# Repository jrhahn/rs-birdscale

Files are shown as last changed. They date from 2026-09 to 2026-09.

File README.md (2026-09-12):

# rs-smarthome-nodes

Async `no_std` Rust ([Embassy](https://embassy.dev)) firmware for a fleet of
**Seeed Studio XIAO ESP32-C3** smart-home sensor nodes. One image serves every
node: `NODE=<name>` at build time selects which sensors are populated, what the
node is called, and whether it runs on battery (deep sleep) or mains (always
on). Home Assistant picks the nodes up automatically over **MQTT
auto-discovery** — no hand-declared entities.

It started as a battery bird-feeder scale, which is still the default node
(`NODE=terrasse`): on each wake-up it reads a load cell via an HX711 amplifier
and compares it against a tare baseline kept in RTC RAM. While the feeder is
empty it polls every couple of seconds from **light** sleep — no radio, and no
cold boot per poll — which bounds how short a visit it can see at all. The
amplifier is powered down between those polls, and its settling time after
power-up is waited out asleep rather than awake. Once weight crosses the threshold it
stops sleeping and **watches the visit through awake**, so the published weight
is a settled median rather than whichever conversion happened to land first, and
the visit gets a real duration instead of one rounded to the sleep interval;
then it brings up Wi-Fi and publishes once (grams converted on-device). A
periodic **heartbeat** (default every 10 min) publishes anyway, so
Home Assistant always has a fresh reading. While online it also pulls any
retained calibration/tuning back from Home Assistant and persists it to flash.

```
┌──────────┐  bit-bang   ┌────────┐    Wi-Fi/MQTT (grams, °C)   ┌────────────────┐
│  Load    │────────────▶│ HX711  │──▶ ESP32-C3 ───────────────▶│ Home Assistant │
│  Cell    │  DT / SCK   │ 24-bit │       smarthome/terrasse/weight    │                │
└──────────┘             └────────┘   ◀── config/* (retained) ──│  (calibration) │
   DS18B20 ─ 1-Wire ─────────────────▶     grams + tuning       └────────────────┘
   SHT31-D / SCD41 ─ I²C ────────────▶  homeassistant/… (discovery, retained)
   SDS011 ─ UART ────────────────────▶
```

## The fleet

Pick a node with `NODE=` at build time (`src/node.rs`); an unknown name fails
the build rather than flashing the wrong personality onto a board. A board can
also be **provisioned** to another identity afterwards, without a rebuild — see
[below](#provisioning-a-board).

| `NODE=` | Room | Sensors | Power |
| --- | --- | --- | --- |
| `terrasse` (default) | Terrasse | HX711 load cell + SHT31-D + cell voltage | battery, deep sleep |
| `schlafzimmer` | Schlafzimmer | SCD41 + SHT31-D | mains |
| `wohnzimmer` | Wohnzimmer | SCD41 + SHT31-D + SDS011 + SGP41 | mains (fan) |
| `kueche` | Küche | SHT31-D | mains |
| `bad` | Bad | SHT31-D | mains |
| `terrasse` | Terrasse | none yet — the board is on the network while it is wired up | battery, deep sleep |

### Provisioning a board

The `NODE=` value is only the identity a board *starts* with. To repurpose one —
or to flash the whole fleet with a single image and sort out which is which
afterwards — publish its node name **retained** to the board's provisioning
topic, which is keyed by MAC (the one name a board knows before it knows
anything else) and printed on every boot:

```
node 'terrasse' (Terrasse) booted, battery profile
provision topic: smarthome/provision/a1b2c3d4e5f6
```

```bash
# Tell that board it is the kitchen node
mosquitto_pub -h <broker-ip> -r -t smarthome/provision/a1b2c3d4e5f6 -m kueche

# …and back to whatever it was flashed as
mosquitto_pub -h <broker-ip> -r -t smarthome/provision/a1b2c3d4e5f6 -m default
```

The node picks the message up the next time it is online for a publish, stores
the name in flash and restarts into it — the sensor set decides which buses come
up, so becoming a different node means a reboot. The message being retained is
the point: a battery node that is asleep gets it whenever it next wakes. It is
re-delivered on every connect, so the firmware only writes flash when the value
actually changes, and an unknown name is logged and ignored rather than obeyed.

The identity lives in its own flash sector, separate from the calibration blob —
provisioning a board never disturbs its tare or scale factor.

**Power profiles** decide the loop: *battery* nodes cold-boot out of deep sleep,
measure, publish only when there is something to say, and sleep again. *Mains*
nodes stay associated and sample on a fixed per-node cadence — CO₂ continuity
and the SDS011's duty-cycled fan both rule out deep sleep. A sensor whose own
cadence is slower than the node's round says so per slot (`Slot::every`), which
is how `wohnzimmer` reads CO₂ every minute while its fan runs four times an
hour. On a battery node the
`config/deep_sleep` switch can still hold it awake for bench testing.

## Hardware

| Component | Detail |
| --- | --- |
| MCU | Seeed XIAO ESP32-C3 (RISC-V, external Wi-Fi ant.)  |
| Battery | 2000 mAh LiPo via the XIAO's onboard charger |
| Sensor | 1 kg straight-bar load cell (tension S-config) |
| Amplifier | HX711 24-bit ADC |
| Temperature | DS18B20 waterproof 1-Wire probe (stainless steel) |
| T / RH | SHT31-D breakout, I²C `0x44` |
| Cell voltage | 100 kΩ/100 kΩ divider + 100 nF on ADC1 |
| CO₂ / T / RH | SCD41 breakout, I²C `0x62` |
| PM2.5 / PM10 | SDS011, UART 9600 8N1, **5 V supply** (fan) |

### Pin map (XIAO ESP32-C3 silkscreen → GPIO)

| Pad | GPIO | Use |
| --- | --- | --- |
| D0  | 2  | HX711 SCK |
| D1  | 3  | HX711 DT |
| D2  | 4  | DS18B20 1-Wire (4.7 kΩ pull-up to 3V3) **or** battery divider tap (ADC1) |
| D3  | 5  | SDS011 UART RX ← sensor TX |
| D4  | 6  | I²C SDA (SHT31-D + SCD41) |
| D5  | 7  | I²C SCL |
| D10 | 10 | SDS011 UART TX → sensor RX |

The two I²C sensors share one bus (their addresses do not clash), and on
`wohnzimmer` that bus runs alongside the SDS011's UART — the only node using
both. The SDS011 deliberately avoids D6/D7 (GPIO21/20), which are the console
UART pads the log output uses.

D2 has two possible jobs and can only do one of them: the DS18B20's 1-Wire line,
or the battery divider's tap. ADC2 is unusable while Wi-Fi is up, and of the
ADC1 pins only D0/D1/D2 are broken out on this board — the first two are the
HX711's — so cell voltage costs the probe its pin. `NODE=terrasse` takes that
trade; the build fails if a node table entry ever asks for both.

### Wiring (load cell → HX711)

The four load-cell leads go to the HX711's **input** side. Colours follow the
common straight-bar convention — verify against your cell's datasheet, as they
do vary.

| Load-cell lead | HX711 pin | Meaning |
| --- | --- | --- |
| Red | E+ | excitation + |
| Black | E− | excitation − |
| Green | A+ | signal + |
| White | A− | signal − |

> If loading the cell makes the reading go *down* instead of up, swap A+/A− (or
> flip the comparison in firmware — the threshold itself is the runtime
> `threshold` config value, see below).

### Wiring (HX711 → XIAO ESP32-C3)

On the XIAO ESP32-C3 the silkscreen pads map **D0 = GPIO2, D1 = GPIO3,
D2 = GPIO4** (GPIO0/GPIO1 are *not* broken out on this board).

| HX711 pin | ESP32-C3 pin | Direction |
| --- | --- | --- |
| VCC | 3V3 | — |
| GND | GND | — |
| SCK (clk) | GPIO2 / D0 | output |
| DT (data) | GPIO3 / D1 | input |

### Wiring (DS18B20 → XIAO ESP32-C3)

The probe's three leads are the usual DS18B20 colours. The data line is an
**open-drain 1-Wire bus** and needs a **4.7 kΩ pull-up from DATA to 3V3**
(the MCU's weak internal pull-up is enabled as a backup, but the external one
is required for a reliable read over the ~1 m cable).

| DS18B20 lead | ESP32-C3 pin | Direction |
| --- | --- | --- |
| Red (VCC) | 3V3 | — |
| Black (GND) | GND | — |
| Yellow (DATA)  | GPIO4 / D2 | 1-Wire (+ 4.7 kΩ to 3V3) |

The temperature is read whenever a weight reading is being published — on a bird
visit, and on the periodic **heartbeat** (see below) — so the ~750 ms conversion
never runs on the low-power idle-poll cycles. It is published to
`smarthome/terrasse/temperature` in °C.

**No node ships with this today.** The outdoor node traded its probe for the
battery sense below; the DS18B20 slot and driver stay, because the pin is a
per-node choice rather than a firmware one.

### Wiring (battery divider → XIAO ESP32-C3)

The XIAO charges a cell but cannot measure one: `B+` reaches the charger and the
regulator, never an ADC. An external divider from the battery rail to ground
gives ADC1 something to read.

| Component | From | To |
| --- | --- | --- |
| R1 100 kΩ | XIAO `B+` | tap |
| R2 100 kΩ | tap | XIAO `GND` |
| C 100 nF | tap | XIAO `GND` |
| wire | tap | GPIO4 / D2 |

Two details are not optional. The divider's foot goes to the **XIAO's ground**,
which on a node with a 1S protection board is the `P−` (load) side — there the
board's cutoff switches the divider off with everything else, where wiring it
straight to the cell's own `B−` would keep drawing ~21 µA past the cutoff and
deep-discharge the pack the protection was fitted to save. And the DS18B20's
4.7 kΩ pull-up must come **off** the pin: it would drag the tap towards 3V3.

Conversions are calibrated against the chip's eFuse reference, so the driver
works in millivolts; the divider ratio is undone in
[`src/battery.rs`](src/battery.rs). That corrects the ADC, not the resistors —
use 1 % parts, and trim `R_TOP_KOHM` / `R_BOTTOM_KOHM` and reflash if a
multimeter disagrees. Published to `smarthome/terrasse/battery_voltage` in volts. Below
3.0 V the log says so: the common DW01A-class protection board does not cut off
until ~2.4 V, far past where a LiPo starts losing capacity for good.

## Enclosure

[`models.py`](models.py) is the CadQuery source for the printed parts: four
enclosures in eight pieces, plus the two bending-beam clamps the bird scale hangs
from. The clamps the file *started* as were retired in `f858d60` and are not
these — `git show d0df819:models.py` still has the originals, which put the wire
hole where the bar puts it rather than on the box's centre line.

```bash
nix develop .#cad        # separate shell: OpenCASCADE is ~500 MB, cargo has no use for it
python models.py         # writes cad-models/*.stl and *.step
```

CadQuery is not in nixpkgs (only the `opencascade-occt` kernel, without the
Python bindings), so the shell pins the wheels and installs them into
`.venv-cad` on first entry (ignored). The exports under `cad-models/` are
tracked, so printing a part does not require the toolchain at all — `.stl` to
slice, `.step` to open in CAD.

### `terrasse_body` + `terrasse_floor`

An **88 × 78 × 60 mm** box for the bird scale, in two parts. The size is not a
choice — it comes from the measured envelopes, plugs included:

| | | | |
|---|---|---|---|
| ESP32-C3 board | 40 × 30 × 35 | HX711 board | 40 × 25 × 30 |
| battery | 65 × 50 × 10 | SHT31 | 20 × 10 × 10 |

That is 128 cm³ with clearance. The first version of this box had a 98 cm³
interior, so no amount of rearranging would have done it; a grid packing search
puts the smallest interior that takes all four at 76 × 66 × 52, and only with
everything stood on end. This one is 80 × 70 × 55, which leaves room for the
mounts themselves.

The design follows from it hanging outdoors in the rain:

- **The roof has no seam and no penetration.** The box is a cup opening
  *downward*; the only joint faces the ground, where water cannot climb to it.
  The top 5 mm flare 2 mm past the walls as an eave, so water crossing the roof
  drips clear instead of running down the sides. Nothing is drilled through the
  top — the cord attaches to two round-ended tabs *outboard* of the walls,
  which is why the part reaches 108 mm across.
- **The SHT31 lives in the −X/−Y corner, no longer behind a wall.** Air enters
  through floor slots beneath it and leaves through slots high in *both*
  adjacent walls, tilted 30° down-and-out — every opening faces down or
  outward-down, so there is still a local draught across the sensor.

  There *was* a baffle around it, and it came out because the cable could not
  be got past it during assembly: the slot was widened, then run full height,
  and it still fouled. That costs accuracy, since the board's heat now shares
  the sensor's air — about 0.9 °C on the bedroom node. A box that cannot be
  assembled is worse than one that reads half a degree warm, but keep the SHT31
  in that corner rather than beside the board, or the loss compounds.
- **The floor screws go into M3 heat-set inserts**, Ø4 bores in 9 mm posts,
  which leaves 2.5 mm of wall — thinner than one would choose, and what the
  already-printed floor plate allows.

  The screw positions are not free: they are where the 8 mm post this box
  shipped with put them, and the plate in hand has its countersinks there. So
  the post has to grow *around* a fixed hole, and it meets two features of that
  same plate — the cell reaches x = 31 and the battery guides reach y = ±26.
  Nine millimetres leaves 0.5 mm to both; ten does not fit. The plate's HX711
  rib still fouled one post by 0.5 mm, so that post is relieved there rather
  than shrunk: the rib only has to slide past, the wall has to survive brass
  being melted into it. Warm the inserts properly and do not lean on them; if
  one splits, the way out is a reprinted floor with the holes further in, which
  buys 3.5 mm.
- **The load hangs off a pad on the underside of the floor**, matching the
  clamp's 25 × 12 face and its screw pitch, with captive nuts reachable from
  inside the box.

### `terrasse_beam_spacer` + `terrasse_beam_hanger`

The two clamps that pad exists for. The **spacer** bolts up into the floor's
captive nuts and carries the bar's fixed end; the **hanger** grips the load end,
and the wire leaves from its far end.

Two parts rather than one, because both ends of the bar share the anchor's 15 mm
screw pitch — a single pair of screws cannot fasten the box and the bar at once.
The spacer offsets the fixed end until the pairs clear. `BEAM_DIR` decides which
way the bar runs from there; flipping its sign mirrors the whole assembly, and
since every feature sits on `y = 0`, an already-printed part just turns round.

The hanger is 80 mm, the bar's own length, with the M5 bolts at one end and the
wire hole at the other, **61.5 mm apart**. The wire leaving from the far end is
a requirement — it is where the feeder hangs — and the section is dimensioned
for it rather than around it.

What follows is a cantilever in the load path, which is why the **spine** is the
deep part at 14 mm and not the pad: stiffness goes with depth cubed. Deflection
here is an accuracy problem rather than a strength one — what bends does not
spring back exactly, and that shows up as hysteresis in the weight. If readings
ever differ between a loaded and an unloaded pan, deepen `RAIL_T` before
suspecting anything in the firmware.

> **Nothing but the bar may bridge the two clamps.** Only the hanger's pad
> touches the bar; the spine runs 4 mm clear of it along its whole length and
> 16.7 mm clear of the spacer. If anything touches, the load path goes around
> the strain gauges and the scale reads a fraction of the weight — or none of
> it — without any sign that something is wrong.

**Printing.** The pad reaches down to the rail's underside rather than standing
proud of it, so there is one flat face across all 80 mm and a single 4 mm step
on top — a step *up*, overhanging nothing. The only downward faces off the bed
are the two counterbore ceilings, 112.9 mm² of bridge over a 5.3 mm hole. No
support. The pad is 18 mm thick as a result, so the bolts want to be **M5 × 16**.

Calibrate in the fixture: `scale_factor` is what absorbs whatever the mounting
does to the sensitivity.

## Wi-Fi credentials without a rebuild

A board that cannot join the network cannot be told anything over the network,
so the way in is the serial console. On a **cold boot** — power actually removed
and reapplied, not a deep-sleep wake and not a reflash — the firmware listens
briefly:

```
wifi: 'your-ssid' (built in)
wifi: no usable credentials; waiting for the console
wifi provisioning: ssid <name> / psk <passphrase> / save / clear / show / done
```

Type into the same serial monitor you are watching the logs in:

```
ssid MyNetwork
psk correct horse battery staple
save
```

The board stores them in its own flash sector — separate from the calibration
and the node identity — and restarts into them. `clear` forgets them and returns
to the credentials the image was built with; `show` reports the SSID and the
passphrase's length (never its content); `done` carries on booting.

The window is 3 s when the board already has usable credentials, and 2 minutes
when it has none, since then it has nothing else to be doing. A passphrase may
contain spaces. If stored credentials are refused three times in a row, the
board falls back to the build-time pair for the rest of that run, so a typo
cannot strand it permanently.

## Tests

A firmware binary for `riscv32imc` cannot host a test harness, so the crate is
split: [`src/lib.rs`](src/lib.rs) holds everything the binary is made of, and
the parts that are **pure computation** — frame decoding, CRCs, the flash blob
layouts, `Config::apply`, the discovery payloads, the node table — build without
the HAL and therefore run on the host.

```bash
# What CI runs
cargo test --no-default-features --features host-tests \
    --target x86_64-unknown-linux-gnu
```

The sensor drivers themselves are covered too. They are generic over the
`embedded-hal-async` / `embedded-io-async` bus traits, so
[`src/sensors/mock.rs`](src/sensors/mock.rs) can feed the *real* SHT31, SCD41
and SDS011 drivers a scripted bus: canned I²C replies, and a UART that hands
over stale frames, falls quiet, then delivers the frame that matters. That
covers the resync, the CRC rejection, the fan duty cycle, the SCD41's two run
modes and its data-ready handshake, and what happens when a sensor is absent —
but not timing, bus contention or anything electrical, which stay bench
questions.

Anything that touches the chip itself — RTC RAM, flash, the radio, the bit-bang
drivers — sits behind the `hal` feature (on by default), so a normal
`cargo build` is unaffected. Compile-time
`const _: () = assert!(…)` checks stay where they are: they cost nothing and
fail the *build*, which is stronger than a test — the tests cover what
const-eval cannot reach, such as anything that formats a string, negative cases,
and inputs enumerated in a loop.

[CI](.github/workflows/ci.yml) runs the tests, both clippy passes, and builds
every node in the fleet — plus a check that a mistyped `NODE=` still fails the
build.

## Home Assistant integration

Each node **announces itself**: on the first connect after a power-up it
publishes one retained config message per reading to
`homeassistant/sensor/<node>/<key>/config`, so Home Assistant creates the device
and its entities without any YAML. Values are ready to use — grams, °C, %, ppm,
µg/m³ — with no template maths.

| Node | State topics |
| --- | --- |
| `terrasse` | `smarthome/terrasse/weight`, `/temperature`, `/humidity` (SHT31-D), `/battery_voltage` — each appearing as its slot is switched on |
| `schlafzimmer` | `smarthome/schlafzimmer/co2`, `/temperature`, `/humidity` (SHT31-D), `/scd41_temperature`, `/scd41_humidity` |
| `wohnzimmer` | the same five, plus `/pm25`, `/pm10` (humidity-corrected), `/pm25_raw`, `/pm10_raw` and `/voc_index`, `/nox_index` |
| `kueche` / `bad` | `smarthome/<node>/temperature`, `/humidity` |

No node mirrors a weight to a second topic any more. The outdoor node used to,
under `birds/scale/state`, for hand-declared entities that predated discovery.
That topic and the whole `birds` namespace went when it was renamed to
`terrasse`.

**Availability.** A mains node registers an MQTT last will, so the broker
publishes retained `offline` to `<namespace>/<node>/status` the moment its
connection breaks (and the node publishes `online` on connect, disconnecting
cleanly at the end of a round so a normal publish is never mistaken for a
death). Battery nodes get no will — they are supposed to be offline between
readings — so every node also carries `expire_after` in its discovery config:
three missed publish rounds and Home Assistant invalidates the values.

The tuning/calibration knobs are *commands* rather than readings, but they are
discovered too — as `number`, `switch` and `button` entities in the device's
*Configuration* section — so a node needs no hand-written Home Assistant YAML at
all. See [`home-assistant/README.md`](home-assistant/README.md).

### Configure & calibrate from Home Assistant

Calibration (`offset`, `scale_factor`) and tuning (`threshold`, poll intervals)
are **stored on the controller in flash** and set from Home Assistant — no
reflashing. HA publishes each value **retained** to
`<namespace>/<node>/config/<key>` (`smarthome/terrasse/config/<key>` for the scale);
the firmware reads them the next time it is online for a publish (while a bird is
on / has just left the scale) and persists them. Changes therefore apply with a
**short delay**, not instantly.

| HA entity → topic (`smarthome/terrasse/config/…`) | Meaning | Node |
| --- | --- | ---- |
| `offset` | raw HX711 value at 0 g (tare zero) | with load cell |
| `scale_factor` | raw ticks per gram | with load cell |
| `threshold` | grams that count as "a bird landed" | with load cell |
| `tare` (button) | re-zero: adopts the current empty baseline as `offset` | with load cell |
| `idle_interval` | deep-sleep seconds while empty | battery |
| `active_interval` | deep-sleep seconds for a load that outlasted its awake visit window (snow, a twig) — a normal visit is watched awake and never uses this | battery |
| `heartbeat_interval`| seconds between periodic temp + weight publishes with no visitor (default 600) | battery |
| `deep_sleep` (switch)  | `0` = stay awake with Wi-Fi up (bench testing on USB), `1` = normal battery deep sleep | battery |
| `scd41_temp_offset` | °C the SCD41 subtracts for its own self-heating (default 4.0) | with SCD41 |
| `sds011_kappa` | κ for the PM humidity correction, `0` disables it (default 0.25) | with a compensated SDS011 |

Only the knobs that do something on a given node are announced: a mains node
samples on its build-time cadence and never sleeps, so it gets none of them.
Pressing **Tarieren** publishes a retained press (the node may be asleep) which
the firmware deletes once it has re-zeroed, so it is never replayed as a second
tare.

On a blank flash the firmware falls back to built-in defaults
(`src/config.rs` — `offset` mid-scale, `scale_factor` 420, `threshold` 10 g,
2 s / 10 s idle/active intervals, 600 s heartbeat).

**Calibrating `scale_factor`:**
1. **Tare** with the pan empty (sets `offset`). The empty-pan raw value is also
   visible in the serial monitor (`HX711 raw reading: N`).
2. Place a known mass `m` and read the published grams / raw value.
3. `scale_factor = (raw_loaded − offset) / m`; enter it in the *Kalibrierfaktor*
   number. Re-check and adjust until the reading matches.

## Long-term history

Home Assistant sees every node the moment it publishes, and keeps a recorder
database — tuned for weeks. The questions this fleet was built for are slower
than that: did insulating the roof change the bedroom's overnight CO₂, how does
the terrace swing between summers, is the feeder busier this year than last.

[`timeseries/`](timeseries/README.md) is a second consumer on the same broker
whose only job is not to lose anything. It follows the topics the nodes already
publish, writes each reading into **QuestDB** with a **three-year retention**,
maintains three cascading rollup views (`_1m` → `_1h` → `_1d`) so a year-wide
chart reads thousands of rows instead of millions, and serves a small dashboard
that routes each query to the coarsest view still fine enough to answer it.

```bash
nix develop .#timeseries
cd timeseries && cargo run -- timeseries.example.toml   # then http://127.0.0.1:8087
```

It changes nothing about the firmware or the Home Assistant side — a node does
not know it is being archived. The flake carries a package and a NixOS module
(which brings up QuestDB too, since nixpkgs ships the package but no service)
for the home server; see [`timeseries/README.md`](timeseries/README.md) for the
schema, the rollup reasoning, and how to deploy it.

## License

MIT — see [LICENSE](LICENSE).

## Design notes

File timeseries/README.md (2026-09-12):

# `smarthome-timeseries`

The fleet's long-term memory: one process that follows the MQTT topics the
nodes already publish, writes every reading into **QuestDB** with a **three-year
retention**, and serves a small dashboard that reads it back.

```
┌──────────┐   smarthome/<node>/<key>   ┌───────────────┐   ILP/HTTP   ┌──────────┐
│  nodes   │───────────────────────────▶│   this        │─────────────▶│ QuestDB  │
│ (ESP32)  │   homeassistant/…/config   │   service     │◀── SQL ──────│ readings │
└──────────┘───────────────────────────▶│               │              │ + 3 views│
                                        └───────┬───────┘              └──────────┘
      ┌────────────────┐                        │  HTTP :8087
      │ Home Assistant │◀── same broker ────────┘  charts, live values, health
      └────────────────┘
```

Nothing here touches the firmware or Home Assistant's configuration. A node does
not know it is being archived; switching this off leaves the house working
exactly as before.

## Why it exists

Home Assistant already sees every node — the firmware announces itself over MQTT
auto-discovery — and it keeps a recorder database. What it does not keep is
*years*. Its recorder is tuned for weeks, and the questions this fleet was built
to answer are the slow ones: did insulating the roof change the bedroom's
overnight CO₂, how does the terrace swing between summers, is the bird feeder
busier this year than last.

So: a second consumer on the same broker, whose only job is not to lose
anything.

## What it stores, and what it does not

The firmware's topic layout is the entire schema:

| Topic | Stored as |
| --- | --- |
| `smarthome/<node>/<key>` | a row in `readings` |
| `smarthome/<node>/status` | a row in `node_status`, **on change only** |
| `smarthome/<node>/config/<key>` | nothing — a setting, not an observation |
| `smarthome/provision/<mac>` | nothing — an instruction |
| `homeassistant/sensor/<node>/<key>/config` | nothing; read for units and names |

Two details that are easy to get wrong, and are tested:

- **`provision` is not a node.** `smarthome/provision/a1b2c3d4e5f6` has the same
  three segments as a reading, and would otherwise be archived as a node called
  `provision` with a sensor called `a1b2c3d4e5f6`.
- **A retained reading is not a new reading.** The broker replays retained
  messages when this service subscribes, and the only timestamp available here
  is "now" — so a replay would stamp an old value as current. Readings arriving
  with the retain flag are skipped. This does not affect live publishes: MQTT
  clears the flag on messages delivered to an already-subscribed client, so a
  node publishing retained data is still archived normally.

Timestamps are when the bridge received the message. The nodes send none of
their own — they are `no_std` boards without a clock — and on a broker on the
same LAN the gap is milliseconds.

## The database

```sql
readings(timestamp TIMESTAMP, node SYMBOL, sensor SYMBOL, value DOUBLE)
  TIMESTAMP(timestamp) PARTITION BY DAY TTL 3 YEARS
```

plus three cascading materialized views, each aggregating the next finer one:

| View | Bucket | Reads | Partition |
| --- | --- | --- | --- |
| `readings_1m` | 1 minute | `readings` | day |
| `readings_1h` | 1 hour | `readings_1m` | month |
| `readings_1d` | 1 day | `readings_1h` | year |

Each stores `min`, `max`, `sum` and `count` per channel per bucket. The mean is
re-derived at read time as `sum(sv)/sum(n)` — the exact mean of the underlying
readings, not an average of averages that would weight a sparse hour (node
asleep, one reading) like a full one.

**Why cascade.** QuestDB refreshes a view by re-aggregating the buckets the new
rows touched. A daily view built directly on the base table therefore re-scans
the whole current day on every commit, for ever. Built on the hourly view it
re-reads twenty-four rows per channel.

**Why not timers.** The gateway firmware puts its coarse tiers on `REFRESH EVERY
5m` / `1h`, because at 100 Hz ingest an immediate refresh of every tier is what
pegged three CPU cores. This fleet publishes about one reading a minute per
channel, so there is nothing for a timer to save — and on QuestDB 9.3.5 a
timer-refreshed view created over a source that was still empty did not pick up
2160 rows inserted into that source over the following twenty minutes. That is
exactly the shape of a first install. Every tier here is `REFRESH IMMEDIATE`.

**Retention** is a QuestDB table TTL, applied to the base table and to every
view, and re-applied on each start — so changing `retention` in the settings
file is enough to change it on a table that already exists. QuestDB drops data a
whole partition at a time, which is why the setting must be a whole number of
days or coarser.

## Reading it back

`GET /api/series?node=…&sensor=…&from=…&to=…&points=…` picks a bucket from a
fixed ladder (1s … 30d), then routes the query to the **coarsest view whose
bucket is still fine enough**. Below a minute, and whenever a view is missing,
it reads the base table. The response is identical either way — `lo`, `hi`, `av`
per bucket — so the chart never branches on where the numbers came from.

Two things make that promise literal rather than approximate:

- The window is **widened to whole buckets** before querying. Ask for "the last
  365 days" at a daily grain and the window starts mid-day: the raw table would
  answer with a partial first bucket while the daily view's row for that day
  starts before the window and is filtered out entirely. Rounded out, both
  answer with the same full bucket.
- A rollup that returns nothing is **retried against the base table**, so a view
  that is somehow behind shows the truth rather than a blank chart.

This is checked against a live database rather than asserted: see the smoke test
below, which compares every zoom level against a full scan of the raw table.

| Endpoint | |
| --- | --- |
| `GET /` | the dashboard (three embedded files, no CDN, no build step) |
| `GET /api/channels` | every channel, with unit, display name and last value |
| `GET /api/series` | one chart |
| `GET /api/health` | broker and database reachability, rollups, counters |

## Configuration

One TOML file, every field optional — see
[`timeseries.example.toml`](timeseries.example.toml). Defaults assume a broker
and a QuestDB on localhost. Passwords can come from `password_file` so they stay
out of the file (and, on NixOS, out of the store).

## Building and running

The firmware's toolchain pin does not apply here; this crate has a
`rust-toolchain.toml` of its own and a `.cargo/config.toml` that undoes the
riscv32 default.

```bash
nix develop .#timeseries      # nixpkgs rustc, plus questdb and mosquitto
cd timeseries
cargo test                    # 75 tests, no database needed
cargo clippy --all-targets -- -D warnings
cargo run -- timeseries.example.toml
```

### The end-to-end smoke test

The unit tests cover the parts that are pure computation — topic classification,
ILP formatting, DDL shape, tier routing, bucket snapping. What they cannot cover
is whether QuestDB accepts any of it. That needs a real database:

```bash
# a QuestDB and a broker of their own, on ports nothing else uses
mkdir -p /tmp/ts-smoke/qdb/conf
cat > /tmp/ts-smoke/qdb/conf/server.conf <<'EOF'
http.bind.to=127.0.0.1:19000
http.min.net.bind.to=127.0.0.1:19003
pg.net.bind.to=127.0.0.1:18812
line.tcp.net.bind.to=127.0.0.1:19009
EOF
questdb.sh start -n -d /tmp/ts-smoke/qdb &
printf 'listener 11883 127.0.0.1\nallow_anonymous true\n' > /tmp/ts-smoke/mosquitto.conf
mosquitto -c /tmp/ts-smoke/mosquitto.conf &

# then point a settings file at 11883 / 19000 and run the service against it,
# publish with mosquitto_pub, and compare a rollup-answered chart against a
# full scan of the base table.
```

Doing exactly that is what turned up the two edge cases the code now handles
(partial buckets at a window's edge, and coarse views left empty by a timer).

## On the home server

The flake exposes a package and a NixOS module. The module also brings up
QuestDB itself, because nixpkgs ships the package but no service:

```nix
{
  inputs.smarthome-nodes.url = "github:jrhahn/rs-smarthome-nodes";

  # in the host's configuration:
  imports = [ inputs.smarthome-nodes.nixosModules.smarthome-timeseries ];

  services.smarthome-timeseries = {
    enable = true;
    settings = {
      mqtt.host = "127.0.0.1";       # the broker Home Assistant already uses
      questdb.retention = "3y";
      web.bind = "127.0.0.1:8087";
    };
    # Kept out of the store; systemd hands it over as a credential.
    mqtt.passwordFile = "/run/secrets/mqtt-password";
  };
}
```

The archiver runs as a `DynamicUser` with no state of its own. QuestDB gets a
static user and `/var/lib/questdb`, which is **the one directory worth backing
up** — it holds the data, the write-ahead log and the configuration.

Both QuestDB ports bind to loopback by default. That is deliberate: QuestDB's
HTTP interface serves ingestion, arbitrary SQL *and* a web console, none of it
authenticated.

> **Upgrades are one-way.** QuestDB's storage format only moves forward: a data
> directory written by one version cannot be opened by an older one, so rolling
> the package back after an upgrade does not roll the data back with it.

## Operations

**Change the retention.** Edit `questdb.retention`, restart. The service issues
`ALTER TABLE … SET TTL` on every start, for the base table and for every view.

**Look at the data directly.** QuestDB's console is on port 9000 (loopback, so
over an SSH tunnel), and the PostgreSQL wire protocol on 8812 for anything that
speaks it — Grafana, `psql`, a notebook.

**After changing a view's definition** in `rollup.rs` or `schema.rs`: the DDL is
`IF NOT EXISTS`, so an existing view is left alone. Drop the affected views
(coarsest first) and restart; they backfill from the history on creation.

```sql
DROP MATERIALIZED VIEW readings_1d;
DROP MATERIALIZED VIEW readings_1h;
DROP MATERIALIZED VIEW readings_1m;
```

**If a view is ever behind**, `REFRESH MATERIALIZED VIEW readings_1h INCREMENTAL`
catches it up without a full rebuild. `SELECT view_name, view_status,
refresh_base_table_txn, base_table_txn FROM materialized_views()` is how to tell.

## How long to keep it, and what that costs

Measured rather than guessed, and written up in
[`docs/long-term-history.md`](../docs/long-term-history.md): the fleet produces
~25,900 readings a day, a finished daily partition of exactly that shape came to
**828 KB**, and three years of raw data is therefore under a gigabyte. That page
also argues why the rollups should outlive the raw table rather than expire with
it, and what threatens a long series once storage has stopped being the problem.

## Limits worth knowing

- **Readings are lost if the database is unreachable for a long time.** The
  writer retries a failed batch on the next flush and keeps up to 100 000 rows
  buffered — over a day of this fleet's output — then drops the backlog with a
  loud log line rather than growing until the machine swaps.
- **No authentication on the dashboard.** It is read-only and binds to
  loopback; anything more is the reverse proxy's job.
- **The service does not create the MQTT user.** It is a normal client; give it
  read access to `smarthome/#` and `homeassistant/#`.

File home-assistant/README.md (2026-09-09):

# Home Assistant

**Nothing here needs merging into `configuration.yaml` any more.**

Every node announces itself over retained MQTT discovery on its first connect
after a power-up — both directions:

- the **readings** become `sensor` entities (weight, temperature, humidity, CO₂,
  PM2.5/PM10);
- the **calibration and tuning knobs** become `number` / `switch` / `button`
  entities, filed under the device's *Configuration* section.

Adding a node to the fleet therefore needs no change on the Home Assistant side
at all. The only requirement is the MQTT integration with discovery enabled (the
default) on the `homeassistant/` prefix.

## What each node exposes

Controls are per node, so nothing dead shows up on a device card:

| Control | Entity | On which node |
| --- | --- | --- |
| `threshold` | number, g | nodes with a load cell (`terrasse`) |
| `scale_factor` | number | nodes with a load cell |
| `offset` | number | nodes with a load cell |
| `tare` | button | nodes with a load cell |
| `idle_interval` | number, s | battery nodes |
| `active_interval` | number, s | battery nodes |
| `heartbeat_interval` | number, s | battery nodes |
| `deep_sleep` | switch | battery nodes |

The mains nodes have no tunables today: their sampling cadence is a build-time
per-node value (`sample_secs` in `src/node.rs`) and they never sleep.

**Changes apply with a delay.** The controls publish **retained** to
`<namespace>/<node>/config/<key>`, and the firmware only reads that topic while
it is online for a publish — on the scale, the next bird visit or heartbeat. The
broker holds the value until then; the node persists it to flash once it has it.

The controls also *read their state back off their own command topic*, which is
why they show the last value you set even after a Home Assistant restart. They
show what was last commanded, which is not proof the node has picked it up yet.

## Calibrating the scale

Two points, in this order:

1. **Zero.** With the pan empty, press **Tarieren**. The node adopts its current
   empty baseline as `offset` on its next online cycle. (`offset` is also
   editable by hand, if you would rather type the raw HX711 value.)
2. **Span.** Put a known weight on the pan and wait for a reading. If it shows
   `w_shown` grams instead of the true `w_true`, multiply `scale_factor` by
   `w_shown / w_true` and set the result. Repeat once if it is still off.

`scale_factor` is raw HX711 ticks per gram, so it is only valid for the exact
mechanical mounting it was calibrated on — re-do the span after any change to
the load cell's fixture. The zero drifts with temperature and creep, so re-tare
occasionally; the firmware also tracks slow baseline drift by itself.

## Example dashboard card

Add to a dashboard (Raw configuration editor). Entity ids follow from the node
name Home Assistant assigns the device — adjust if yours differ. The `title:`
lines are just card headings, not entities: if one turns up in a dashboard and
is not wanted, it is this YAML that put it there, not the firmware.

```yaml
type: vertical-stack
cards:
  - type: entities
    title: Vogelwaage
    entities:
      - entity: sensor.terrasse_gewicht
      - entity: sensor.terrasse_temperatur
      - entity: sensor.terrasse_luft_temperatur
      - entity: sensor.terrasse_luft_luftfeuchtigkeit
  - type: entities
    title: Kalibrierung
    entities:
      - entity: button.terrasse_tarieren
      - entity: number.terrasse_kalibrierfaktor
      - entity: number.terrasse_tara_offset
      - entity: number.terrasse_ausloseschwelle
  - type: history-graph
    hours_to_show: 24
    entities:
      - entity: sensor.terrasse_gewicht
```

## Migrating from the hand-declared YAML

This directory used to hold a `configuration.yaml` fragment with the `mqtt:`
number/switch blocks and a `birdscale_tare` script. To move off it:

1. Delete that block (and the script) from your `configuration.yaml`, plus the
   old hand-declared `birds/scale/state` and `birds/scale/temperature` sensors,
   and restart Home Assistant. The old entities are gone; the discovered ones —
   with different entity ids — have already appeared.
2. Fix up any dashboard cards and automations that named the old entities.
3. The firmware's mirror of the weight to `birds/scale/state` is **already
   gone**: the node was renamed from `draussen` to `terrasse` and moved to the
   fleet's own `smarthome/terrasse/…` namespace, which retired the whole `birds`
   prefix along with it. `legacy_weight_topic` in `src/node.rs` is now unused by
   every node.

The old tare script published a retained timestamp to
`birds/scale/config/tare`. That topic is no longer subscribed to — the node
listens on `smarthome/terrasse/config/#` now — so a leftover retained message
under the old prefix will sit on the broker until it is cleared by hand:

```bash
mosquitto_pub -h <broker> -t birds/scale/config/tare -r -n
```

The firmware still understands the tokens themselves on its current topic, and
clears the retained message once it has acted on it.

## Forcing a re-announce

You mostly should not have to. Discovery re-announces whenever **what it would
say changes**: the firmware hashes every topic and payload it is about to
publish and keeps that digest in RTC RAM (`discovery::announcement_tag`). Switch
a sensor on in `src/node.rs` and reflash, change a cadence, move a board to a
different node — the next connect notices and re-announces. Nothing changed
means nothing is sent, so a battery node spends no airtime on it.

That replaced a plain "have I announced yet" bit, which could only ever answer
*yes* — the one answer that cannot be checked. It was wrong for six days on the
living-room node: the bit was set while its SDS011 slot was still off, and after
the slot was switched on the four PM entities published to the broker with
nothing in Home Assistant subscribed to them. A reflash did not fix it, a reset
did not fix it, and neither did pulling the USB cable for several seconds — the
board's rails decay slower than the RTC domain forgets, so the bit came back
still set.

If you do want to force it, clear the digest by deleting the retained configs
and power-cycling, or simply change any tuning knob and change it back:

```bash
mosquitto_pub -h <broker-ip> -t 'homeassistant/sensor/<node>/<key>/config' -r -n
mosquitto_pub -h <broker-ip> -t 'homeassistant/number/<node>/<key>/config' -r -n
```

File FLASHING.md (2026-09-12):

# Building & flashing `rs-smarthome-nodes`

Preparing the firmware and getting it onto a Seeed XIAO ESP32-C3.

**TL;DR — you flash by just plugging the XIAO into USB-C.** The ESP32-C3 has a
built-in USB Serial/JTAG controller, so no external programmer or probe is
needed. See [§4](#4-flash-over-the-xiaos-native-usb-c-the-normal-way).

The Raspberry Pi Pico probe in [§5](#5-optional-flash-with-a-raspberry-pi-pico-picoprobe)
is **entirely optional** — only for when the native USB isn't usable (board
sealed in the enclosure, galvanic isolation, USB-JTAG disabled).

---

## 1. Prerequisites (one-time)

```bash
# Toolchain (pinned by rust-toolchain.toml, but install it explicitly once)
rustup toolchain install 1.83.0
rustup target add riscv32imc-unknown-none-elf --toolchain 1.83.0

# Flasher / monitor. espflash speaks the ESP ROM bootloader over any serial port.
cargo install espflash
```

> The XIAO ESP32-C3 is RISC-V, so it uses the stock bare-metal target —
> **no Xtensa `espup` toolchain is needed.**

## 2. Configure the build

Everything below is baked in at compile time (see [`.env.example`](.env.example);
`direnv` exports a local `.env` automatically):

| Setting | Where |
| --- | --- |
| **Which node** | `NODE` env var — decides the sensors, topics and power profile |
| Wi-Fi SSID / pass | `SSID` / `PASSWORD` env vars at build |
| MQTT broker | `MQTT_BROKER` env var (dotted IPv4) |
| MQTT credentials | optional `MQTT_USER` / `MQTT_PASSWORD` env vars |
| MQTT port | `MQTT_PORT` in [`src/main.rs`](src/main.rs) |

`NODE` is the important one — one image serves the whole fleet:

| `NODE=` | Sensors | Power |
| --- | --- | --- |
| `terrasse` (default) | the outdoor node and the bird scale; every slot off while it is wired up | battery, deep sleep |
| `schlafzimmer` | SCD41 + SHT31-D | mains |
| `wohnzimmer` | SCD41 + SHT31-D + SDS011 | mains |
| `kueche`, `bad` | SHT31-D | mains |

A typo fails the build rather than flashing the wrong personality onto a board:

```
error[E0080]: evaluation of constant value failed
  = the evaluated program panicked at 'unknown NODE; expected one of:
    schlafzimmer, wohnzimmer, kueche, bad, terrasse'
```

## 3. Compile

```bash
# Just build the ELF (defaults to NODE=terrasse)
cargo build --release
# -> target/riscv32imc-unknown-none-elf/release/rs-smarthome-nodes

# …or build for another node
NODE=kueche cargo build --release
```

> Each node is a **separate build**, so rebuild before flashing a different
> board — the ELF path is the same for all of them. Or flash the same image
> everywhere and tell each board what it is afterwards; see
> [§7](#7-provisioning-a-board-without-reflashing).

`espflash` reads that ELF directly; there's no separate objcopy/bin step.

---

## 4. Flash over the XIAO's native USB-C (the normal way)

**This is all you need.** The ESP32-C3 has a **built-in USB Serial/JTAG
controller**, so the XIAO's USB-C port is the programmer — plug it straight into
your computer, no probe or adapter involved.

```bash
# Build, flash, and open the serial monitor in one step
# (`cargo run` uses the `espflash flash --monitor` runner from .cargo/config.toml)
SSID="MyNetwork" PASSWORD="s3cret" cargo run --release

# …for one of the other nodes
NODE=kueche SSID="MyNetwork" PASSWORD="s3cret" cargo run --release

# …or flash an already-built ELF explicitly:
espflash flash --monitor \
  target/riscv32imc-unknown-none-elf/release/rs-smarthome-nodes
```

Useful checks:

```bash
espflash board-info          # confirm the chip is detected
```

> **Getting into download mode:** a battery node (`NODE=terrasse`) enters deep
> sleep a couple of seconds after boot, which can interrupt a flash — mains
> nodes stay awake. If `espflash` can't sync, force the
> ROM bootloader: **hold the `B` (BOOT / GPIO9) button, tap `R` (RESET), release
> `B`.** Then re-run the flash command.

### Flashing a battery node without reaching its buttons

The buttons are not always reachable — a node in its enclosure, on a mast, or
wired into a scale. There is no need for them.

The reason a single `espflash flash` fails is not that the node is unreachable;
it is that it is only reachable *briefly*. It deep-sleeps about two seconds
after boot and its USB port goes with it, so one invocation started at the
wrong moment finds nothing.

**Waking up is not enough, and this is the part that wasted half an hour on
2026-09-12.** The USB controller does come back on every wake and does start to
enumerate — but an idle round is awake for milliseconds, far less than a host
needs to read a device descriptor. What that looks like from the host is a
device that appears and fails, about every two seconds, forever:

```
usb 6-1: new full-speed USB device number 18 using xhci_hcd
usb 6-1: device descriptor read/all, error -71
usb 6-1: new full-speed USB device number 20 using xhci_hcd
usb 6-1: device descriptor read/all, error -71
```

Seventy-six such attempts in three minutes, and **no `/dev/ttyACM*` is ever
created**, so a poll loop has nothing to fire at. Check `journalctl -k` before
concluding the node is dead: the `-71` storm means it is alive and sleeping.

So the node has to be made to stay awake first, and it has a switch for exactly
that. Publish it retained, because the node is asleep when you send it:

```bash
mosquitto_pub -h "$BROKER" -u "$MQTT_USER" -P "$MQTT_PASSWORD" \
  -t smarthome/terrasse/config/deep_sleep -m 0 -r -q 1
```

It is picked up on the node's next publish round — up to `heartbeat_interval`
away, ten minutes by default — and from then on the port enumerates properly
and stays. Then flash normally, and **put it back afterwards**:

```bash
espflash flash --port /dev/ttyACM0 "$ELF"
mosquitto_pub ... -t smarthome/terrasse/config/deep_sleep -m 1 -r -q 1
```

Watch for `config: deep_sleep = 1` / `deep sleep re-enabled — sleeping` on the
monitor to confirm it took. A battery node left awake is not a small mistake:
it draws about 28 mAh an hour against the ~3.3 mA that makes the cell last
weeks.

The poll loop below is still worth having, but for a narrower case: the node is
awake for several seconds during a publish round, and that window *is* long
enough to enumerate. It is the tool for catching a node that publishes often,
or for firing the instant someone holds `B` (BOOT) while plugging the cable in.

```bash
ELF=target/riscv32imc-unknown-none-elf/release/rs-smarthome-nodes
while :; do
  p=$(ls /dev/ttyACM* 2>/dev/null | head -1)
  [ -n "$p" ] && espflash flash --port "$p" "$ELF" && break
  sleep 0.02
done
```

Start it *before* plugging the node in. The 20 ms poll matters: at 200 ms most
of the window is gone before the first attempt.

`--port` is required, not optional: without it `espflash` asks which port to
use, and a non-interactive shell gets `IO error: not a terminal` rather than a
prompt.

Whichever route you take: **a reflash does not clear RTC RAM.** The tare
baseline, the presence flag and the discovery digest all survive it (see
[`src/state.rs`](src/state.rs)). If the point of the reflash was to clear a bad
baseline, pull the power afterwards and leave the beam alone for that boot.

The same fact has a sharper edge for *new* firmware. A
`#[ram(rtc_fast, persistent)]` word is never zeroed by the startup code, so one
that has just been added comes up holding whatever was in that slot — and
because the reflash preserved RTC RAM, the first boot on the new firmware is
**not** a cold boot, so a cold-boot check does not save you. The visit counter
came up at 2,345,324,652 that way on 2026-09-12. Guard such a word with a
checked pair rather than with a boot-time branch; `scale::VISITS_MAGIC` is the
worked example.

### Do not use `espflash monitor` to check *whether* an app is running

It resets the chip in order to attach — `--before default-reset` is the
default — so on this chip it destroys the thing you are trying to observe:

1. the pre-connect reset drops the chip into the ROM bootloader, which prints
   `boot:0x0 (USB_BOOT)` and `wait usb download`;
2. `--after hard-reset` then resets again so the app runs;
3. that second reset makes the USB serial/JTAG **re-enumerate**, which
   invalidates the monitor's open handle — it dies with `Broken pipe`, usually
   before the app has logged anything.

The result reads exactly like a board stuck in download mode, and it is not.
Both lines come from `espflash` on the way in, not from the board's final
state. Cost of learning this the hard way: a board declared dead, a BOOT/RESET
dance, and a power cycle, all for a node that had been booting correctly the
whole time.

To watch a battery node, read the port **passively** instead — no `espflash`,
no reset:

```bash
# wait for the port to appear, then just read it
while [ ! -e /dev/ttyACM0 ]; do sleep 0.2; done; cat /dev/ttyACM0
```

Two independent signals are worth more than the monitor here:

- **Port presence.** A board in download mode holds USB open continuously. One
  whose `/dev/ttyACM*` *disappears* is in deep sleep, and only the app sleeps.
  Absence of the port is evidence the app is running.
- **`Saved PC:` in the boot banner.** It is only printed when the chip came out
  of deep sleep, so it says the app ran on the previous cycle.

`espflash flash` is unaffected — it reports `Flashing has completed!` on its
own, and that line is trustworthy. It is only *observation after the fact* that
needs the passive read.

---

## 5. (Optional) Flash with a Raspberry Pi Pico ("picoprobe")

> **You almost certainly don't need this.** Use [§4](#4-flash-over-the-xiaos-native-usb-c-the-normal-way)
> unless the XIAO's own USB-C is unavailable — e.g. the board is potted in the
> feeder enclosure, or you want galvanic separation from your PC.

### 5a. Turn the Pico into a probe

Flash the Pico with the official **debugprobe** firmware (hold BOOTSEL, drag the
`debugprobe_on_pico.uf2` from
<https://github.com/raspberrypi/debugprobe/releases> onto the `RPI-RP2` drive).
`debugprobe` exposes two USB interfaces: a CMSIS-DAP debug port **and a
USB-to-UART bridge**.

### 5b. Which method — UART, not JTAG

The ESP32-C3 is a **RISC-V JTAG** target, but the debugprobe's CMSIS-DAP port is
SWD-oriented, and routing the C3's JTAG to external pins (GPIO4-7) requires
**irreversibly burning the `DIS_USB_JTAG` eFuse**. So the practical picoprobe
path is the **UART bridge** driving the ESP32-C3 ROM serial bootloader — no
eFuse burning, fully reversible.

> For interactive *debugging* (breakpoints via `probe-rs`), skip the Pico and
> use the XIAO's own built-in USB-JTAG over its USB-C port:
> `probe-rs run --chip esp32c3 <elf>`.

### 5c. Wiring (Pico debugprobe UART → XIAO ESP32-C3)

| Pico (debugprobe) | XIAO ESP32-C3 | Direction |
| --- | --- | --- |
| `GP4` (UART TX) | `D7` / GPIO20 (U0RXD)| probe → target |
| `GP5` (UART RX) | `D6` / GPIO21 (U0TXD)| target → probe |
| `GND` | `GND` | common ground |

Power the XIAO from its own USB-C or the LiPo — **do not** back-feed 3V3 from the
Pico. Keep grounds common.

Because the debugprobe UART does not drive the C3's `EN`/`BOOT` lines, download
mode must be entered **manually** (hold `B`/BOOT, tap `R`/RESET, release `B`).

### 5d. Flash over the probe's serial port

The debugprobe UART shows up as a serial device (Linux: `/dev/ttyACM1`, the
second CDC interface; macOS: `/dev/cu.usbmodemXXXX`).

```bash
# 1. Put the C3 in download mode (hold B, tap R, release B).
# 2. Flash over the Pico's UART bridge:
SSID="MyNetwork" PASSWORD="s3cret" \
espflash flash --monitor \
  --port /dev/ttyACM1 \
  --baud 460800 \
  target/riscv32imc-unknown-none-elf/release/rs-smarthome-nodes
```

If sync fails, drop the baud to `115200` (long/loose jumper wires limit rate)
and confirm TX/RX aren't swapped.

---

## 6. Verifying it works

The first line names the node the image was built for — check it before anything
else, it is the one mistake that produces a board that looks perfectly healthy
while publishing to the wrong room.

**Outdoor scale (`NODE=terrasse`, battery)** — a publish cycle:

```
node 'terrasse' (Terrasse) booted, battery profile
config: offset=8388608 scale=420 threshold=10g idle=2s active=10s
HX711 raw reading: 8402193
presence: raw=8402193 baseline=8388608 delta=13585
weight = 32.3 g
DS18B20 = 25.1 °C
SHT31-D found at 0x44
SHT31-D: air_temperature = 21.4
SHT31-D: air_humidity = 47.2
Wi-Fi link up, waiting for DHCP...
Got IP: 192.168.1.42/24
published Home Assistant discovery for node 'scale'
Published 32.3 to smarthome/terrasse/weight
Published 25.1 to smarthome/terrasse/temperature
Entering deep sleep for 10s
```

Idle cycles are much quieter — an empty feeder skips the radio, the DS18B20 and
the I²C sensors entirely, which is the whole point of the battery profile:

```
node 'terrasse' (Terrasse) booted, battery profile
HX711 raw reading: 8388601
Entering deep sleep for 2s
```

**An air-quality node (`NODE=wohnzimmer`, mains)** stays associated and loops.
Most rounds are the 60 s ones; the SDS011 joins one round in fifteen, which is
the only time the fan is heard:

```
node 'wohnzimmer' (Wohnzimmer) booted, mains profile
Wi-Fi link up, waiting for DHCP...
Got IP: 192.168.1.51/24
SHT31-D: temperature = 21.8
SHT31-D: humidity = 61.4
SCD41: co2 = 734
SDS011: pm25_raw = 8.3
SDS011: pm10_raw = 12.1
SDS011: pm25 = 6.1
SDS011: pm10 = 8.9
published Home Assistant discovery for node 'wohnzimmer'
Published 6.1 to smarthome/wohnzimmer/pm25
```

Weight is published in **grams** (converted on-device from the flash-stored
calibration); the `config:` line shows the values loaded from flash (or
built-in defaults on a blank device). Calibration and tuning are changed from
Home Assistant — see the [README](README.md#configure--calibrate-from-home-assistant).

### If a sensor is quiet

Every sensor is optional at runtime: one that does not answer is logged and
omitted, never fatal. What the log says, and what it usually means:

| Log line | Check |
| --- | --- |
| `HX711 not responding` | DT/SCK on D1/D0, and that the amp has power |
| `DS18B20 not responding; skipping temperature` | DATA on D2 **and the 4.7 kΩ pull-up to 3V3** |
| `no SHT31-D at 0x44 or 0x45 — check SDA/SCL and the pull-ups` | nothing ACKed on the bus: SDA=D4, SCL=D5, pull-ups present, sensor powered |
| `SHT31-D found at 0x45 (ADDR strapped high); using it` | nothing — the breakout straps ADDR high and the firmware adopted it |
| `no SCD41 at 0x62 …` | same bus checks; the SCD41 also needs a solid 3V3 supply, it draws ~200 mA in bursts |
| `SCD41 found …` but no readings on the first round | expected: the first measurement on the low-power periodic cadence needs ~30 s, it arrives next round |
| `SDS011 not responding; skipping its readings` | UART RX on D3 ← sensor TX, TX on D10 → sensor RX (not swapped), and the sensor on **5 V** |

The `found at 0x…` lines come from a one-shot I²C probe on the first measurement
of each boot, so a bus problem is visible before the first reading is even
attempted.

Subscribe on the broker side to confirm the payload:

```bash
# One node
mosquitto_sub -h <broker-ip> -t 'smarthome/terrasse/#' -v

# Everything the fleet publishes, including the discovery configs
mosquitto_sub -h <broker-ip> -t 'smarthome/#' -t 'birds/#' -t 'homeassistant/#' -v
```

The entities appear in Home Assistant by themselves — each node publishes
retained discovery configs on its first connect after a power-up, for its
readings *and* for its calibration/tuning controls. Nothing is declared by hand;
see [`home-assistant/README.md`](home-assistant/README.md) for the entity list
and for calibrating the scale.

> **Re-flashing does *not* re-announce discovery.** The "already announced" flag
> lives in RTC fast RAM, which survives both the flash and the reset that
> follows it — confirmed on hardware. It survives a power cycle too, often
> enough that nothing may depend on power clearing it: the living-room node came
> back from several seconds unplugged with its flags intact.
>
> Discovery no longer cares. It is gated on a digest of every message it would
> publish, so switching a sensor on and reflashing re-announces on the next
> connect all by itself. If you want to force it anyway, clear the retained
> configs with
> `mosquitto_pub -h <broker-ip> -t 'homeassistant/sensor/<node>/<key>/config' -r -n`.

---

## 7. Provisioning a board without reflashing

`NODE=` is only the identity a board *starts* with. Any board can be told to
become another node over MQTT — useful to repurpose one, to swap in a spare, or
to flash the whole fleet with one image and sort out which is which afterwards.

Every boot prints the topic to address that board on. It is keyed by MAC,
because that is the only name a board is sure of before it knows anything else:

```
node 'terrasse' (Terrasse) booted, battery profile
provision topic: smarthome/provision/a1b2c3d4e5f6
```

```bash
# Become the kitchen node
mosquitto_pub -h <broker-ip> -r -t smarthome/provision/a1b2c3d4e5f6 -m kueche

# Go back to the identity it was flashed with
mosquitto_pub -h <broker-ip> -r -t smarthome/provision/a1b2c3d4e5f6 -m default
```

**Publish it retained** (`-r`). The node only looks while it is online for a
publish, so for a sleeping battery node the retained message is what gets the
change delivered on its next wake-up. Then:

```
provisioned as node 'kueche'; restarting
…
node 'kueche' (Küche) booted, mains profile
provisioned as node 'kueche' (from flash)
```

Notes:

- The restart is deliberate — the sensor set decides which buses are brought up,
  which happens during boot.
- A name the firmware doesn't know is logged and ignored, and the board carries
  on as it was: `provisioning asked for unknown node 'kuche'; expected one of: …`
- The retained message is re-delivered on every connect, so the firmware writes
  flash only when the value actually changes.
- The identity lives in its own flash sector, so provisioning a board never
  disturbs a scale's stored tare/calibration.
- Remember to clear the retained message (`-r -n`) if you later hand the board
  to a different room by reflashing, or it will provision itself back.

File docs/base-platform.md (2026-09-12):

# Base sensor platform — design notes

Tracking: **#11** (epic) with sub-issues #12–#17.

The firmware started as a single-purpose bird-feeder scale. It is now one
configurable base for several ESP32-C3 nodes, each carrying a different subset
of sensors, selected with `NODE=<name>` at build time.

## Fleet

| `NODE=` | Node | Sensors | Power profile |
| --- | --- | --- | --- |
| `terrasse` (default) | Terrasse | load cell (HX711) + DS18B20 + SHT31-D | battery, deep-sleep |
| `schlafzimmer` | Schlafzimmer | SCD41 + SHT31-D | mains, always-on |
| `wohnzimmer` | Wohnzimmer | SCD41 + SHT31-D + SDS011 + SGP41 | mains (fan) |
| `kueche` | Küche | SHT31-D | mains |
| `bad` | Bad | SHT31-D | mains |
| `terrasse` | Terrasse | none yet — every slot off while it is wired up | battery, deep-sleep |

A node's sensors need not share a cadence: `sample_secs` is the base round, and
a slot may ask for a slower one of its own (`Slot::every`). `wohnzimmer` is the
case that forced it — a 60 s round for the SCD41, and one round in fifteen for
the SDS011, whose fan is a ~8000 h consumable.

Per-node wiring — which sensor sits on which pad, with the pull-ups and supply
notes — is in [wiring.md](wiring.md).

## Sensor set

| Sensor | Bus | Emits | Status |
| --- | --- | --- | --- |
| HX711 load cell | bit-bang | force → grams | done (`hx711.rs`) |
| DS18B20 | 1-Wire | temperature | done (`ds18b20.rs`) |
| SHT31-D | I²C 0x44 | temperature, humidity | done (`sensors/sht31.rs`, #13) |
| SCD41 | I²C 0x62 | CO₂, temperature, humidity | done (`sensors/scd41.rs`, #14) |
| SDS011 | UART 9600 | PM2.5, PM10 | done (`sensors/sds011.rs`, #15) |

I²C addresses do not clash, so SHT31-D + SCD41 share one bus. SDS011 is the only
UART sensor, and on `wohnzimmer` it runs alongside that bus. HX711 stays a
blocking bit-bang critical section.

The SDS011's readings are corrected for humidity where a node also carries an
SHT31 (`Slot::compensated`): a nephelometer over-reads in damp air, so the
κ-Köhler growth factor is divided back out and both the corrected and the raw
values are published. κ is a Home Assistant slider, because it is a property of
the room's aerosol rather than of the sensor.

> **Bench status:** every driver is implemented and the whole fleet builds, but
> the I²C/UART drivers have not yet been run against real hardware — the bus
> timing and the SDS011 warm-up in particular want a session on the bench.

## Abstraction (#12)

`sensors::Sensor` is HAL-agnostic:

- `measure() -> Vec<Reading>` — one measurement; empty on absence (never fatal).
- `descriptors() -> &[EntityDescriptor]` — per-reading metadata for HA discovery.

`Reading` carries a `key` (topic suffix) + a pre-formatted, float-free `value`,
matching the existing on-device formatting. Shared helpers live in
`sensors/mod.rs`: `crc8_sensirion` + `crc_word` (SHT31/SCD41), `write_tenths`,
`write_int`.

The drivers are generic over the `embedded-hal-async` (I²C) and
`embedded-io-async` (UART) bus traits, so they name no esp-hal type.
`platform.rs` is the one place that does: it brings up only the buses this node
needs, wraps the single I²C peripheral in a `SharedI2c` handle (a
`NoopRawMutex` — everything is sequential on one executor) so both I²C drivers
can *own* their bus as the trait wants, and exposes one `measure_all()`.

`node.rs` holds the per-node table: identity (id/name/namespace), the sensor
slots, the power profile and the mains sampling cadence. A slot can rename its
readings (`prefix` / `label`) so two sensors emitting the same quantity don't
collide — the outdoor node's DS18B20 keeps `temperature` while its SHT31-D
publishes `air_temperature` / `air_humidity`. An unknown `NODE` value fails the
build in const-eval.

### Which node am I? (build-time default + NVS override)

The identity is resolved once at boot, before any peripheral is touched, since
the sensor set decides which buses come up at all:

1. `BUILT_AS` — the `NODE=` the image was compiled with (default `terrasse`);
2. a name stored in flash, which overrides it.

`node::active()` returns the result. It is a plain `Copy` struct read from a
`static`, written once by `node::init()` — the same single-context discipline
`state.rs` uses for its RTC-RAM cells, which is sound here because nothing runs
before `init()` and nothing writes after it.

The override is set over MQTT on `smarthome/provision/<mac>` (retained), keyed
by MAC because that is the only name an unprovisioned board is sure of. A valid,
*different* name is written to flash and the board restarts into it; anything
else — an unknown name, or the name it already answers to — is ignored without
touching flash, which matters because a retained message is re-delivered on
every single connect.

The identity blob lives in the **second** NVS sector (`0xA000`), separate from
the calibration blob at `0x9000`: provisioning must never be able to disturb a
scale's tare, and the two have completely different write frequencies. Same
discipline as the config blob — magic, version, length, CRC-32 — so a blank,
erased, corrupt or half-written sector reads back as "no override" and the board
falls back to what it was built as.

The publish path iterates whatever the node produced (`Samples`) instead of
hard-coded HX711/DS18B20 calls. The HX711 and DS18B20 keep their own read paths
— the first because its reading drives the tare baseline and presence edge, the
second because its 750 ms conversion is only worth spending on publish cycles —
and contribute their readings and discovery descriptors to the same pipeline.

### Three ways a visit used to go missing

The presence decision moved out of `main` into
[`presence`](../src/presence.rs) once it became clear that the one piece of
arithmetic deciding whether a visit is recorded *at all* was also the only part
of the firmware no host test could reach. Two of the three holes it had are now
closed; the third is a physical trade-off and stays open.

**Absorbed by the drift tracker.** The baseline nudged itself by `delta/16` on
*any* sub-threshold reading, which is right for slow thermal and mechanical
creep and wrong for a bird. A visitor whose load sat below `threshold` — a small
species, or one perched half on the rim — was pulled into the baseline within
roughly 16 cycles, so the scale read "empty" again while it was still standing
there. On departure the delta went *negative*, also sub-threshold, so no falling
edge fired either and the baseline crept back. The visit left no trace in the
logs or on the broker, and the failure was systematic rather than random: it
discriminated against light birds specifically. Drift is now confined to a band
of `threshold/4`; anything between that band and the threshold is
`Decision::Unexplained`, which leaves the baseline alone and says so in the log.

**Detected, then badly weighed.** On a rising edge the firmware used to publish
one arbitrary conversion and deep-sleep for `active_interval` (default 10 s) —
*slower* than the 2 s idle poll, so the cadence dropped exactly when dense data
was wanted. One unaveraged sample could land while the bird was still settling,
the departure was quantised to the same 10 s grid, and every one of those cycles
paid its own Wi-Fi connect: a two-minute visit cost about twelve of them. A
visit is now watched through awake with the radio off — cheap, since visits are
short — sampling the cell continuously into a 32-deep ring. The published weight
is the median of that ring, which is deliberately the *most recent* samples: a
bird that has just landed is still moving, so the tail of a visit describes it
better than the head. `VISIT_MAX` caps one awake window at 60 s so a load that
is not a bird (snow, a twig) cannot hold the CPU awake; such a load falls back
to the old `active_interval` polling, which is all that knob is still for.

**Shorter than the idle interval.** A visit that begins and ends between two
polls is invisible, and with `idle_secs: 2` plus the ~0.3 s cold boot that
window is real. This one is not a bug and is not fixed: the HX711 has no
threshold output that could wake the ESP32-C3 from deep sleep, so the only
control is the wake rate — which is itself the dominant battery cost on this
node, well ahead of the radio. Lowering `idle_interval` trades runtime for
short-visit coverage, and nothing in the firmware can make that trade for you.

The published visit duration is a **lower bound** for the same reason: the
arrival is only known to within one idle interval.

### Where the battery actually goes

The node was built around "deep sleep is free, the radio is expensive", and
that turned out to have the ranking backwards. Two things dominated instead,
and neither was the radio.

**The boot overhead.** Deep sleep sat inside the poll loop, so a 2 s idle poll
cost a full ROM boot plus app init — 269 ms measured — to clock out one 100 ms
conversion. At `idle_secs: 2` that is roughly a quarter of the node's life
spent booting, against the ~18 s an hour the radio was actually up. The polls
now run inside one boot with light sleep between them, so a cold boot happens
once per *publish*: about six an hour rather than eighteen hundred.

**The amplifier.** The HX711 and the bridge it excites draw continuously —
about 1.5 mA for the chip plus whatever the load cell's bridge takes, which for
a 1 kΩ cell at ~3.2 V excitation is another ~3 mA. `power_down()` and
`power_up()` had been written, documented and then never called, because there
was no sleep that retained the pad level: in deep sleep the pad goes
high-impedance and `PD_SCK` is left to leakage, which is also why the
amplifier's deep-sleep current was never a known quantity. The amplifier is now
powered down between polls, and the datasheet's 400 ms settling wait after
power-up is spent *in light sleep* rather than awake — the amplifier needs to be
on for it, the CPU does not, and waiting it out awake would have cost more than
the power-down saves.

The two changes compose: light sleep is what makes the power-down possible,
because it retains GPIO output levels. RTC pad hold on `SCK` (issue #5) was only
ever necessary because deep sleep was the steady state. It no longer is — deep
sleep now lasts one poll interval per publish, purely so the next cycle gets a
fresh `Radio`, since `publish` consumes it.

**These are estimates, not measurements.** The only measured figure in the
paragraphs above is the 269 ms boot time, read off a real serial log. The
current figures come from datasheets, and the two that would move the answer
most are the load cell's bridge resistance — a 350 Ω cell triples that term —
and the light-sleep current with this chip's `RtcSleepConfig` default, which
keeps the digital domain powered and so does not match the datasheet's headline
light-sleep number. A multimeter in series with the cell, once asleep and once
awake, settles both.

There is a third answer that does not touch the budget at all: stop discharging
the cell on a schedule and let a panel carry it. That is [solar.md](solar.md),
and it is the only one of the three that also stops the box being opened.

### Measuring it with what you have

The measurement above does not need a lab supply or a current probe, which is
the usual reason it does not get done.

**What a cheap multimeter cannot do is average.** The node alternates between
light-sleep polls, brief awake conversions and ~110 mA radio bursts of a few
seconds, six times an hour. A DMM updates two or three times a second and shows
something instantaneous; the figure wanted here is an integral, and it will
never appear on that display. Resolution is not the problem — a 200 mV
full-scale meter on its 200 mA range has a 1 Ω shunt, so 3.3 mA reads as 3.3 mA
with 3.3 mV of burden voltage, which is plenty to tell 1.5 mA from 3.3 from 8.

Two ways round it, in order of preference:

**1. Let the node measure itself.** It already publishes `battery_voltage` every
heartbeat. Charge the cell, run it flat, and read the answer off the broker:

```
I_avg [mA] = 2000 mAh / (24 h × days)
```

25 days is 3.3 mA; 12 days is 6.9 mA. This is not a worse substitute for the
bench measurement, it is a better one — it integrates every burst, every slow
Wi-Fi join and every visit, at outdoor temperature and the real duty cycle,
which is exactly the quantity the estimates above are guessing at. It costs
nothing but time, and it needs `src/battery.rs` on the hardware, which is
outstanding anyway.

**2. A 1 Ω shunt in the battery lead, read as millivolts.** For the breakdown —
how much is the amplifier, how much the light-sleep floor — the standing states
are steady and a meter reads them fine. Use voltage mode across a fixed shunt
rather than the meter's own current range: no fuse, no range switching, and no
brownout when the radio comes up. **On the 20 mA range a 110 mA burst puts
1.1 V across the meter's 10 Ω shunt**, which drops the board to ~2.6 V and
resets it mid-measurement. Short the leads first and note the offset; these
meters have one.

The second question — how long a real connect takes — comes off the serial log's
timestamps and needs no instrument at all.

### Radio options, parked behind a measurement

Two further battery ideas are on the table. **Neither should be started before
the measurement above exists**, and that is the whole reason they are written
down here rather than built: both of them optimise the radio, and on this node
the radio is the term everybody suspects first and the smallest one that
matters.

Against the estimated budget the radio is roughly **17 %** — about 0.55 mA of
~3.3 mA, from six connects an hour at ~3 s and ~110 mA. Driving it to *zero*
therefore caps out near **1.2×** runtime. Any proposal promising more than that
is either counting a different budget or assuming a different failure rate.

Which is the one case that changes the ranking: `WIFI_BUDGET` is **20 s**, the
bound on a join that never completes. If joins here are routinely slow or
failing, six of those an hour is ~3.7 mA and the radio genuinely does dominate.
So the measurement has to answer two questions, not one:

1. **What is the standing current**, asleep and awake — which settles whether
   the amplifier and the light-sleep floor are where the estimate puts them.
2. **How long does a real connect take**, from wake to `Entering deep sleep`.
   The serial log timestamps this for free. If it is seconds, the table above
   holds and neither option below is worth much. If it regularly approaches
   `WIFI_BUDGET`, go straight to option A.

#### Option A — static address plus a cached BSSID and channel

`ClientConfiguration` is built with `..Default::default()`, so `bssid` and
`channel` are both `None` and every join pays a full scan across all channels;
the stack then pays DHCP on top (`NetConfig::dhcpv4`). Caching the AP's BSSID
and channel in RTC RAM next to the tare baseline, and configuring a static
address, removes both. Estimated to recover a good half of what the radio costs,
for two more `#[ram(rtc_fast, persistent)]` words and a fallback path.

It needs no gateway, no second protocol and no change to the data model, and
its failure mode is benign: a stale cached channel falls back to the full scan
and the node connects anyway.

#### Option B — ESP-NOW to a mains-powered gateway

Connectionless frames on the Wi-Fi PHY: no association, no handshake, no IP,
250 bytes per packet. `esp-wifi` 0.11 gates it behind `esp-now = ["wifi"]` and
we already enable `wifi`, so it is a feature flag on a crate already in the
tree — no new dependency. A mains node would receive and republish to MQTT.

It would shorten the expensive window from seconds to milliseconds, and it
removes the 20 s worst case entirely. The costs are architectural rather than
incidental, and three of them are specific to this fleet:

- **The gateway conflicts with the self-heating fix.** A gateway has to listen
  continuously on-channel, so it cannot run modem sleep — and the obvious
  candidates, `kueche` and `bad`, both carry an SHT31. Keeping the radio awake
  on a mains node costs about 1 °C at the board, measured. The comment
  justifying `PowerSaveMode::Maximum` says the trade works because everything
  inbound is a Home Assistant knob nobody times; inbound sensor frames from a
  sleeping node are neither untimed nor buffered by an AP, so that reasoning
  does not survive the change.
- **Discovery would have to be published by proxy.** Nodes announce their own
  entities from `discovery::entities`. A gateway doing it for them means the
  fleet table moves there or goes over the air.
- **The config path is bidirectional.** A node subscribes to
  `node.config_wildcard()` and drains retained values into `Config::apply`,
  which is the broker's retention doing real work. A sleeping node cannot be
  pushed to, so it would have to *request* its config inside its awake window
  and the gateway would have to answer inside it.

Its failure mode is also worse than option A's rather than equivalent. Both
depend on a cached channel, but a Wi-Fi node with a stale one scans and
connects; an ESP-NOW node with a stale one is mute, and the gateway cannot tell
it, because it cannot reach it. Announcing the channel retained over MQTT only
helps nodes that already got through — precisely not the ones with the problem.
The remaining fix is pinning the AP's channel, which makes the sensor network
depend on a router setting that any firmware update can undo.

#### If they are looked at again

Take option A first regardless: it is strictly smaller, it shortens the same
window option B would delete, and the two are not exclusive. Option B earns its
keep only if the AP turns out to be unreliable, if the fleet grows several more
battery nodes (today there is exactly one, `terrasse`), or if
something needs sub-second latency — a button or a PIR rather than a scale that
reports every ten minutes.

## MQTT auto-discovery (#16)

On the first connect after a power-up, each node publishes one retained
`homeassistant/sensor/<node>/<key>/config` per reading, so Home Assistant creates
the device (identifiers = node id) and all its entities. State topics are
`<namespace>/<node>/<prefix><key>`; the config/command topics stay
`<namespace>/<node>/config/<key>`.

"Once per power cycle" is a flag in RTC RAM: the messages are retained, so
re-sending them on every deep-sleep wake would only cost battery, while a cold
power-on re-announces exactly when the broker may have lost them.

Power cycle means power cycle. RTC fast RAM survives a reflash and the reset
that follows it, so flashing a board does not re-announce its entities — pull
the power for that.

Every node now publishes under the fleet's own `smarthome/<node>/…` namespace.
The outdoor node used to be the exception — it kept a historical `birds/scale/…`
namespace and mirrored its weight to a pre-discovery `birds/scale/state` topic,
both carried purely so hand-declared Home Assistant entities would keep working.
That history was deliberately let go when the node was renamed to `terrasse`,
and `legacy_weight_topic` is unused across the fleet as a result.

### Command entities

The knobs that flow the other way — the ones Home Assistant publishes to
`<namespace>/<node>/config/<key>` — are discovered as well, as `number`,
`switch` and `button` entities under the device's *Configuration* category. They
used to be the one thing still hand-declared in YAML, which meant each node in
the fleet needed its own copy-pasted block.

Which knobs a node gets follows from what it *is*: the calibration ones only on
a node with a load cell, the sleep/interval ones only on a battery node, since a
mains node samples on its build-time cadence and never sleeps. A dead control on
a device card is worse than a missing one.

Two details that are not obvious:

- **The button consumes its own message.** A button's payload is a constant, so
  the firmware cannot tell one press from the next; and the message must be
  retained, because a battery node is asleep when the button is pressed. So the
  node deletes the retained message (empty retained payload) once it has
  re-zeroed. The older timestamp-token scheme still works and is still
  remembered, which doubles as a backstop if a delete is ever lost.
- **`stat_t` points back at the command topic.** The node never echoes its
  stored config, so the sliders would otherwise sit at "unknown" until moved.
  Since commands are retained, the command topic already holds the last value
  set — which is exactly the state an optimistic control would show, except this
  one survives a Home Assistant restart.

### Availability

Two mechanisms, because neither alone covers a fleet that is half asleep:

| | Mains node | Battery node |
| --- | --- | --- |
| Last will (`avty_t` → `<ns>/<node>/status`) | yes | **no** |
| `expire_after` | 3 × `sample_secs` | 3 × `heartbeat_secs` |

A last will catches the node that dies *while connected*: the broker publishes
retained `offline` and Home Assistant greys the entities out at once. The node
publishes retained `online` right after each connect, and — importantly — sends
a proper MQTT `DISCONNECT` when a round is done, which tells the broker to
discard the will. Without that, a mains node that reconnects per round would be
declared dead after every single publish.

Battery nodes get **no** will at all: they are legitimately disconnected almost
all the time, so a will would mark them offline seconds after every reading.
They rely on `expire_after` instead, which is also what catches a mains node
that dies *between* rounds (a clean disconnect discards the will, so nothing
else would notice). Three missed rounds is the threshold — one miss is a lost
packet or a failed join, three is a node that stopped — with a 120 s floor.

`expire_after` is derived from the live config, so changing the heartbeat
interval clears the "discovery published" flag and re-announces the entities
with the new expiry.

## Power profiles (#17)

- **battery**: deep-sleep between samples (the bird-scale behaviour).
- **mains**: stay awake with Wi-Fi up, sample + publish every
  `NodeConfig::sample_secs` (60 s indoors, 900 s in the kitchen so the SDS011
  fan is only spun 4×/h). Continuous operation is required for CO₂ value and for
  the fan.

The profile is a per-node build-time choice. The live `config/deep_sleep` switch
still works, but only on a battery node — a mains node has nothing to gain from
sleeping and CO₂/PM continuity to lose, so it ignores it. The SCD41 follows the
profile too: periodic measurement on mains (what its self-calibration expects),
single-shot on battery.

### Staying awake is a thermal problem

A mains node never sleeps, so everything it burns turns into heat inside the
enclosure — and the sensors then measure their own board instead of the room.
Measured on `schlafzimmer` against a reference thermometer, 2026-09-03: the air
at the electronics sat ~1.5 °C above the room, and both the SHT31-D and the
SCD41 reported it faithfully. Worse, the SCD41's temperature offset had been
calibrated against that same warm SHT31-D, so the error had been copied into it
and the two agreeing with each other proved nothing.

Three things came out of that, in order of how much they were worth:

1. **Mount the sensors away from the board.** No firmware can undo a sensor
   sitting in warm air. This is the fix; the rest are refinements.
2. **80 MHz instead of 160.** The minimum esp-wifi will run the radio at
   (`MIN_CLOCK` in its `init`), and dynamic power scales with the clock. A round
   is a few I²C transactions and one publish, and I²C/UART timing comes off APB
   rather than the CPU clock, so nothing here notices the difference.
3. **Modem sleep, `PowerSaveMode::Maximum`.** esp-wifi never calls
   `esp_wifi_set_ps` by itself and the stack below comes up in MIN_MODEM, so
   `Minimum` would have been a no-op — `Maximum` is the setting that actually
   changes something. It costs up to ~300 ms before an inbound packet is
   collected; everything inbound here is a Home Assistant knob, and outbound
   traffic never waits on the sleep schedule.

Deliberately *not* done: a software temperature offset for the SHT31-D. The
overtemperature is roughly constant (P·R_th), so an offset is defensible in
principle, but it hides the problem rather than fixing it, depends on airflow,
and would have to correct the humidity alongside the temperature.

## Testing

`cargo test` cannot link for `riscv32imc`, and the crate used to be a single
binary that pulled in esp-hal, so it could not be built for the host either.
That left compile-time `const` assertions as the only harness, and the awkward
habit of validating things like the discovery JSON with throwaway host replicas
of the real code — copy-paste that proves nothing once it drifts.

So the crate is now a library plus a thin binary, and everything that touches a
bus, RTC RAM, flash or the radio sits behind the `hal` feature. With it off, the
remainder builds for the host: the protocol decoding, the CRCs, the flash blob
layouts, `Config::apply`, the node table and the discovery payload builders.
That is most of the logic that can be silently *wrong* rather than fail to
build.

Two changes fell out of making that possible, both of which stand on their own:

- `discovery` takes the `NodeConfig` as an argument instead of reading the
  global identity, so the payloads are a pure function of the node;
- the provisioning-payload parser moved out of `main.rs` into `node`, with the
  two facts it needs (the current identity, whether flash holds an override)
  passed in rather than read.

The tests worth having are the cross-checks, not the arithmetic: that a
discovered state topic is exactly the topic the publish path uses, that every
control key is one `Config::apply` accepts, that no two entities on a node share
a topic or a unique id, and that `KNOWN_NODES` still lists the fleet. Those are
the failures that would otherwise show up as an entity stuck at "unknown".

Compile-time assertions stay: they fail the build rather than a test run, and
they cover invariants a test cannot reach.

### Telling a dead bus from a missing sensor

A targeted probe cannot distinguish them: "no SHT31-D at 0x44" is what you get
whether the sensor is absent, at another address, or the bus is not working at
all — and those have completely different fixes. So when an expected device is
missing, and only then, the firmware sweeps `0x08`–`0x77` with zero-length
writes and reports what answered. Anything answering proves the wiring and the
pull-ups are fine; nothing answering proves they are not.

It is ~110 transactions, which is why it is a reaction to a problem rather than
part of every boot.

### Driver tests against fake buses

Making the drivers generic over `embedded-hal-async` / `embedded-io-async` was
about keeping them free of esp-hal types; the other half of that payoff is that
the **real** drivers run on the host against a scripted bus (`sensors/mock.rs`).
The `hal` feature was split for it: `drivers` brings in only the bus traits and
embassy-time, whose `std` time driver is what lets a test await a conversion.

The UART mock is the interesting one, because the SDS011 driver distinguishes
"stale frames buffered while the fan span up" from "the frame I want" purely by
draining until the line falls quiet. So the script is a list of segments with an
optional gap before each, and a run-dry mock returns `Pending` rather than
`Ok(0)` — which is what a real UART does, and what lets the driver's timeout
fire. Covered: the full duty cycle, the fan being parked on *every* exit path,
resync past noise, a rejected checksum, an absent sensor, and a stray `0xAA`
costing exactly one frame.

Writing them turned up one real hazard. `read_byte` and `drain` looped on a
read that completed with zero bytes, which never yields — so the surrounding
timeout could never fire and the driver would spin for ever. esp-hal's UART does
not do that (it waits for a byte) but the trait permits it, so both loops are
now bounded, with a `StarvedUart` test to keep them that way.

The SCD41 gets the same treatment, and there the two run modes are the point.
Periodic (mains) must send `start_low_power_periodic_measurement` exactly
**once** — a node that re-sent it every round would restart the conversion cycle
and never read anything — and must poll data-ready before reading, or it gets
the previous measurement. The low-power cadence (one sample per 30 s) rather
than the 5 s one: no mains node publishes faster than every 60 s, and the
measurements nobody collects are paid for in heat next to the SHT31-D. Single-shot (battery) does neither: it asks for one conversion,
waits it out, reads. Both must treat `0 ppm` as "no measurement yet" rather than
as air, which would otherwise draw a plausible flat line at zero. That one
single-shot test really does sit through the datasheet's ~5 s conversion; unlike
the SDS011 warm-up it is a fixed sensor timing, not a policy knob, so there is
nothing honest to shorten.

The HX711 gets the same treatment through the `embedded-hal` pin traits, and it
is the one driver that has actually been running — which is precisely why the
bit protocol is worth pinning down. The fake pins share a line, so a test can
check not only *what* was read but *when*: 24 bits most-significant-first, each
sampled while the clock is high (sampling on the low phase reads the next bit on
real hardware and produces plausible numbers rather than obvious ones), 25/26/27
total pulses depending on gain, the clock parked low afterwards so the chip is
not latched into power-down, and a disconnected amplifier timing out rather than
returning noise as a weight.

What this does *not* cover: timing, bus contention, anything electrical. A green
test says the driver handles the bytes correctly, not that the SHT31 answers
within 15 ms on the real bus.

## SDS011 warm-up

The fan cannot run continuously (~8000 h rated), so it is woken per sample — and
how long it stays awake was, until recently, a flat 20 s. That is a guess in
both directions: too long for still air, and too short for air that is actually
changing, which is exactly when the reading matters.

It now serves a **floor** and then watches. The floor (10 s) is not optional:
before the airflow establishes, the sensor repeats its last value, so frames
agree with each other perfectly and a settling check alone would stop on air
that is not moving yet. After it, the driver reads frames until three in a row
agree — within 1 µg/m³ plus 5 % of the larger, an absolute floor for clean air
where the sensor's own noise dominates and a proportional band for dirty air
where it does not — on **both** particle sizes, since PM2.5 settling while PM10
still climbs is not a settled reading.

A ceiling (30 s) stops it there and reports whatever it has: unsettled air is a
reason to publish the latest number, not to keep the fan spinning. One frame is
always read however tight the budget, because an unsettled reading beats an
empty round.

In still air this typically ends around 13 s rather than 20 — roughly 7 s of fan
life back on every sample, which on the kitchen node's four samples an hour is
the difference the duty cycle exists for.

## Wi-Fi credentials

Credentials were compile-time only, which made the one failure that matters
unrecoverable: a board that cannot join the network cannot be told anything
over the network either. MQTT provisioning — how the node identity is set — is
no help, because reaching the broker is precisely what is broken.

So the escape hatch is the **serial console**, the one channel that still works.
On a **cold boot** the board listens briefly for `ssid` / `psk` / `save`, stores
the pair in its own flash sector and restarts into it; `clear` returns it to
whatever it was flashed with. Physical access already implies the ability to
reflash, so this gives away nothing a USB cable did not.

Three decisions worth recording:

- **Cold boot only.** RTC RAM is wiped by a power-up and survives deep sleep, so
  the existing flag distinguishes "someone just plugged this in" from "this woke
  up to take a reading". A battery node pays the window once per power cycle
  rather than every two seconds.
- **The window depends on how stuck the board is.** Three seconds when it has
  usable credentials — it is only offering the chance to intervene — and two
  minutes when it does not, since a board that cannot join has nothing better to
  be doing.
- **Stored credentials are not trusted blindly.** After three consecutive
  refusals the connection task falls back to the build-time pair for the rest of
  the run. Unlike a wrong node name, a wrong passphrase cannot be corrected over
  the air, so without this a single typo would take a board off the network
  until someone walked over with a cable. The count deliberately lives in RAM,
  not RTC RAM: a power cycle should give the stored pair another try, because
  the likeliest cause of a run of failures is an access point that was down.

The passphrase is taken verbatim after the keyword, so one containing spaces
survives; only the line ending and trailing whitespace are stripped. A mangled
passphrase would be indistinguishable from a wrong one, which is a bad evening.
`show` prints the SSID and the passphrase's *length*, never its content — those
lines go to a log that may be scrolling in someone else's terminal.

## Known gaps

- Console provisioning is the only way to *set* credentials; there is no way to
  rotate them across the fleet remotely. Changing the router's passphrase means
  visiting each board with a cable.
- The battery figures in *Where the battery actually goes* are estimates from
  datasheets, with one measured number in them. Until a multimeter has been in
  series with the cell, both radio options in *Radio options, parked behind a
  measurement* stay parked — including the cheap one.
- RTC pad hold on the HX711's `SCK` (issue #5) is still undone, so the
  amplifier's state during deep sleep is undefined rather than powered down.
  Deliberate: deep sleep now lasts one poll interval per publish, so it is not
  worth the register work. It would matter again if deep sleep ever became the
  steady state.

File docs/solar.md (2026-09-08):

# Solar for the terrasse node — design notes

> **Panel and charger ordered 2026-09-08; nothing is built.** This is the
> design and the parts list, not a commissioning record. Every current figure it
> rests on is an estimate; see
> [Before you build any of this](#before-you-build-any-of-this) at the bottom.
> When it *is* built, the record goes in
> [`commissioning.md`](commissioning.md), not here.

## Why bother

The node's estimated average draw is **~3.3 mA** ([base-platform.md](base-platform.md#where-the-battery-actually-goes)),
which is:

| | |
| --- | --- |
| per day | ~79 mAh ≈ **0.3 Wh** |
| on the 2000 mAh cell | **~25 days** |

Twenty-five days is not a crisis, so the case for solar is not runtime. It is
that **the box never has to be opened again**. The outdoor board has already
lost its USB port once, and every recharge is another cycle on a connector that
lives in the rain inside an enclosure whose whole shape is an argument about
keeping water out. A node that tops itself up is a node whose lid stays shut.

## The panel, and what it forces

[Waveshare 18 V / 10 W polysilicon](https://www.berrybase.de/waveshare-polysilizium-solarpanel-18v-10w-36-zellen-340x232x17-mm-20-umwandlungseffizienz-ip67),
€11.50:

| | |
| --- | --- |
| Vmp / Imp | 17.6 V / 0.57 A |
| Voc / Isc | 21.6 V / 0.61 A |
| Size, weight | 340 × 232 × 17 mm, 935 g |
| Sealing, lead | IP67, 90 cm to a 3.5 × 1.35 mm DC plug |

10 W is roughly thirty times what the node needs, and that is the point. The
sizing case for a solar node in Germany is not the annual average, it is the
worst week in December. At ~1 peak-sun-hour a day and 70 % system efficiency
this panel returns ~7 Wh/day against a 0.3 Wh/day demand — a margin of about
23×, which means the buffer never gets drawn down and the question stops being
interesting. A 2 W panel would also work, carried by the cell through the dark
weeks; this one removes the need to think about it.

Two consequences follow from picking 18 V, and both are load-bearing:

- **It rules out every linear charger**, including the XIAO's own. See below.
- **It rules out the panel touching the box.** 935 g and 0.08 m² of sail area
  cannot hang off an enclosure that is suspended on a cord and whose purpose is
  weighing birds to the gram. Wind load and cable tension both tilt the box,
  and the bending beam measures what hangs below it *through* that tilt. The
  panel gets its own mount — wall, railing, post — and the cable reaches the
  box with a slack loop and no tension.

## Charger: CN3791, and why not the obvious modules

Do **not** feed the panel into the XIAO's `5V` pad. The onboard charger is a
small linear part (ETA4054-class, ~370 mA) with no input-voltage regulation: on
a current-limited source it pulls until the panel collapses, browns out, and
retries. The 21.6 V open-circuit is far outside what that pad tolerates in any
case.

The obvious shelf answer is an integrated module — Waveshare's
[Solar Power Management Module 6–24 V](https://www.berrybase.de/en/solar-power-management-modul-fuer-6v-24v-solar-panel)
(€8.80) or [Solar Power Manager D](https://www.berrybase.de/en/waveshare-solar-power-manager-modul-d-5v-3a-usb-c-fuer-6v-24v-solarpanels-ohne-batteriehalter).
**Both are disqualified by their own datasheets: quiescent current <2 mA.**
That is 60 % of the node's entire budget — the regulator would idle away more
than the node spends measuring, and it would do it all night. They also carry a
permanent 5 V boost stage this node has no use for.

A bare **CN3791** instead — a buck-topology MPPT charger, whose relevant
numbers are:

| | |
| --- | --- |
| Input | 4.5–28 V (abs. max on `VCC` 30 V) |
| Sleep drain from the cell | **≤15 µA** (`IBAT2`), i.e. 0.5 % of budget |
| Charge current | `120 mV / RCS` |
| MPPT | external divider, pin regulated to 1.205 V |
| Output | 4.2 V ±1 % |

Specifically the **Soldered MPPT Li-Ion CN3791 charger board** (SKU 333136,
€12.95), and not one of the €5 generic modules. It costs more and it is worth
it, because the hardware is open: schematic, BOM and KiCad files are
[on GitHub](https://github.com/SolderedElectronics/MPPT-Li-Ion-CN3791-charger-board-hardware-design),
which is the only reason any of the following is knowable rather than assumed.

Its listed range is "6–18 V", which describes the **MPPT adjustment range, not
the voltage rating** — the parts are comfortable well past this panel's 21.6 V
Voc (~23.5 V on a cold clear day). Read off the V1.2.1 BOM:

| Ref | Part | Rating |
| --- | --- | --- |
| C3 | VKMD…1H221 electrolytic | 220 µF / 50 V |
| D3 | **AOD4185** P-channel MOSFET | −40 V, Vgs ±25 V |
| D4 | RBR5LAM30A Schottky | 30 V / 5 A |
| U1 | CN3791 | 28 V operating, 30 V absolute |

Nothing on the board is marginal against this panel. On a no-name module none
of that is documented, and the input capacitor is the part most likely to have
been chosen at 25 V.

### The one change that is not optional

**`R8` must be replaced with 1.2 Ω** (1 %, ≥0.25 W).

The board ships `R8 = 40 mΩ`, which by `120 mV / RCS` is a **3 A charge
current** — 1.5 C into a 2000 mAh cell, and roughly thirty times what this node
can use. At 1.2 Ω it becomes **100 mA ≈ C/20**.

That single resistor is also what answers the cold-charging problem. A LiPo must
not be charged below 0 °C — lithium plating, permanent capacity loss, and on a
German terrace that is four months of the year rather than an edge case. But
plating is strongly rate-dependent: [Battery University](https://www.batteryuniversity.com/article/bu-410-charging-at-high-and-low-temperatures/)
puts the permitted rate at −30 °C at 0.02 C, so C/20 sits in the reduced-rate
regime that temperature-aware chargers aim for, not in the fast-charge danger
zone. And 100 mA is still ample: the 79 mAh daily budget is covered in **48
minutes** of charging.

`R8` is a **1210** part — large, and reworkable with an ordinary iron.

### Two jumpers to set while it is open

**`K2` — set the MPPT point to 18 V.** `R5` = 300 k is the fixed upper leg and
the 4×2 header selects the lower one from `R3` = 30 k, `R4` = 62 k, `R6` =
130 k, `R7` = 75 k. With the pin regulated to 1.205 V, `V = 1.205 × (300k +
Rb)/Rb`:

| Bridge | Rb | Setpoint |
| --- | --- | --- |
| R7 | 75 k | 6.0 V |
| R6 ∥ R7 | 47.6 k | 8.8 V ≈ 9 V |
| R4 ∥ R7 | 33.9 k | 11.9 V ≈ 12 V |
| **R3 ∥ R7** | **21.4 k** | **18.1 V** ← this panel |

At C/20 the panel is never loaded near its maximum power point anyway, so this
is correctness rather than yield. It is still the setting to use, and it is
something the fixed-variant generic modules cannot do at all.

**`JP1` — cut the power LED.** It is a designed-in jumper for exactly that.

The status LEDs `D1`/`D2` can stay: per the schematic they hang off `VCC`, the
**panel** side, so they cost harvest in sunshine and nothing from the cell at
night. This is the one place where the usual "desolder every LED on a cheap
module" advice does not apply — but it would have, had the board pulled them
from the battery rail.

### Why there is no NTC

The CN3791 has ten pins — `VG`, `GND`, `CHRG`, `DONE`, `COM`, `MPPT`, `BAT`,
`CSP`, `VCC`, `DRV` — and **no `TEMP` pin and no `CE` pin**. Its smaller sibling
the CN3065 does have battery temperature monitoring, but tops out at 6.5 V input
and so cannot see an 18 V panel at all. Choosing this panel means the cold-charge
question is answered by the charge current (above), optionally backed by
firmware (below), and not by the charger IC.

## Does the cold actually bind?

It feels like it should. It mostly does not, for three reasons that stack.

**Charging only happens in daylight, and daylight is the warm part of the day.**
The panel makes nothing at night or at dawn, which is when it is coldest — those
hours cost nothing because they were never productive. Charging happens roughly
10:00–15:00, at the daily temperature maximum. So the case that actually blocks
a charge is an **Eistag** (Tmax < 0 °C), not a Frosttag (Tmin < 0 °C). Frost
nights are ordinary in Germany; ice days are not. Per DWD figures the count
swings hard by winter — Berlin had 4 in the mild 2006/07 and 43 in the severe
2009/10 — and is falling across the climate reference periods. Even a severe
winter leaves well over a hundred usable days in the winter half-year.

**One usable day covers about a week.** The requirement is not one charge window
per buffer length. Consumption is 79 mAh/day; one permitted day at 100 mA over
~5 usable daylight hours returns ~500 mAh, i.e. **six days of running**. So the
node needs roughly one charge day in seven, against a 25-day buffer that is
still there underneath as the second reserve.

**And at C/20 the sub-zero prohibition is not absolute anyway** — see `R8`
above. The rate is what makes cold charging dangerous, and the rate has already
been dealt with.

If a backstop is still wanted, the firmware inhibit below should trip at
**−5 °C, not 0 °C**. It then fires on a handful of days a winter instead of
every frost day, and costs essentially no harvest.

## Wiring

```
Panel (+) ─── DC coupler ─── [ CN3791 VIN+ ]            ┌── XIAO B+
Panel (−) ──────────────────[ CN3791 VIN− ]             │
                            [ CN3791 BAT+ ]───── P+ ────┤
                            [ CN3791 GND  ]───── P− ────┴── XIAO GND
                                                  │
                                          protection board ── cell (B+/B−)
```

**The charger lands on `P+`/`P−`, not on the cell's own `B+`/`B−`.** The
protection board's overcharge FET sits in the `P−` path; wiring the charger to
the cell side puts it outside that protection entirely. `P−` is the same ground
the battery divider's foot already goes to — see
[wiring.md](wiring.md#battery-sense), which explains why
that matters for the divider too.

**The charger can go at either end**, which was not true of the first draft of
this page. The argument for keeping it indoors was that the long run should
carry the high voltage at low current — but once `R8` caps charging at 100 mA
there is no high-current side to protect: 5 m of 0.5 mm² is ~0.34 Ω there and
back, i.e. **34 mV** of drop. Put it wherever it fits, which is a question the
enclosure answers below and not an electrical one.

Nothing about the cell, the protection board or the divider changes.

## Parts

| # | Part | Spec | Source | ~Price |
| --- | --- | --- | --- | --- |
| 1 | Solar panel | Waveshare 18 V / 10 W, IP67, 3.5 × 1.35 mm DC plug | BerryBase | €11.50 |
| 2 | Charger | **Soldered MPPT Li-Ion CN3791**, SKU 333136, 54 × 38 mm | BerryBase | €12.95 |
| 3 | DC coupler | 3.5 × 1.35 mm socket with flying lead, mates with #1 | — | ~€2 |
| 4 | Extension | 2-core, ~0.5 mm², UV-resistant, length to suit the mount | — | ~€5 |
| 5 | Sense resistor | **1.2 Ω, 1 %, ≥0.25 W, 1210** — replaces `R8` | — | <€1 |
| 6 | Cable gland | M8 or PG7, with seal | — | ~€2 |
| 7 | Panel mount | bracket or clamp for 60–70° tilt, facing south | — | — |

Cell, protection board and divider are already on the node. **#1 and #2 were
ordered on 2026-09-08.**

## Mechanical

**The gland goes through the floor or a low side wall — never the roof.** The
enclosure is a cup opening downward precisely so that its only joint faces the
ground; [`models.py`](../models.py) states it as a requirement ("no seam and no
penetration in the roof"). A gland in the top would give up the one property the
whole shape exists to provide. Enter low, with a drip loop below the box.

**The board does not fit in the box as it stands.** The Soldered charger is
54 × 38 mm, and the terrasse enclosure has no spare volume at all: the interior
is 80 × 70 × 55, and [`models.py`](../models.py) records that a packing search
put the smallest interior taking the existing four parts at 76 × 66 × 52. There
was never room for a fifth. Two ways out, and the cable gland means
[`models.py`](../models.py) has to be re-run either way:

1. **Reprint a taller body.** One enclosure, one weatherproofing problem. The
   `wohnzimmer` box has already been through this.
2. **Put the charger in its own pod at the panel.** Now permitted by the wiring
   note above — but it is a second enclosure that has to survive the same rain,
   and the existing one is already solved.

The first is the cheaper mistake to make.

**Mount the panel at 60–70° from horizontal, facing south.** Steeper than the
summer optimum on purpose: the design case is December, and snow and leaves slide
off a steep panel instead of sitting on it.

## Optional: a firmware charge inhibit

If C/20 is not enough reassurance, the node is well placed to do better. The
SHT31-D already reports temperature, and on `terrasse` the pads **D3, D8 and
D10** are free ([wiring.md](wiring.md#which-pads-stay-free)). A high-side
P-channel switch in the panel line does it: AO3401A or similar (−30 V, since Voc
reaches ~23.5 V cold), gate divider 100 k/22 k against source because Vgs is
limited to ±12 V, driven by a 2N7002 from the GPIO.

**Bias the pulldown so the default is charging ON and the GPIO *inhibits*, not
the other way round.** A node whose firmware has hung and which therefore cannot
charge is the more expensive failure in January than some plating.

**Trip it at −5 °C, not 0 °C** — see
[Does the cold actually bind?](#does-the-cold-actually-bind) for why 0 °C throws
away charging days it does not need to.

## Consequences for the telemetry

Once a charger is attached, **`battery_voltage` stops being a state-of-charge
reading during daylight** — it reports the charge voltage, ~4.1–4.2 V, whatever
the cell actually holds. The meaningful sample is **shortly before sunrise**.
Rising week over week means the panel is carrying the node; falling means it is
not. Any Home Assistant template that treats the daytime value as charge state
will be wrong from the day this is fitted.

## Before you build any of this

- **The 3.3 mA is an estimate, not a measurement.** The whole sizing rests on
  it, and the only measured number underneath it is a 269 ms boot time. The two
  terms that would move it most are the load cell's bridge resistance (a 350 Ω
  cell triples that term) and the light-sleep floor. It settles the panel sizing
  and the radio question at once, and it does not need a bench meter — see
  [Measuring it with what you have](base-platform.md#measuring-it-with-what-you-have).
- **The battery divider has never been flashed to hardware.** `src/battery.rs`
  is committed and untested on the board. It is also the only instrument that
  can tell you whether any of this works, so it wants to be working *first*.

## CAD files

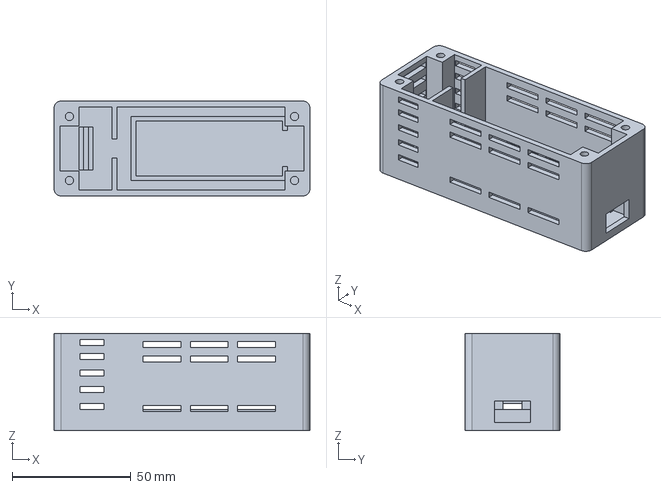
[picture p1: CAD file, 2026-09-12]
cad-models/schlafzimmer_tray.step
108.0 x 40.0 x 41.0 mm

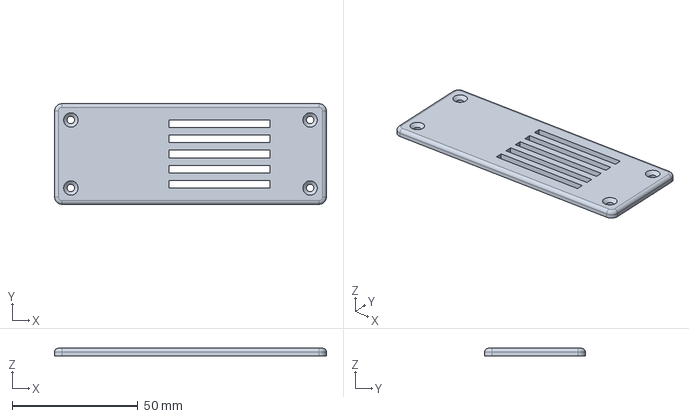
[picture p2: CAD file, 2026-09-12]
cad-models/schlafzimmer_lid.step
108.0 x 40.0 x 3.00 mm

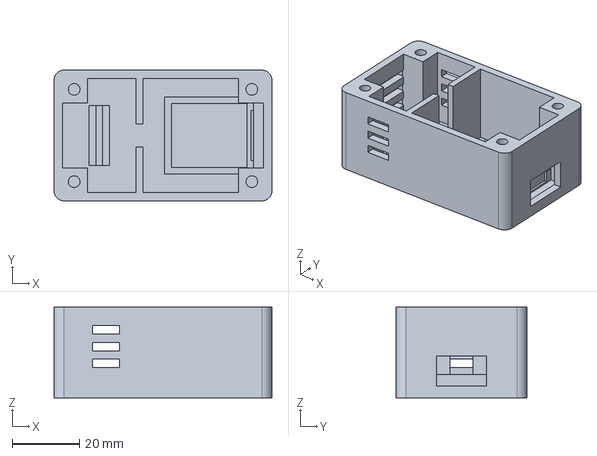
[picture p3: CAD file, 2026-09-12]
cad-models/climate_tray.step
65.0 x 39.0 x 27.0 mm

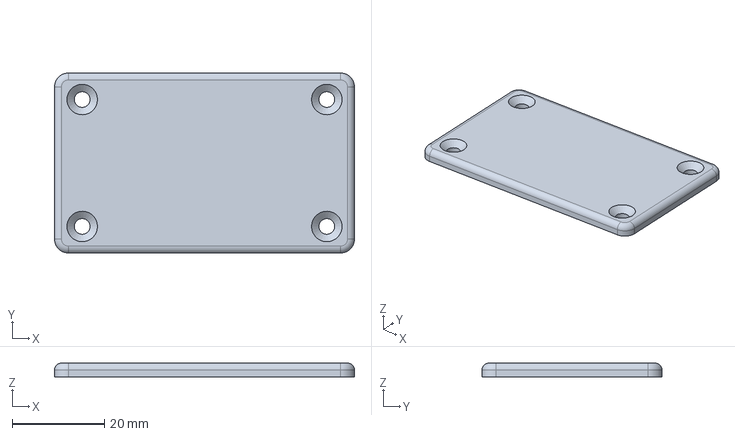
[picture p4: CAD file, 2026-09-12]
cad-models/climate_lid.step
65.0 x 39.0 x 3.00 mm

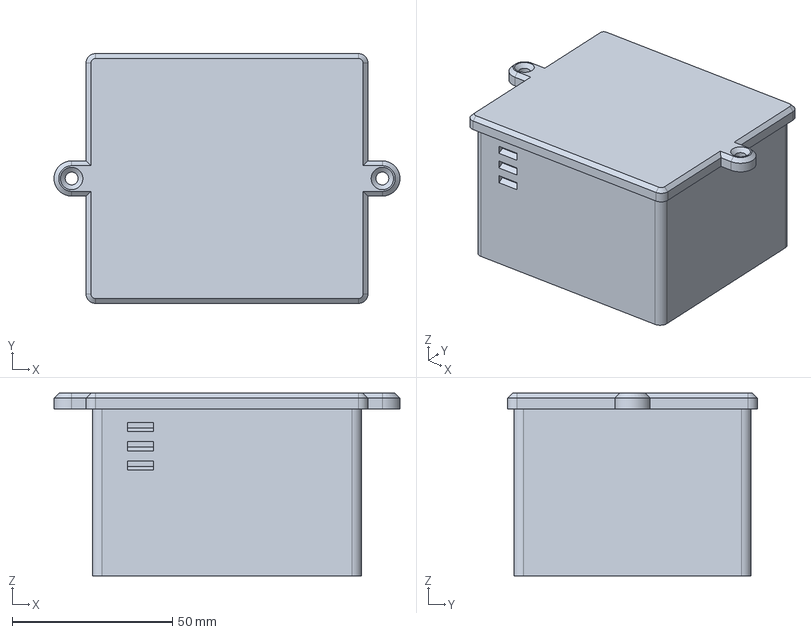
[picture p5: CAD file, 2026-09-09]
cad-models/terrasse_body.step
108.0 x 78.0 x 57.0 mm

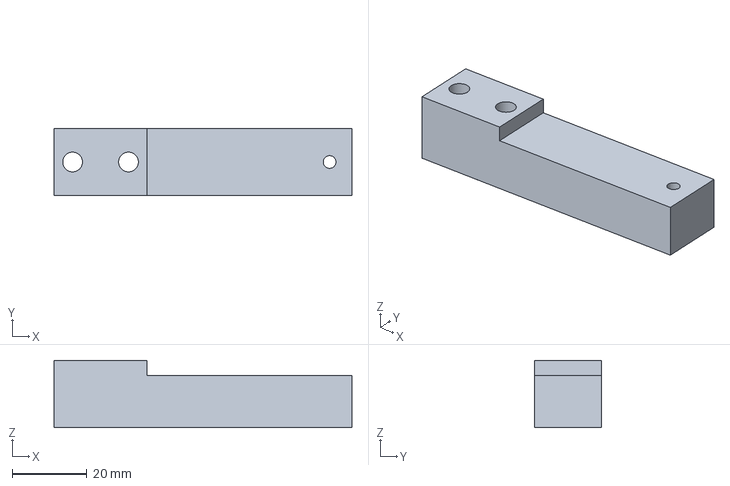
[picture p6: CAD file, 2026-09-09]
cad-models/terrasse_beam_hanger.step
80.0 x 18.0 x 18.0 mm

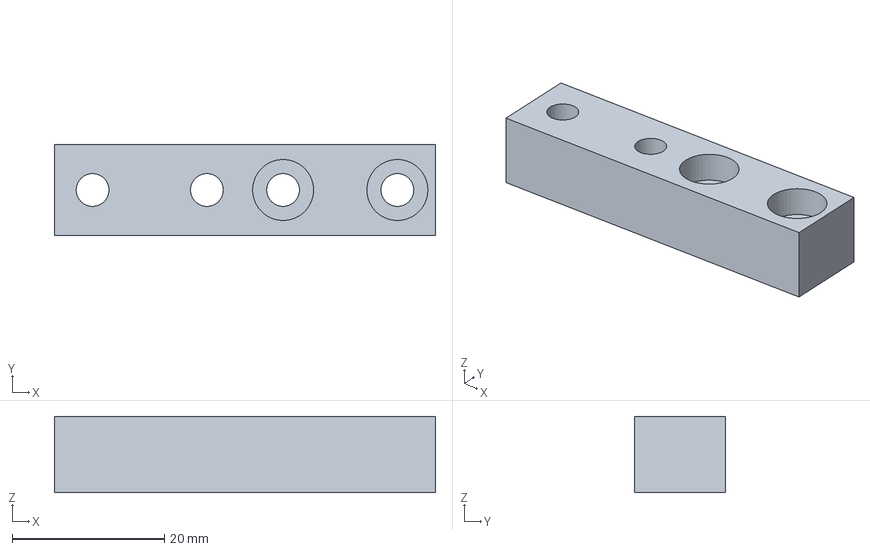
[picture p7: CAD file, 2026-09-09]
cad-models/terrasse_beam_spacer.step
50.0 x 12.0 x 10.0 mm

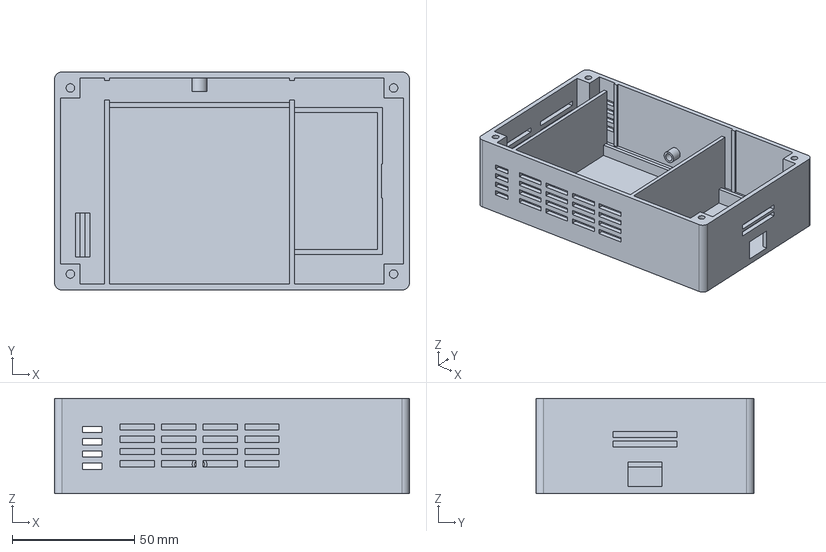
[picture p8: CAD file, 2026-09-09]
cad-models/wohnzimmer_tray.step
145.0 x 89.0 x 39.0 mm

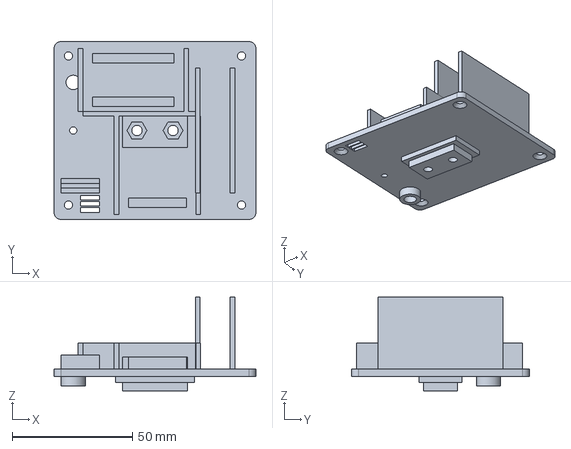
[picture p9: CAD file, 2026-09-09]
cad-models/terrasse_floor.step
84.0 x 74.0 x 39.0 mm

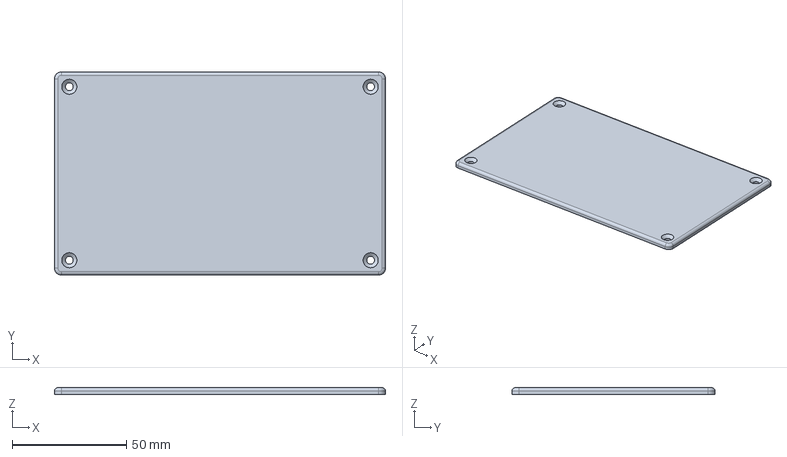
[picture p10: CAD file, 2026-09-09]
cad-models/wohnzimmer_lid.step
145.0 x 89.0 x 3.00 mm

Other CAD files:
cad-models/climate_lid.stl
cad-models/climate_tray.stl
cad-models/schlafzimmer_lid.stl
cad-models/schlafzimmer_tray.stl
cad-models/terrasse_beam_hanger.stl
cad-models/terrasse_beam_spacer.stl
cad-models/terrasse_body.stl
cad-models/terrasse_floor.stl
cad-models/wohnzimmer_lid.stl
cad-models/wohnzimmer_tray.stl

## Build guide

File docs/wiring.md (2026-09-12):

# Wiring, per node

One firmware image, five different boards. What you solder depends on which
`NODE=` the board is going to be — this page has the complete wiring for each,
so you should not have to read the source to build one.

The pin assignments here are taken from the firmware
([`src/platform.rs`](../src/platform.rs) and [`src/main.rs`](../src/main.rs)); if
the two ever disagree, the source wins and this page is the bug.

> **None of this has been built and tested yet.** The pin map, the pull-ups and
> the supply choices are what the firmware expects and what the datasheets say —
> not what a working board on a bench has confirmed. Check each connection
> against your own modules' silkscreen before powering anything up. The bird
> scale's HX711 wiring is the exception: that part has been running. Its battery
> divider and protection board are new and unbuilt, like everything else here.

## The board

Seeed Studio XIAO ESP32-C3. The silkscreen numbers the pads `D0`–`D10`, which
are *not* the GPIO numbers the datasheet and the firmware use:

| Pad | GPIO | Used for | On which node |
| --- | --- | --- | --- |
| D0  | 2  | HX711 SCK | `terrasse` |
| D1  | 3  | HX711 DT | `terrasse` |
| D2  | 4  | Battery divider tap (ADC1); a DS18B20 1-Wire line on a node that has one instead | `terrasse` |
| D3  | 5  | UART RX ← SDS011 TX | `wohnzimmer` |
| D4  | 6  | I²C SDA | every node but none exclusively — `terrasse`, `schlafzimmer`, `wohnzimmer`, `kueche`, `bad` |
| D5  | 7  | I²C SCL | as SDA |
| D6  | 21 | — **console UART TX** | keep free |
| D7  | 20 | — **console UART RX** | keep free |
| D8  | 8  | — | free |
| D9  | 9  | — **BOOT button** | keep free |
| D10 | 10 | UART TX → SDS011 RX | `wohnzimmer` |

`D6`/`D7` carry the log output. `D9` is the BOOT button, which the bootloader
samples at reset — pulling it low with your own wiring puts the board into
download mode instead of running the firmware. `GPIO0`/`GPIO1` are not broken
out on this board at all.

Power pads: `3V3` (regulated output, and also the input if you feed it from a
regulated supply), `5V` (tied to USB VBUS — an *output* when USB is plugged in),
`GND`, and `B+`/`B-` on the underside for a LiPo through the onboard charger.

## Rules that apply everywhere

- **One ground.** Every module's `GND` goes to the XIAO's `GND`. Sensors on
  their own supply still need their ground tied to the board's, or nothing
  works and the failure looks random.
- **3V3 unless stated.** Only the SDS011 wants 5 V.
- **Nothing above 3.3 V on a GPIO.** The ESP32-C3 is not 5 V tolerant.
- **Keep sensor leads short**, especially I²C. The bus runs at 100 kHz
  (`I2cConfig::default()`), which is forgiving, but 20 cm of unshielded ribbon
  next to a switching supply is not a bus.
- **Wire it with the board unpowered**, then plug USB in last.

---

## `NODE=bad` / `NODE=kueche` — SHT31-D only

The simplest build, and the right one to start with: four wires and one sensor.
If this works, the I²C half of every other node works.

Identical hardware; the two names differ only in which room they publish as.
Both are rooms that get wet on purpose, where the signal worth a long series is
the humidity and how long it takes to fall again after a shower or a pot.

> The kitchen carried the SDS011 particulate sensor until it moved to
> `wohnzimmer` — see that section for why, if you are looking at an older build
> or an older note.

**You need:** XIAO ESP32-C3, SHT31-D breakout, USB-C supply.

| SHT31-D pin | XIAO pad | GPIO | Note |
| --- | --- | --- | --- |
| VIN / VCC | 3V3 | — | |
| GND | GND | — | |
| SDA | D4 | 6 | |
| SCL | D5 | 7 | |
| ADDR | — | — | leave unconnected, see below |

**Address.** The firmware probes `0x44` (ADDR low) and `0x45` (ADDR high) and
adopts whichever answers, so you do not have to care which way your breakout
straps it — but you do have to leave the strap alone rather than floating it
against something. Most breakouts pull ADDR low on board.

**Pull-ups.** SDA and SCL need pull-ups to 3V3. Nearly every SHT31-D breakout
has them fitted (usually 10 kΩ); if yours does not, add 4.7 kΩ on each line.

**Power.** Mains — a USB-C phone charger. This node never sleeps and samples
every 120 s.

**Expected at boot** (`kueche` says `Küche` in place of `Bad`):

```
node 'bad' (Bad) booted, mains profile
SHT31-D found at 0x44
SHT31-D: temperature = 21.4
SHT31-D: humidity = 48.2
```

If instead you get `no SHT31-D at 0x44 or 0x45`, the firmware immediately
sweeps the whole bus and tells you which of two very different problems you
have:

```
I²C scan: nothing answered between 0x08 and 0x77 — the bus itself is not working
```

means SDA and SCL swapped, no pull-ups, or the breakout not actually powered.
Whereas:

```
I²C scan: 0x76 answered
I²C scan: the bus works, so the missing sensor is at none of those addresses
```

means the wiring is fine and you have a different device fitted, or one that
straps its address somewhere unexpected.

---

## `NODE=schlafzimmer` — SCD41 **and** SHT31-D

The living room is this build plus a particulate sensor; everything in this
section applies there too, so read it first and then the `wohnzimmer` section
for what it adds.

> **Do not peel the white film off the SCD41's metal cap.** It is not a
> protective sticker or a shipping label — it is the gas-permeable membrane over
> the sensor opening, and it is part of the sensor. Removing it leaves the
> optical path exposed, and the sensor then answers every command perfectly
> while reporting `0 ppm` for ever. That failure cost a module on 2026-08-26 and
> looks exactly like a wiring or supply fault from the outside, so it is worth
> being sure: the film stays on.

**You need:** XIAO ESP32-C3, SCD41 breakout, SHT31-D breakout, USB-C supply.

### Why two sensors

The SCD41 has a temperature and humidity sensor built in, and it is the weaker
one. Sensirion specifies it at **±6 %RH** (±9 outside 15–35 °C / 20–65 %RH)
against the SHT31-D's **±2 %**, because it sits on a die that heats itself for
the CO₂ measurement. So the SHT31-D measures the room, and the SCD41 measures
CO₂ — plus its own temperature and humidity, which are published separately
under `scd41_` because you need them to calibrate its offset (below).

### Wiring

Both sensors share one I²C bus. Four wires leave the XIAO; both breakouts tap
them.

| Sensor pin | XIAO pad | GPIO | Note |
| --- | --- | --- | --- |
| VIN / VDD | 3V3 | — | see *Supply* |
| GND | GND | — | |
| SDA | D4 | 6 | both sensors in parallel |
| SCL | D5 | 7 | both sensors in parallel |

**Addresses** do not collide: the SCD41 is fixed at `0x62`, the SHT31-D sits at
`0x44` or `0x45` and the firmware adopts whichever answers. Nothing to strap.

**Pull-ups.** Both breakouts usually fit their own, which puts them in parallel:
two 10 kΩ become 5 kΩ, and even 2.2 kΩ against 10 kΩ lands near 1.8 kΩ. That is
still inside the 3 mA sink current the SCD4x datasheet guarantees its low level
for, so leave both fitted and only unsolder one set if the bus actually
misbehaves.

**Supply — and this is the one place the topology matters.** The SCD41 draws
175 mA typical, 205 mA maximum while its IR source fires, against microamps
between measurements. Sensirion allows **30 mV** of ripple at the sensor, which
over a 205 mA pulse is a total resistance budget of about **146 mΩ** — for the
regulator, both leads, and every contact on the way. Four DuPont contacts alone
eat most of that, which is why this node wants soldered joints rather than
jumper headers. Ten centimetres of 26 AWG is only ~27 mΩ for the pair, so length
is cheap and distance from the board is affordable.

Run 3V3 and GND from the XIAO **directly to the SCD41** as their own pair rather
than daisy-chaining its supply through the SHT31-D breakout — that would put
extra pads and contacts in the path that carries the pulse. The SHT31-D draws
almost nothing and may branch off anywhere. SDA and SCL carry milliamps, so
those can be looped through in any order.

```
XIAO   3V3 ─────────────────► SCD41 VDD      own pair, short, soldered
       GND ─────────────────► SCD41 GND
        └┬─────────────────► SHT31 VIN       may branch off
         └─────────────────► SHT31 GND

       D4  ──┬─────────────► SCD41 SDA       bus, order irrelevant
             └─────────────► SHT31 SDA
       D5  ──┬─────────────► SCD41 SCL
             └─────────────► SHT31 SCL
```

### Placement

**Both sensors in the same air, both away from the board.** Same air, because
the offset calibration below is the difference between their two temperatures —
mount them next to each other or it measures nothing useful. Away from the
board, because Sensirion's design-in guide names the Wi-Fi module explicitly as
a heat source and asks for maximum distance from self-heating components; a
fixed offset cannot compensate a heat source that varies with radio traffic.

Otherwise as for any air sensor: not inside a sealed enclosure, not where
someone breathes directly on it. The SCD41's automatic self-calibration assumes
the room reaches roughly outdoor CO₂ at some point in a week — a room that is
never aired will drift.

**Power.** Mains, always on. The firmware runs the SCD41 in *periodic* mode on
mains, which is what its self-calibration expects, and samples every 60 s.

### Expected at boot

```
node 'schlafzimmer' (Schlafzimmer) booted, mains profile
SHT31-D found at 0x44
SCD41 found at 0x62
SCD41 serial 0x41AC3D073BD4
```

The serial number is worth a glance. It identifies the physical sensor, and it
is the cheapest counterfeit check available — the SCD4x is widely copied, and
fakes tend to answer with zeroes or with the same number on every unit, which
the firmware calls out. Two genuine modules must return different numbers.

The **first SCD41 round after a power-up reports nothing** — the first
conversion needs about five seconds and the firmware does not block the publish
path waiting for it. Readings appear on the next round:

```
SHT31-D: temperature = 26.3
SHT31-D: humidity = 52.9
SCD41: co2 = 367
SCD41: scd41_temperature = 26.6
SCD41: scd41_humidity = 55.9
```

### Calibrating the temperature offset

The SCD41 cancels its own self-heating with a temperature offset, 4 °C out of
the box — a figure chosen for continuous operation in a particular enclosure,
not for yours. It is not cosmetic: the humidity output is compensated to the
offset-corrected temperature, so an offset that does not match the real
self-heating skews **both** signals, temperature low and humidity high. The
datasheet only claims its RH/T accuracy if the offset is set correctly.

Do this once per node, after the sensors are mounted where they will live:

1. Let it run **at least 15 minutes** in place. Sensirion asks for that much for
   complete thermal equilibration, and the reading really does still drift for
   the first several minutes.
2. Read `temperature` (the SHT31-D) and `scd41_temperature` off the device card.
3. New offset = `4.00 + (scd41_temperature − temperature)`, i.e. subtract however
   much the SCD41 reads *colder* than the reference.
4. Enter it in the **Temperatur-Offset** number entity on the node's device card.

The value is written to the sensor on the next round — which costs one round,
because applying it stops and restarts the measurement. It is deliberately not
persisted to the sensor's own EEPROM (limited write cycles); the firmware keeps
it in flash and reprograms it on every boot.

Calibrate in the final position and enclosure. On a bench, dangling off a USB
cable, the self-heating is different and so is the answer.

### If something is wrong

`no SCD41 at 0x62` or `no SHT31-D at 0x44 or 0x45` — read the bus scan that
follows it, same two cases as for the SHT31-D-only node above.

If a sensor is *found* but produces no readings, the log says where it fell
over rather than just "not responding": whether it refused to start, never
reported a ready measurement, answered with a bad CRC, or returned a well-formed
measurement it considers invalid (`reported 0 ppm`). After three empty rounds
the firmware runs the SCD41's built-in self test, which settles the only
question that matters:

```
SCD41 self test reports a malfunction — the part itself is faulty
SCD41 self test passed — the sensor believes it is healthy, so look at
wiring, supply or placement rather than the part
```

---

## `NODE=wohnzimmer` — SCD41, SHT31-D, SDS011 **and** SGP41

The busiest mains node, and the only one on two buses at once. Build the
`schlafzimmer` node above first — the I²C half is identical, down to the
membrane warning and the supply budget — and then add the SDS011.

**You need:** everything the bedroom node needs, plus an SDS011 and a USB-C
supply that can spare ~100 mA more for its fan.

### Why the particulate sensor is here and not in the kitchen

The kitchen is where the particulates come from, which makes it the obvious
place and the wrong one.

The SDS011 is a nephelometer: an open optical path with a fan pulling room air
through it. Kitchen air carries fat aerosol from frying, and that films the
optics and the fan blade. The sensor does not fail when this happens — it keeps
answering, with a calibration that has quietly walked off. That is the same
shape of failure as the SCD41's membrane, and it is the expensive one, because
nothing in the log says it is happening.

The second reason is that the interesting question is answerable here and not
there. That frying makes smoke is not worth a year of data. How much of it
reaches the room people sit in, and how long it takes to clear, is — and it is
the number an automation can act on.

It also lands where an SHT31 already is, which is what makes the humidity
correction below possible at all.

### SDS011 → XIAO

| SDS011 pin | XIAO pad | GPIO | Direction |
| --- | --- | --- | --- |
| 5V | 5V | — | supply |
| GND | GND | — | |
| TXD | D3 | 5 | sensor → board |
| RXD | D10 | 10 | board → sensor |
| 1µm / 2.5µm | — | — | leave unconnected |

**Crossed, not straight.** The sensor's TX goes to the board's RX and vice
versa. Getting this backwards is silent: no error, just no frames.

**The 5V pad is USB VBUS**, so this node only works while it is plugged into
USB — which it is, being a mains node. If you power the XIAO from a regulated
3V3 supply instead, the `5V` pad gives you nothing and the SDS011 needs its own
5 V source (with the grounds tied together).

**Logic levels.** The SDS011's UART is 3.3 V logic despite the 5 V supply, so no
level shifter is needed in either direction. This is what the module's datasheet
states; if you have a meter, confirming TXD idles at ~3.3 V and not ~5 V before
connecting it to D3 costs a minute and could save the pin.

**Nothing shared with the I²C sensors** but the supply rails. Keep the SDS011's
own 5V/GND pair away from the run that feeds the SCD41, which has a 146 mΩ
budget of its own (see the bedroom section) and does not want a fan's current
steps in it.

### Fan life, and the two cadences

The fan and laser are rated around 8000 hours, so the firmware keeps them asleep
and wakes them only to measure. On this node that matters more than it used to,
because the SCD41 beside it wants a reading a minute and the SDS011 must not
have one.

So the node has a **base round of 60 s** — the SCD41's and the SHT31's cadence —
and the SDS011 sits out fourteen of every fifteen of them, giving it one round
every 15 minutes. That is `Slot::every(900)` in
[`src/node.rs`](../src/node.rs); Home Assistant is told about both cadences
separately, so the PM entities are not marked stale during the fourteen minutes
they are legitimately quiet.

Do not "helpfully" leave the fan running.

### Humidity correction

A nephelometer infers mass from scattered light. Above roughly 60 %RH
hygroscopic particles take up water and scatter like something bigger than
their dry selves, so the reported mass runs high — steeply so as the air
approaches saturation. Without a humidity figure you cannot tell a dusty room
from a damp one.

Because this node has an SHT31, the firmware corrects for it, using the
κ-Köhler growth factor:

```text
C_dry = C_wet / (1 + κ · (RH/100) / (1 − RH/100))
```

Both values are published: `pm25` / `pm10` are corrected — build automations on
those — and `pm25_raw` / `pm10_raw` are what the sensor actually said. You need
the pair to judge the correction, exactly as you need `scd41_temperature` to
judge the CO₂ sensor's offset.

**κ is a property of your air, not of the sensor.** Published values run from
about 0.25 to 0.62 for ambient aerosol; indoor aerosol sits at the low end, so
the default is **0.25** — a starting point, not a calibration. It is a slider in
Home Assistant (*Feuchte-Korrektur κ*, `smarthome/wohnzimmer/config/sds011_kappa`):
watch corrected against raw over a few humid days and move it. Setting it to `0`
turns the correction off and leaves both entities in place.

Two limits worth knowing. Above **95 %RH** the correction is capped — the growth
factor has a pole at 100 %, and air that wet is fog, where the model's premise
has stopped holding anyway. And if the SHT31 does not answer in a round, only
the raw values are published; the corrected ones expire rather than being
quietly filled with uncorrected numbers.

### Placement

The I²C pair goes as in the bedroom section. The **SDS011 belongs next to the
SHT31**, close enough that the humidity it is corrected against is the air it
actually sampled — that is what makes the correction mean anything.

Beyond that: airflow in and out unobstructed, and the sensor must stay dry.
Condensation ruins both the reading and the hardware.

### Expected at boot

```
node 'wohnzimmer' (Wohnzimmer) booted, mains profile
wifi: 'your-network' (built in)
SHT31-D found at 0x44
SCD41 found at 0x62
SCD41 serial 0x4E7003073BC3
Sgp41 found at 0x59
SGP4x serial 0x000005A5F259
```

`Sgp41` and not `Sgp40` on that line matters: the two parts share the address
and most of the command set, and only the SGP41 has a NOx channel. The driver
asks once and remembers, so a board that turns out to carry an SGP40 publishes
one index instead of two rather than inventing the second.

Nothing about the SDS011 — it is only touched on a round of its own. What you
should *not* see is:

```
SDS011 UART init failed: ...; sensor disabled
```

which means the UART could not be configured at all — a build or pin problem,
not a wiring one. A sensor that is wired wrong instead shows up, once every 15
minutes, as:

```
SDS011 not responding; skipping its readings
```

A working PM round takes 10–30 s from the fan starting, then:

```
SDS011: pm25_raw = 24.5
SDS011: pm10_raw = 100.0
SDS011: pm25 = 18.1
SDS011: pm10 = 74.1
```

The corrected values being *below* the raw ones is the expected direction: the
correction only ever removes water, never adds particles.

### SGP41 → XIAO

The gas sensor joins the I²C bus the other two are already on. Nothing is
strapped and nothing collides: the SCD41 is fixed at `0x62`, the SHT31-D sits at
`0x44`/`0x45`, the SGP4x at `0x59`.

| SGP41 pin | XIAO pad | GPIO | Note |
| --- | --- | --- | --- |
| VDD | 3V3 | — | see *Supply* below |
| GND | GND | — | |
| SDA | D4 | 6 | third device on the bus |
| SCL | D5 | 7 | |

**Supply.** The part heats a metal-oxide plate, and that is the whole current
budget: about 50 mA while the hotplate pulse runs, a few microamps between. At
one sample a second the average lands near 3 mA, so it changes nothing on a
mains node — but it is a pulsed load on the same 3V3 the SCD41 pulses on, and
the SCD41's ripple budget is tight (see the bedroom section). Give it its own
short pair back to the XIAO rather than daisy-chaining it through the SCD41's.

### Why the gas sensor is on this node

Because it is the only one that can sample it correctly. What the SGP4x returns
is a hotplate resistance, comparable only while the heater keeps running, and
Sensirion's index algorithm is specified for a 0.5–10 s interval. The firmware
ticks it **once a second** between publish rounds (`GAS_STEP_INTERVAL` in
`main.rs`). A battery node is asleep between rounds and could not do that at
all; a node sampled once a minute would publish a number that looks like a VOC
index and is not one.

The second reason is the same as the SDS011's: this is the room people sit in,
and a VOC index is a statement about the air they are in.

### What the index is, and is not

1 to 500, where **100 is the running average of roughly the last 24 hours in
this room**. It is not a concentration: there is no µg/m³ and no ppb behind it,
because a metal-oxide film responds to a mixture and the same resistance can
mean very different mixtures. What it is good for is *change* — cooking,
cleaning products, a room that has not been aired — against this room's own
recent normal.

That also means a fresh boot has nothing to say for about a minute: ten
conditioning steps, then the algorithm's 45-second blackout, and only then does
`voc_index` appear in a publish. Silence in that window is the sensor working.

**NOx will read its floor indoors, more or less for ever.** NOx comes from
combustion; a flat NOx index is the channel working, not failing.

---

## `NODE=terrasse` — the bird scale

The busiest board: two sensors, two buses, a battery and the only analogue
measurement in the fleet. This is the one that already exists; the others are
simplifications of it.

**You need:** XIAO ESP32-C3, 1 kg straight-bar load cell, HX711 breakout,
SHT31-D breakout, 1S protection board, two 100 kΩ resistors, one 100 nF
capacitor, LiPo cell.

### Load cell → HX711

The four leads go to the HX711's **input** side. Colours follow the common
straight-bar convention — check against your cell's own datasheet, they vary.

| Load-cell lead | HX711 pin | Meaning |
| --- | --- | --- |
| Red | E+ | excitation + |
| Black | E− | excitation − |
| Green | A+ | signal + |
| White | A− | signal − |

If loading the pan makes the reading go *down*, swap A+ and A−.

### HX711 → XIAO

| HX711 pin | XIAO pad | GPIO | Direction |
| --- | --- | --- | --- |
| VCC | 3V3 | — | |
| GND | GND | — | |
| SCK | D0 | 2 | board → amp |
| DT | D1 | 3 | amp → board |

`DT` is configured with the internal pull-up on, so a *disconnected* amplifier
reads as permanently "not ready" and times out cleanly instead of feeding you
floating garbage. That is deliberate: a scale reading nonsense is worse than one
reading nothing.

### SHT31-D → XIAO

Exactly as for `NODE=bad`: 3V3, GND, SDA→D4, SCL→D5.

On this node the SHT31-D's readings are published under `air_temperature` and
`air_humidity`. That prefix is older than the current build — it was there to
leave the plain `temperature` key to a DS18B20 that is no longer fitted — and it
stays because renaming the entity would orphan its history in Home Assistant.
Nothing about the wiring changes; it is worth knowing when you go looking for
the entity.

### No DS18B20 on this node

The probe used to sit on D2 with a 4.7 kΩ pull-up. The battery divider below
needs the same pad, and there is no second candidate (see *Battery sense*), so
the probe came off. If you are rebuilding an older board: **remove the 4.7 kΩ**,
or it will pull the divider's tap towards 3V3 and every voltage reading with it.

The DS18B20 driver and its node slot are still in the firmware — the pin is a
per-node choice, and the build fails if any node ever enables both.

### Power

A LiPo on `B+`/`B-` through the XIAO's onboard charger. This is the only battery
node: it cold-boots out of deep sleep every couple of seconds, reads the load
cell, and only brings up Wi-Fi when there is weight on the pan or the heartbeat
is due.

Two consequences for how you build it:

- **The 5V pad is dead** on battery, which is why the SDS011 is not on this node.
- **Keep the sensors on 3V3 from the XIAO**, so they go down with it in sleep.

Recharging means opening the box and spending another cycle on a USB port that
has already failed once out there. Fitting a panel instead — which panel, which
charger, and why not the XIAO's own — is worked out in [solar.md](solar.md).
None of it is built.

#### Protection board

The XIAO charges the cell but does **not** protect it: there is no low-voltage
cutoff, so a flat battery keeps being drained until it is damaged. Unless your
pack already has a protection PCB tucked under the tape at the tab end — many
do — put a 1S board inline between the cell and the board.

```
LiPo  +  ──►  B+  ┌──────────────────┐  P+  ──►  XIAO  B+
                  │  1S protection    │
LiPo  −  ──►  B−  └──────────────────┘  P−  ──►  XIAO  B−
                      (B = battery)        (P = load)
```

**Read the silkscreen before soldering.** Plenty of 1S boards expose only three
pads — `B+`, `B-`, `P-` — because the positive rail passes straight through and
the MOSFETs switch the *negative* side. On those, the XIAO's `B+` comes from the
board's `B+` and only the negative goes through `P-`. Both layouts are fine;
wiring one as though it were the other is not.

Solder the board to the cell first (`B-`, then `B+`), insulate it, and only then
run the load wires to the XIAO — a bare 2000 mAh pouch will deliver tens of amps
into a slipped iron. Nothing on the XIAO side has reverse-polarity protection.

What such a board does **not** do is keep the cell healthy. The common DW01A-class
part cuts off around 2.4-2.5 V, far below the ~3.0 V where a LiPo starts losing
capacity for good. It is a safety device against fire and deep-discharge damage,
not a longevity one. Noticing the difference is what the divider below is for.

#### Battery sense

**The XIAO has no battery-sense path at all** — `B+` reaches the charger and the
regulator, never an ADC — so reading the cell means fitting a divider:

```
  XIAO B+ (= P+)
        │
      [ R1 ]  100 kΩ
        │
        ├──────────────────►  D2 / GPIO4
        │
        ├────────┐
        │        │
      [ R2 ]   [ C ]
      100 kΩ   100 nF
        │        │
  XIAO GND ──────┴───────  (= P−)
```

As a netlist, which is harder to misread than any diagram:

| Part | From | To |
| --- | --- | --- |
| R1 100 kΩ | XIAO `B+` | node **A** |
| R2 100 kΩ | node **A** | XIAO `GND` |
| C 100 nF | node **A** | XIAO `GND` |
| wire | node **A** | XIAO `D2` |

Node **A** is the tap: four legs meet there, and the two resistors are always in
series between `B+` and ground — never a bridge across one of them.

**Why D2, and why it costs the probe its pin.** The divider needs an ADC1 input.
On the ESP32-C3 those are GPIO2/3/4 = `D0`, `D1`, `D2`, and the HX711 has the
first two. `D3` is on ADC2, which is unusable while Wi-Fi is up, so `D2` is the
only candidate — and the DS18B20 wanted it. The SHT31-D measures air temperature
anyway. `node.rs` fails the build if a node ever asks for both.

**Why the foot goes to `GND` and not to the cell.** The XIAO's ground is the
protection board's `P−`, the switched side. Tie the divider there and the
low-voltage cutoff switches it off along with everything else; tie it straight to
the cell's `B−` and it keeps drawing ~21 µA *after* the cutoff — exactly the deep
discharge the board was fitted to prevent.

**Numbers.** 4.2 V full becomes 2.1 V at the pin, 3.0 V empty becomes 1.5 V; both
sit inside the ~2.5 V that 11 dB attenuation spans, with no over-range while
charging. The 100 nF supplies the ADC's sampling charge, so the 50 kΩ source
impedance does not skew the reading. Standing draw is ~21 µA, about 184 mAh a
year — roughly 9 % of a 2000 mAh pack. Two 1 MΩ resistors would cut that to ~2 µA
if it ever matters.

Use 1 % metal film. The firmware calibrates the *ADC* against the chip's eFuse
reference, so readings arrive in millivolts already corrected for that part — but
nothing corrects the resistors. If a multimeter disagrees, the fix is
`R_TOP_KOHM` / `R_BOTTOM_KOHM` in [`src/battery.rs`](../src/battery.rs) and a
reflash; there is no runtime knob for it yet.

The reading is published as `smarthome/terrasse/battery_voltage`, and the log warns
below 3.0 V. A reading under 2.0 V is not published at all — that is not a flat
cell, it is a divider that is not there, and it says so:

```
battery reads 41 mV, which is no cell at all — check the divider is fitted
between B+ and GND with its tap on D2, and that a cell is connected
```

### Outdoors

Nothing on this node is waterproof, so all of it needs an enclosure — but the
SHT31-D needs to *breathe*, or it reports the humidity of the inside of your box.
A vent with a membrane, or a shielded underside opening, not a sealed lid.

**Expected at boot:**

```
node 'terrasse' (Terrasse) booted, battery profile
provision topic: smarthome/provision/a1b2c3d4e5f6
SHT31-D found at 0x44
HX711 raw reading: 8402913
battery = 4.03 V
```

The node's build-time name and its id are the same string, `terrasse`, as they
are for every node in the fleet. That was not always so: this node answered to
`draussen` while its id — and so its topics — said `scale`, a leftover from
before the fleet existed. Provisioning still compares by **id** rather than by
name, so the two are free to diverge again without a board re-provisioning
itself in a loop.

---

## Which pads stay free

Useful if you want to add something, or are checking you have not double-booked
a pin:

| Node | Free pads |
| --- | --- |
| `bad`, `kueche` | D0, D1, D2, D3, D8, D10 |
| `schlafzimmer` | D0, D1, D2, D3, D8, D10 |
| `wohnzimmer` | D0, D1, D2, D8 |
| `terrasse` | D3, D8, D10 |

`D6`, `D7` and `D9` are excluded everywhere: console UART and the BOOT button.

## Before you power it up

1. Continuity from every module's GND to the XIAO's GND.
2. No 5 V anywhere near a GPIO — only the SDS011's supply pin.
3. SDA and SCL not swapped (the single commonest mistake on these boards).
4. SDS011 TX→RX crossed.
5. On `terrasse`: the divider's foot on the XIAO's `GND` (the protection board's
   `P−`), not on the cell's `B−` — and no 4.7 kΩ left over from a DS18B20 on D2.

Then plug in USB and watch the log — every node reports what it found on its
buses within the first second of booting, which is precisely so that a wiring
mistake is visible before the first reading is even attempted. See
[FLASHING.md](../FLASHING.md) for getting the firmware onto the board, and
[the platform notes](base-platform.md) for why the fleet is shaped this way.

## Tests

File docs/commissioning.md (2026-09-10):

# Commissioning log

What is physically built, on which board, and what still has to happen to it.

The rest of `docs/` describes how the firmware is *meant* to work. This page
records the state of the actual hardware, which nothing in the code can tell
you: a node's slot being `Slot::on()` says a sensor is expected, not that one
is soldered on.

Keep it honest rather than complete. A stale entry here is worse than a missing
one, because it will be believed.

---

## Boards

Identified by the MAC in the USB serial descriptor, which is also what
`espflash board-info` reports. **Check it before flashing.** Two boards were
plugged in at once during the 2026-09-04 session and the wrong one got written;
the MAC is the only thing that distinguishes them, and reading it takes a
second.

| MAC | Node | Power | Address |
| --- | --- | --- | --- |
| `e0:72:a1:18:e2:c0` | `terrasse` | battery | 192.168.1.81 |
| `ac:27:6e:80:51:f8` | `wohnzimmer` | mains | — |
| `ac:27:6e:82:43:94` | `kueche` | mains | 192.168.1.30 |
| `ac:27:6e:7e:10:a0` | `schlafzimmer` | mains | — |
| `ac:27:6e:7f:a6:b4` | `bad` | mains | — |

Complete as of 2026-09-10: the last two were read off `espflash board-info`
during the RSSI rollout, so every board in the fleet is now identifiable
without opening anything.

---

## `terrasse` — outdoor, battery

Replaced the node formerly called `draussen`. It carries the bird-feeder scale.

**Verified on hardware 2026-09-04:**

- **HX711** on `D0`/`D1`. Resting readings scatter about ±70 counts out of a
  ±8.4M range — a clean, low-noise chain. A press produced a real presence
  edge: `visit` is published only on the arrival path, so seeing it proves the
  threshold crossing fired and `watch_visit` ran through the press.
- **SHT31-D** at `0x44`, no prefix — it owns the plain `temperature` and
  `humidity` keys.
- **Battery divider** on `D2`, reading 4.11 V off the XIAO's charger with no
  cell fitted. That is the check worth doing before connecting a LiPo: it
  proves the divider is wired and scaled while nothing is at stake.

**Verified on hardware 2026-09-06:**

- **The cell is connected and the node runs on it.** With USB unplugged it
  keeps publishing, `battery_voltage` included, which is the only proof that
  matters — the divider sits on the rail the charger drives, so a reading near
  4.1 V with USB attached is indistinguishable from the 4.11 V measured above
  with no cell at all.
- **It charges.** 3.80 V before a short USB session, 3.93 V after.

**Verified on hardware 2026-09-10 — the scale is calibrated:**

- **Zero taken in the working position**, hanging outdoors with the bird house
  fitted and empty. The mount's own load, the cord tension and the beam's
  orientation all enter the raw value, so a zero taken on the desk would carry
  that whole difference as a standing error. Residual reading afterwards:
  0.5–2.1 g, about a thousandth of the calibration mass.
- **`scale_factor` = 1862.8 ticks/g**, from 545 g of known mass reading 2417.2
  with the placeholder 420 still in place. Verified by the same mass reading
  **545.2 g** afterwards — 0.04 % out.
- **The bird house and mount weigh 451 g**, which is what the +1999 g jump on
  hanging it works out to once the factor is right. Worth writing down as the
  sanity check it is: an implausible number here means the factor is wrong.
- **The threshold was too sensitive, not too coarse.** With the placeholder
  factor, `threshold_grams: 10.0` amounted to `10 × 420 / 1862.8` ≈ **2.3 g** of
  real mass. That, not a mechanical fault, is what had the node publishing
  visits all day against an uncalibrated scale.

### Taring adopts the presence baseline, not a fresh reading

`Config::apply` sets `offset = tare_ref`, and `main` passes `state::baseline()`
— the persisted presence baseline, not a reading taken when the button is
pressed. Two consequences decide the whole procedure:

**Press it only after the baseline has caught up.** Hanging the house is a load
far above the threshold, so the node reads `Arrived`/`Staying` and only absorbs
it into the baseline once `STUCK_AFTER_SECS` (600 s) has passed. Tare before
that and it copies a stale zero.

**Removing a calibration mass leaves the baseline stuck.** Once absorbed, taking
the mass off is a large *negative* delta: `decide` classifies it as
`Unexplained`, which deliberately leaves the baseline alone, and nothing else
ever moves it back. Tare in that state would copy the mass-inclusive value and
show roughly minus its weight.

The way out needs no physical access. Raise `threshold` far enough that the step
lands inside the drift band (`threshold/4`) — 3000 g for a 545 g mass — let the
`Quiet` drift pull the baseline back, then set it to 10 g again. The drift keeps
15/16 of the error per 2 s round, so 600 s is 300 rounds and
`(15/16)^300 = 3.9e-09`: from 1 015 226 ticks that leaves 0.004 ticks. The
firmware accepts any finite `threshold ≥ 0` over MQTT; the 500 g maximum is
only the Home Assistant slider's.

### The socket is wired with the colours crossed, and that is correct

On this pigtail, **black goes to `B+` and red to `B−`.**

That looks wrong and is not. The JST-PH housing is keyed, so the cell's plug
mates one way only; what is *not* standardised is which contact of the housing
carries positive. This pigtail was made with the opposite convention from the
cell's plug, so matching the colours at the solder joints would have mated them
backwards. **Decide this by continuity and a voltmeter, never by wire colour** —
probe which socket contact reaches `B+`, then check the cell's plug puts red on
that contact.

### A reversed cell reads exactly like a broken divider

It was mated backwards the first time. Nothing was damaged and the cell stayed
cold, but the failure was thoroughly misleading and cost an evening:

1. The 1S protection board **latched off**. `P+`/`P−` collapsed to 1.2 V while
   the cell's own terminals still held 3.8 V.
2. The divider sits on the *protected* rail by design (see the module note in
   [`src/battery.rs`](../src/battery.rs)), so it measured that dead rail and
   reported **exactly 0 mV** — tripping the firmware's "no cell at all — check
   the divider is fitted" warning.
3. The board went on running the whole time, because it was on USB.

So the symptom was a firmware message naming the divider, on a node that was
otherwise healthy, with an intact divider. **0 mV does not distinguish "divider
open" from "protected rail dead."** The signature that separates them is
measuring the two rails against each other: **3.8 V at the cell, 1.2 V at
`P+`** can only be the protection board.

Recovery needed no soldering: plugging in USB applies the charger's voltage
across `P+`, which is the ordinary way to unlatch a DW01A-class board. It went
1.2 V → 4.1 V and has behaved since. The protection did its job — it shut off
instead of dying.

**Not done:**

- **Not calibrated.** `offset` is the factory default, so weight publishes as
  roughly -20 kg. Calibration is `tare` on an empty, mounted pan and then
  `scale_factor` against a known mass, both over the Home Assistant knobs, no
  reflash. It waits on the enclosure.

**Answered 2026-09-09 — the runtime config path was broken, and is fixed:**

`deep_sleep = 0` sat retained on the broker for days and never took effect.
The cause was two `subscribe_to_topic` calls in a row in `publish_samples`.
`rust-mqtt` polls for its own SUBACK and discards anything else that arrives —
*"If an application message comes at this moment, it is lost"*, says
`client.rs:145`, and then it returns an error. So the second subscribe swallowed
the retained config the first one had just asked for. Deterministic, whenever
retained config existed.

It now sends one SUBSCRIBE carrying both filters. Verified on hardware:
`config: heartbeat_interval = 660` followed by `config updated and saved to
flash`. That matters here beyond the flag, because **`tare` and `scale_factor`
go through the same code** — the calibration above could not have landed.

**Five things that cost an evening, so that they do not cost another one:**

- **An address that ACKs while every command NAKs means VCC, not the bus.**
  Verified 2026-09-09, and it cost most of a night. The log said these two
  things at once, every cycle, and they read as a contradiction:

  ```
  WARN - no SHT31-D at 0x44 or 0x45
  INFO - I²C scan: 0x44 answered
  ```

  The sensor's **VCC wire was loose**. With the supply open the chip still
  draws a trickle through the ESD diodes on SDA and SCL, which sit on the bus
  pull-ups to 3V3 — enough to run the address comparator and return an ACK,
  nowhere near enough to execute a command or a conversion. The scan writes
  zero bytes (address only) and passes; the probe writes address plus two
  command bytes and fails. The fault lives exactly in that gap.

  Everything that looked strange follows from it: the sensor recovered
  spontaneously at 22:36:53 while the load-cell readings went unsteady — the
  wire making momentary contact as the node was handled — and only this node
  was affected, because it is a wiring fault and not a driver one. Swapping the
  sensor fixed it; the first full reading set in the session arrived at
  23:29:28 (25.5 °C, 43.1 %).

  **So: when a device answers its address but nothing else, check its supply
  before suspecting the bus, the pull-ups or the driver.** A dead bus fails the
  scan too, which is the distinction the scan exists to draw.

  Recorded against a wrong turn, for honesty: this was first blamed on the
  SHT31's soft reset never being issued (`CMD_SOFT_RESET` was defined and
  unused). That change shipped anyway — it is correct and datasheet-conformant
  — but it is **not** what fixed this, and flashing it changed nothing.
- **The tare baseline lives in RTC RAM** and is taken on the first boot after a
  power cycle. The beam has to be left completely alone for that boot. Taring
  while handling it captured a loaded state and left the node 38k ticks off —
  far outside the drift band and far below the threshold, so every poll landed
  in `Decision::Unexplained` and the baseline was, correctly, never absorbed.
  There is no way out of that except another power cycle.
- **A battery node's USB port enumerates only in flashes.** The earlier note
  here said it does not enumerate at all; that was wrong. It appears for a
  fraction of each 2 s poll cycle. Polling `/dev/ttyACM*` every **20 ms** and
  reading it passively catches whole log lines, including the heartbeat window
  where Wi-Fi comes up; polling every 200 ms mostly misses. Verified
  2026-09-06. Flashing still needs the boot window right after plugging in, or
  the BOOT/RESET hold, and `espflash monitor` is still the wrong tool — see
  [`FLASHING.md`](../FLASHING.md).
- **Never debug this node on USB with the cell disconnected.** Verified
  2026-09-09, after an evening spent on the wrong three theories. The LiPo is
  what buffers the radio's TX bursts; without it the board browns out and
  resets at the first transmission, and the failure is silent in the worst way:
  the serial log ends on `Wi-Fi modem sleep: max`, which `main.rs` prints
  immediately *before* `connect_async().await`. So output stops at the first RF
  current peak, the USB port vanishes, and the board reboots — with **no**
  `Connected to Wi-Fi` and, crucially, **no `connect to … failed (attempt N)`
  either**. Nothing is failing to join; it never gets that far. The SHT31-D
  fails the same way at the same time, logging the contradictory pair
  `no SHT31-D at 0x44 or 0x45` and `I²C scan: 0x44 answered`. Reattach the cell
  and both come back at once: 4.09 V, 24.5 °C, 38.9 %.

  Two hours went into the credentials before that. They were never the problem
  — the boot banner reads `wifi: 'wifi_42_ext' (built in)`, `.env` agrees, the
  network scans at signal 84 on 2.4 GHz, and nothing is stored in flash, so
  `clear` is a no-op. That banner is printed before the console window and is
  almost impossible to catch, since the C3 discards serial output no host is
  reading yet; it took five cold boots to see it once.
- **Discovery used to be announced once per *power cycle*, and that was not
  something power could be relied on to reset.** A boolean in RTC RAM said
  "already announced"; it survived deep sleep, a reflash, a reset — and, as the
  living-room node showed on 2026-09-09, several seconds with the USB cable out.
  Its entities were simply missing while its readings kept arriving. Discovery
  is now gated on a digest of every message it would send
  (`discovery::announcement_tag`), so a changed entity set re-announces itself
  and a stale word in RTC RAM fails to match by construction.

---

## `wohnzimmer` — mains

**Verified on hardware 2026-09-05**, all three sensors and both buses:

- **SHT31-D** at `0x44`.
- **SDS011** on `D3`/`D10`, crossed correctly. Both raw and humidity-corrected
  values arrive, and the correction is visibly doing something — the corrected
  figures sit below the raw ones, which is what the κ term should do at that
  humidity. It needs the SHT31 on the same board, which is the whole reason the
  particulate sensor lives here rather than in the kitchen.
- **SCD41** at `0x62` — verified with a unit **borrowed from
  `schlafzimmer`, which has since gone back**. The slot stays on: the fleet
  plan says this node has one, there simply is no second unit yet. Its three
  entities read unavailable in Home Assistant until one arrives.

**When assembling:** keep the SHT31-D away from the board. On this node that
matters twice over, because the particulate humidity correction reads *its*
humidity — a board-warmed SHT31 reports a relative humidity that is too low, the
correction then subtracts too little, and the error lands in the PM figures.

The SDS011's fan needs a clear air path. Its 15-minute cadence protects the fan
and the optics; a sealed enclosure would have it measuring the enclosure.

---

## `kueche` — mains

SHT31-D only, verified 2026-09-04. Nothing outstanding.

---

## Open across the fleet

- **`terrasse` still runs firmware without `rssi`.** The other four were
  flashed 2026-09-10 and report on every round: `bad` −58, `kueche` −49,
  `schlafzimmer` −49, `wohnzimmer` −58 dBm. All four sit in the top bar, so the
  indicator has not yet been read against a link that is actually weak — which
  is the case it exists for. `wohnzimmer` alternates −58/−61 and therefore
  straddles the three-bar threshold (`>= -61`), so its tile will flicker between
  three bars and two.

  Flashing `terrasse` needs the listener loop in
  [`../FLASHING.md`](../FLASHING.md), and it is safe for the calibration:
  `espflash` reported `Segment at address '0x0' has not changed` and the same
  for `0x8000` on all four boards, and the config blob lives at `0x9000` in the
  `nvs` partition, which a plain `espflash flash` never touches. The boot log
  confirms the layout: `boot: 0 nvs WiFi data 01 02 00009000 00006000`.
- **A newly announced entity loses its first reading.** Not a fault, but it
  cost an hour of misdiagnosis: `bad` showed `sensor.bad_signal` as
  `unavailable` while temperature and humidity published normally, and the
  serial log proved the node had read and published the value. Home Assistant
  had not finished creating the entity when the non-retained QoS0 state
  arrived. See the module docs in `src/discovery.rs`. On a battery node that gap
  lasts a full round, i.e. ten minutes.

- **Nothing has had its current measured.** Every battery figure in
  [`base-platform.md`](base-platform.md) is estimated from datasheets around a
  single measured number (a 269 ms boot). Both radio options recorded there stay
  parked behind that measurement, including the cheap one.
- **Solar for `terrasse`: panel and charger ordered 2026-09-08**, nothing built.
  Waveshare 18 V / 10 W panel and a Soldered CN3791 MPPT board (SKU 333136).
  **The board charges at 3 A as shipped** — `R8` has to come off and be replaced
  with 1.2 Ω before it is ever connected to a cell. Parts list and reasoning in
  [`solar.md`](solar.md). It depends on the same missing measurement as the
  radio options, and on the battery divider actually having been flashed —
  that divider is the only instrument that can say whether the panel works.
- **The stored-credential fallback cannot fire on a battery node.**
  `wifi::FALLBACK_AFTER` is meant to set aside stored credentials after three
  consecutive refusals and fall back to the built-in pair, so a typo at the
  console cannot strand a board. But `refusals` in `main.rs` is a task-local,
  and its comment says it is deliberately *not* in RTC RAM: *"a power cycle
  should give them another try"*. That reasoning holds for a mains node. A
  battery node cold-boots every couple of seconds, so every wake is a new run
  with `refusals = 0` and the threshold of three is never reached. The
  protection is inert for precisely the node that hangs outdoors and cannot be
  reflashed casually. Not the cause of anything so far — nothing is stored on
  `terrasse` — but it is a trap set for later.
- **Bad and kueche drop temperature occasionally, and it is not Wi-Fi.**
  Reported from the field 2026-09-09, previously blamed on the network. Those
  nodes lose a reading now and then while staying connected, which points at
  `sample()` rather than the boot-time probe: `CONVERSION_MS` was 15 ms against
  a datasheet maximum of **15.5 ms** for high repeatability, so an occasional
  read lands before the conversion finishes, is NAKed, and reports a working
  sensor as absent. Raised to 17 ms.

  **The overnight A/B test that was meant to confirm this did not.** Only
  `terrasse` carried the fix; the four mains nodes ran the old image. Over
  8.3 hours (2026-09-09 23:00 → 2026-09-10 07:20) the count of missed readings
  was:

  | node | cadence | missed |
  | --- | --- | --- |
  | bad | 120 s | 0 |
  | kueche | 121 s | 0 |
  | schlafzimmer | 61 s | 0 |
  | wohnzimmer | 61 s | 1 |
  | terrasse (fixed) | — | 0 |

  Every apparent dropout was **one event at 03:10**, hitting all five nodes
  within 40 seconds — schlafzimmer 03:10:05, kueche 03:10:32, terrasse
  03:10:39, bad 03:10:43, wohnzimmer 03:10:45. Independent sensors do not fail
  synchronously, so that was the network, the broker, or the capturing client,
  not the driver.

  So the test is **inconclusive rather than negative**: the control group stayed
  healthy all night, and a fault that does not occur cannot be measured. That is
  consistent with the report, which said *sometimes*. If it is conversion time,
  temperature is a plausible trigger — the SHT31's conversion drifts with it,
  and a cool quiet night is the friendly case, unlike a bathroom after a shower.

  **Flash the other four on the datasheet argument, not on this evidence.**
  15 ms under a 15.5 ms maximum is wrong whether or not it bit last night.
  Proving it needs a capture over days, long enough for the rare case to appear
  and show that it only hits the unfixed nodes.
- **Mains nodes self-heat.** Measured 2026-09-04 on `schlafzimmer`: about 0.9 °C
  at the board, separated from room warming by using the unmoved SCD41 as a
  control. Mount temperature sensors away from the board on any node that
  reports one.

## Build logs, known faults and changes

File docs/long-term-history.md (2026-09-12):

# Keeping the fleet's data for years

What it costs to keep every reading, what the retention should actually be, and
the three things that threaten a long series once storage stops being the
problem. The service that does the keeping is
[`timeseries/`](../timeseries/README.md); this is the reasoning around it.

## What the fleet produces

Thirty-one channels, at the cadences `node.rs` configures:

| Node | Channels | Every | Per day |
| --- | --- | --- | --- |
| `schlafzimmer` | temperature, humidity, co2, scd41_temperature, scd41_humidity, rssi | 60 s | 8,640 |
| `wohnzimmer` | the same six minus co2's siblings, plus voc_index, nox_index | 60 s | 11,520 |
| `wohnzimmer` | pm25, pm10, pm25_raw, pm10_raw | 900 s | 384 |
| `kueche`, `bad` | temperature, humidity, rssi | 120 s | 2,160 each |
| `terrasse` | weight, visits, temperature, humidity, battery ×2, rssi | ~600 s | ~1,000 |

**≈ 25,900 readings a day.**

## What that costs on disk

Measured rather than estimated: three days of exactly that shape were written
into QuestDB 9.3.5 and the finished daily partition read back.

```
2026-09-10    25,872 rows    828 KB    ≈ 32 bytes/row
```

Thirty-two bytes is what the columns come to — an 8-byte timestamp, two 4-byte
symbol references, an 8-byte double — plus the symbol index. So:

| | Raw | With the rollups (estimated) |
| --- | --- | --- |
| 1 year | 0.3 GB | ~0.8 GB |
| 3 years | 0.9 GB | ~2.4 GB |
| 10 years | 3 GB | ~8 GB |

The rollup figure is arithmetic, not measurement: `_1m` holds about as many rows
as the base table with four more columns per row, and `_1h` (≈740 rows/day) and
`_1d` (31 rows/day) are noise beside either.

> **Do not read the size off the active partition.** QuestDB pre-allocates
> append space, so `table_storage()` reported 81 MB for the day being written
> while the finished neighbour beside it was 828 KB. The number only settles
> when the partition closes.

## What follows: three years is too short

`retention = "3y"` was chosen before any of this was measured. At 0.3 GB a year
it is not a storage decision, and the rollups exist for *speed*, not for space —
a full-range chart reads `_1d` either way.

**The intended shape is raw for a few years, rollups for ever.** A year-on-year
comparison in 2032 reads 31 rows a day; there is no reason for that to expire.
That needs one change to the service: retention is currently a single value
applied to the base table and every view alike, and it should be per tier.

## What actually threatens a long series

### Gaps, when the archiver is not running

The nodes publish at **QoS 0** (`main.rs`). A QoS 0 message is never queued for
an absent subscriber — not with a persistent session, not with a QoS 1
subscription, because delivery happens at the lower of the two. Every restart of
the archiver, every deploy, every crash is therefore a hole in the series, and
nothing on the broker side can close it.

Fixing it properly would mean publishing at QoS 1, which costs a battery node an
extra round trip per reading — the wrong trade for the node that is hardest to
keep alive. So the mitigations are ordinary ones: run the archiver on the same
host as the broker, keep restarts short, and remember that Home Assistant's
recorder is a second subscriber holding the last ~10 days independently.

A hole is at least visible: the chart simply has no points there.

### Backups that are not backups

`/var/lib/questdb` is the directory that matters, and copying it while the
database is running is a coin flip — the WAL may be mid-apply. QuestDB has
`SNAPSHOT PREPARE` and `SNAPSHOT COMPLETE` for exactly this: prepare, let the
backup run over the directory, complete. Without that pair, a restore is
untested by construction.

This is the only item on this page whose absence goes unnoticed until the day it
matters.

### A series nobody can interpret in three years

The data will outlive the memory of what happened to the hardware. The step in
the terrace's weight on 2026-09-09 was a recalibration. The CO₂ offset changed
when an SCD41 was replaced. The living room's VOC index starts at 1 and climbs
for a day because the algorithm is learning the room, not because the air is
improving.

None of that is in the numbers. A small `annotations` table — timestamp, node,
one sentence — or even a dated list in this repo is what turns a pile of
readings into a measurement series. It is the cheapest thing here and the one
most likely to be skipped.

## The order of work

1. **Deploy the archiver.** It is built and verified against a real QuestDB, and
   runs nowhere. The NixOS module is in `timeseries/nix/module.nix`; the home
   server needs the flake input, the module import, an MQTT password as a
   secret, and a proxy entry. Everything below is hypothetical until this is
   done.
2. **Retention per tier** — raw 3 years, rollups without expiry.
3. **Snapshot-aware backup** of `/var/lib/questdb` in the existing borg run.
4. **Annotations**, starting with the events already known from this month.
5. Optionally, once the archive has been running a while: trim Home Assistant's
   recorder to ~10 days. Its job becomes the live view; the history lives here.

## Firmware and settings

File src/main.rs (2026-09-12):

//! rs-smarthome-nodes — async firmware for a fleet of ESP32-C3 sensor nodes.
//!
//! One image serves every node: which sensors are populated, what the node is
//! called and how it is powered come from [`node`], picked by `NODE=<name>` at
//! build time or by a provisioned identity in flash. It started life as a
//! battery bird-feeder scale, and that node — now `terrasse`, the default —
//! still drives the flow described below.
//!
//! **Battery profile** — to catch short bird visits without keeping the radio
//! awake, the firmware polls by cold-booting out of deep sleep on a short
//! interval and only spends Wi-Fi energy when weight is actually on the scale:
//!   1. Bring up the HAL + Embassy executor (TIMG0).
//!   2. Read a raw weight sample from the HX711 (with a timeout, so a missing
//!      sensor can't wedge the boot).
//!   3. Compare against the tare baseline persisted in RTC RAM across sleep:
//!        - empty house  -> drift-correct the baseline, skip Wi-Fi, deep-sleep
//!          a short *idle* interval to catch the next visit;
//!        - weight present -> join Wi-Fi (STA + DHCP), publish every populated
//!          sensor over MQTT, deep-sleep a longer *active* interval to keep
//!          tracking. A final reading is published on the falling edge when the
//!          bird leaves.
//!
//! **Mains profile** — indoor air-quality nodes stay associated and sample on a
//! fixed cadence instead, because CO₂ continuity and the SDS011's duty-cycled
//! fan both rule out deep sleep.
//!
//! Home Assistant discovers every node's entities over retained MQTT config
//! messages (see [`discovery`]); calibration and tuning live in flash and are
//! updated live from Home Assistant (see [`config`]).

#![no_std]
#![no_main]

use core::time::Duration as CoreDuration;

use embassy_executor::Spawner;
use embassy_net::{tcp::TcpSocket, Config as NetConfig, Ipv4Address, Stack, StackResources};
use embassy_time::{with_timeout, Duration, Instant, Timer};
use esp_backtrace as _;
use esp_hal::{
    clock::CpuClock,
    delay::Delay,
    efuse::Efuse,
    gpio::{Input, Level, Output, OutputOpenDrain, Pull},
    peripherals::{LPWR, RADIO_CLK, RNG, TIMG1, WIFI},
    reset::software_reset,
    rng::Rng,
    rtc_cntl::{sleep::TimerWakeupSource, Rtc},
    timer::timg::TimerGroup,
    usb_serial_jtag::UsbSerialJtag,
};
use esp_wifi::{
    config::PowerSaveMode,
    wifi::{
        ClientConfiguration, Configuration, WifiController, WifiDevice, WifiEvent, WifiStaDevice,
        WifiState,
    },
    EspWifiController,
};
use log::{info, warn};
use rust_mqtt::{
    client::{client::MqttClient, client_config::ClientConfig},
    packet::v5::publish_packet::QualityOfService,
    utils::rng_generator::CountingRng,
};

use node::Provision;
use rs_smarthome_nodes::{
    battery, config, discovery, ds18b20, hx711, node, platform, presence, rssi, sensors::scale,
    state, wifi,
};

use battery::Battery;
use config::Config;
use ds18b20::Ds18b20;
use hx711::Hx711;
use platform::{Samples, Sensors};

/// The concrete network-stack type used throughout the firmware.
type WifiStack = Stack<WifiDevice<'static, WifiStaDevice>>;

// --- Compile-time configuration --------------------------------------------
// Override the credentials at build time, e.g.:
//   SSID=MyNet PASSWORD=hunter2 cargo run --release
// The MQTT broker address is edited here directly.
const SSID: &str = match option_env!("SSID") {
    Some(s) => s,
    None => wifi::PLACEHOLDER_SSID,
};
const PASSWORD: &str = match option_env!("PASSWORD") {
    Some(s) => s,
    None => "your-password",
};

/// Optional MQTT broker credentials, baked in at build time (see .env).
/// When unset the client connects anonymously, so an auth-free broker still
/// works out of the box.
const MQTT_USER: Option<&str> = option_env!("MQTT_USER");
const MQTT_PASSWORD: Option<&str> = option_env!("MQTT_PASSWORD");

/// Home Assistant / Mosquitto broker on the LAN. Baked in at compile time from
/// the `MQTT_BROKER` env var (see `.env` / `.env.example`), like the Wi-Fi
/// credentials. It is a private LAN IP, not a secret, but keeping it out of
/// source is cleaner; the default keeps a plain `cargo build` working.
const MQTT_BROKER: Ipv4Address = parse_ipv4(match option_env!("MQTT_BROKER") {
    Some(s) => s,
    None => "192.168.1.67",
});
const MQTT_PORT: u16 = 1883;

/// Const-parse a dotted-decimal IPv4 string (e.g. `"192.168.1.67"`) into an
/// [`Ipv4Address`] at compile time, so `MQTT_BROKER` can come from an env var.
const fn parse_ipv4(s: &str) -> Ipv4Address {
    let o = parse_octets(s);
    Ipv4Address::new(o[0], o[1], o[2], o[3])
}

/// The dotted-decimal → four-octet core, split out so it can be checked at
/// compile time. Lenient by design: extra separators are clamped rather than
/// panicking, so a malformed override yields a wrong (but harmless) address,
/// never a build that fails deep inside const-eval.
const fn parse_octets(s: &str) -> [u8; 4] {
    let b = s.as_bytes();
    let mut octets = [0u8; 4];
    let mut idx = 0;
    let mut cur = 0u16;
    let mut i = 0;
    while i < b.len() {
        let c = b[i];
        if c == b'.' {
            if idx < 3 {
                octets[idx] = cur as u8;
                idx += 1;
            }
            cur = 0;
        } else {
            cur = cur * 10 + (c - b'0') as u16;
        }
        i += 1;
    }
    if idx < 4 {
        octets[idx] = cur as u8;
    }
    octets
}

// Pin the parser against the default broker address at compile time.
const _: () = {
    let o = parse_octets("192.168.1.67");
    assert!(o[0] == 192 && o[1] == 168 && o[2] == 1 && o[3] == 67);
};

// --- Sampling / detection tuning -------------------------------------------
// Topics, the client id and the sensor set come from [`node::active`]; the
// presence threshold and the idle/active poll intervals live in
// [`config::Config`], persisted in flash and tunable live from Home Assistant.

/// How long to wait for the next retained config message after subscribing.
/// Retained values arrive within tens of ms, so once a receive hits this
/// timeout we assume the broker has sent them all and stop draining.
const CONFIG_RECV_WINDOW: Duration = Duration::from_millis(400);

/// How long a cold boot waits for someone at the serial console before carrying
/// on. Short, because it delays every power-up of every node; long enough to
/// paste three lines into a terminal that is already open.
const CONSOLE_WINDOW: Duration = Duration::from_secs(3);

/// The same wait for a board that has no usable credentials at all. It has
/// nothing else it could be doing, so it is worth waiting properly — and after
/// this it boots on and simply fails to join, which is no worse.
const CONSOLE_WINDOW_STRANDED: Duration = Duration::from_secs(120);

/// Config key carrying a tare request. Called out because, unlike every other
/// key, acting on it means deleting the retained message afterwards.
const TARE_KEY: &str = "tare";
/// Config key that forgets the discovery digest; see `REANNOUNCE_CONTROLS`.
const REANNOUNCE_KEY: &str = "reannounce";
/// Config key that zeroes the visit counter. Like the two above it is a button
/// press rather than a setting, so it is consumed rather than stored -- and
/// unlike them it touches RTC RAM instead of the config blob.
const RESET_VISITS_KEY: &str = "reset_visits";

/// Give up on a single HX711 conversion after this long. A disconnected sensor
/// (with `DT` pulled up) never becomes ready, so this bounds the boot.
const HX711_TIMEOUT: Duration = Duration::from_millis(500);

/// Upper bound on the whole Wi-Fi join + MQTT publish. Without it a failed join
/// would spin in the high-power state and drain the battery. Sensor sampling
/// happens before this window, so a slow sensor never eats into it.
const WIFI_BUDGET: Duration = Duration::from_secs(20);

/// How long to wait for the MQTT DISCONNECT and the TCP FIN to actually leave
/// the board at the end of a round. Short on purpose: the readings are already
/// out by then, so this only buys a tidy shutdown, and it is spent inside
/// [`WIFI_BUDGET`].
const SHUTDOWN_BUDGET: Duration = Duration::from_secs(2);

/// Cadence of the gas sensor's sampling step.
///
/// Sensirion's index algorithm is specified for a 0.5-10 s interval and
/// configured here for exactly one second (`sgp41::SAMPLING_INTERVAL_SECS`), so
/// this is not a tuning knob: changing it without changing that constant makes
/// the index wrong rather than coarse. The step itself takes ~50 ms, so the
/// wait is what sets the pace.
const GAS_STEP_INTERVAL: Duration = Duration::from_secs(1);

/// Hard cap on how long one visit keeps the node awake.
///
/// A bird is expected to leave well inside this. The cap exists for a load that
/// does not — snow, a twig, a squirrel that settles in — so a stuck cell can
/// never hold the CPU awake and flatten the cell.
const VISIT_MAX: Duration = Duration::from_secs(60);

/// Consecutive below-threshold samples that end a visit. More than one so a
/// bird shifting its weight for an instant does not read as a departure.
const VISIT_DEPART_SAMPLES: u8 = 3;

/// Samples taken right after the load first crosses the threshold are dropped:
/// the bird is still landing and the cell is still ringing, so they would drag
/// the median toward a weight nothing ever had.
const VISIT_SETTLE: Duration = Duration::from_millis(400);

/// Convenience: allocate a `T` with `'static` lifetime from a `StaticCell`.
macro_rules! mk_static {
    ($t:ty, $val:expr) => {{
        static STATIC_CELL: static_cell::StaticCell<$t> = static_cell::StaticCell::new();
        STATIC_CELL.init($val)
    }};
}

/// The load-cell driver as this board wires it: esp-hal pins and delay. The
/// driver itself names none of those types (see [`hx711`]).
type Scale<'d> = Hx711<Input<'d>, Output<'d>, Delay>;

/// Everything this node can measure. Absent hardware is `None`, so both power
/// profiles run the same sampling code.
struct Board<'d> {
    scale: Option<Scale<'d>>,
    probe: Option<Ds18b20<'d>>,
    battery: Option<Battery<'d>>,
    sensors: Sensors,
}

/// The peripherals needed to bring the radio up, bundled so they can be handed
/// down the call chain in one piece.
struct Radio {
    timg1: TIMG1,
    rng: RNG,
    radio_clk: RADIO_CLK,
    wifi: WIFI,
}

#[esp_hal_embassy::main]
async fn main(spawner: Spawner) {
    // --- 1. HAL & async runtime --------------------------------------------
    let hal_config = {
        let mut c = esp_hal::Config::default();
        // 80 MHz rather than the 160 this chip will do. That is exactly the
        // minimum esp-wifi documents for the radio (`MIN_CLOCK` in its `init`,
        // which rejects anything below it), and dynamic power scales with the
        // clock — so this roughly halves what the core burns while idling in
        // the executor.
        //
        // It is a thermal fix, not a power one. A mains node never sleeps, so
        // whatever the core burns ends up as heat in the enclosure and the
        // sensors read their own board rather than the room: measured against
        // a reference thermometer on `schlafzimmer`, 2026-09-03, the air at the
        // electronics sat ~1 °C above the room.
        //
        // Nothing here needs the speed. A round is a handful of I²C
        // transactions and one MQTT publish, and the I²C and UART baud rates
        // derive from APB, not from the CPU clock, so their timing is
        // unchanged. On a battery node the trade is roughly neutral rather than
        // a win — half the clock means twice as long awake for the same work —
        // but the radio-idle stretches, which dominate a wake, still cost less.
        c.cpu_clock = CpuClock::Clock80MHz;
        c
    };
    let peripherals = esp_hal::init(hal_config);

    esp_println::logger::init_logger_from_env();
    esp_alloc::heap_allocator!(72 * 1024);

    // TIMG0 drives the global Embassy executor (per the hardware spec).
    let timg0 = TimerGroup::new(peripherals.TIMG0);
    esp_hal_embassy::init(timg0.timer0);

    // Who am I? A provisioned identity in flash wins over the one this image was
    // built with. Must happen before any peripheral is touched: the sensor set
    // decides which buses come up at all.
    node::init();
    let node = node::active();

    info!(
        "node '{}' ({}) booted, {} profile",
        node.id,
        node.name,
        if node.power.is_battery() {
            "battery"
        } else {
            "mains"
        }
    );
    // Say where to reach this board if it needs to be told what it is; the MAC
    // is the only name it is sure of before provisioning.
    info!(
        "provision topic: {}",
        node::provision_topic(Efuse::read_base_mac_address())
    );

    // Which network? Credentials stored over the serial console win over the
    // ones compiled in. Resolved before the radio comes up, and before the
    // console window below, so provisioning can report what it is replacing.
    let source = wifi::init(built_in_credentials());
    match wifi::active() {
        Some(credentials) => info!(
            "wifi: '{}' ({})",
            credentials.ssid,
            match source {
                wifi::Source::Stored => "from flash",
                wifi::Source::BuiltIn => "built in",
            }
        ),
        None => warn!("wifi: no credentials"),
    }

    // The escape hatch. Only on a cold boot: a deep-sleep wake skips it, so a
    // battery node pays this once per power-up rather than every two seconds.
    if state::is_cold_boot() {
        console_provisioning(peripherals.USB_DEVICE).await;
    }
    // A `persistent` RTC word is not initialised by the startup code, so a
    // counter that has just been added to the firmware starts at whatever was
    // in that slot. This one fired its stuck-load bound on the first boot after
    // the reflash that introduced it -- harmless, since an arrival resets it,
    // but a legitimate first visit would have been misjudged once. Zero it
    // where a cold boot is already being detected.
    if state::is_cold_boot() {
        state::set_present_rounds(0);
        // Belt and braces only: the visit counter guards itself with a checked
        // pair, because this branch cannot cover the case that actually bit --
        // a reflash keeps RTC RAM, so the first boot carrying a *new* counter
        // is not a cold boot. See `scale::VISITS_MAGIC`.
        state::set_visit_count(0);
    }
    state::mark_booted();

    // Runtime config from flash (calibration + tuning), or defaults on a blank
    // sector. Read now, while the radio is still down. It may be updated from
    // Home Assistant during the publish below and persisted before sleep.
    let cfg = config::load();
    info!(
        "config: offset={} scale={} threshold={}g idle={}s active={}s",
        cfg.offset, cfg.scale_factor, cfg.threshold_grams, cfg.idle_secs, cfg.active_secs
    );

    // --- 2. Sensors --------------------------------------------------------
    // Pin numbers are the raw ESP32-C3 GPIOs; on the Seeed XIAO ESP32-C3 the
    // silkscreen pads map D0=GPIO2, D1=GPIO3, D2=GPIO4 (GPIO0/GPIO1 are *not*
    // broken out). So:
    //   HX711 SCK -> D0 (GPIO2)   HX711 DT -> D1 (GPIO3)   DS18B20 -> D2 (GPIO4)
    // The I²C and UART pins live in `platform.rs` alongside their drivers.
    // `DT` is pulled up so a *disconnected* amp reads permanently "not ready"
    // and times out cleanly instead of returning floating garbage.
    let scale = node.scale.enabled.then(|| {
        let dt = Input::new(peripherals.GPIO3, Pull::Up);
        let sck = Output::new(peripherals.GPIO2, Level::Low);
        Hx711::new(dt, sck, Delay::new())
    });

    // D2 / GPIO4 has two possible jobs and can only do one of them, so exactly
    // one arm below claims the pin:
    //   * the DS18B20's open-drain 1-Wire line (internal pull-up backing the
    //     external 4.7 kΩ), or
    //   * the battery divider's tap, the only ADC1 pad the HX711 leaves free.
    // `node.rs` fails the build if a node asks for both, so the order here can
    // never silently decide it.
    let (probe, battery) = match (node.ds18b20.enabled, node.battery.enabled) {
        (true, _) => (
            Some(Ds18b20::new(OutputOpenDrain::new(
                peripherals.GPIO4,
                Level::High,
                Pull::Up,
            ))),
            None,
        ),
        (_, true) => (
            None,
            Some(Battery::new(peripherals.ADC1, peripherals.GPIO4)),
        ),
        _ => (None, None),
    };

    let mut board = Board {
        scale,
        probe,
        battery,
        sensors: Sensors::new(platform::Peripherals {
            i2c0: peripherals.I2C0,
            sda: peripherals.GPIO6,
            scl: peripherals.GPIO7,
            uart1: peripherals.UART1,
            uart_rx: peripherals.GPIO5,
            uart_tx: peripherals.GPIO10,
        }),
    };

    let radio = Radio {
        timg1: peripherals.TIMG1,
        rng: peripherals.RNG,
        radio_clk: peripherals.RADIO_CLK,
        wifi: peripherals.WIFI,
    };

    // --- 3. Hand over to the power profile ---------------------------------
    // Mains nodes never deep-sleep. Battery nodes normally do, but Home
    // Assistant can hold one awake (`config/deep_sleep`) for bench testing on
    // USB, where deep sleep just churns the serial monitor. Both branches
    // diverge, so exactly one of them runs per boot.
    if !node.power.is_battery() || !cfg.deep_sleep {
        run_awake(spawner, radio, peripherals.LPWR, &mut board, cfg).await;
    }

    run_battery(spawner, radio, peripherals.LPWR, &mut board, cfg).await;
}
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

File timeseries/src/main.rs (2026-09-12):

//! `smarthome-timeseries` -- the long-term memory of the sensor fleet.
//!
//! Home Assistant already sees every node over MQTT auto-discovery, and it
//! keeps a recorder database of its own. What it does not do is keep three
//! years of it: its recorder is tuned for weeks, and the long-run questions
//! this fleet was built to answer -- did insulating the roof change the
//! bedroom's overnight CO2, how does the terrace's temperature swing compare
//! between summers -- need the history to still be there.
//!
//! So this sits beside Home Assistant rather than inside it: one process that
//!
//!   1. follows the same MQTT topics the nodes already publish,
//!   2. writes every reading into QuestDB, which keeps three years of them and
//!      pre-aggregates the history into rollup views, and
//!   3. serves a small dashboard that reads those rollups.
//!
//! Nothing here touches the firmware or Home Assistant's configuration. A node
//! does not know it is being archived, and switching this service off leaves
//! the house working exactly as before.

mod config;
mod model;
mod mqtt;
mod questdb;
mod state;
mod web;

use std::path::PathBuf;
use std::sync::Arc;
use std::time::Duration;

use anyhow::{Context, Result};
use tokio::sync::mpsc;
use tracing::{error, info, warn};
use tracing_subscriber::EnvFilter;

use config::Settings;
use questdb::{schema, Client, Record};
use state::Shared;

/// How long to keep waiting for a database that is not up yet.
///
/// On the home server this process and QuestDB come up together, and systemd's
/// ordering only guarantees that the unit *started*, not that it is answering
/// queries -- QuestDB takes a few seconds to open its tables. Retrying beats
/// failing and being restarted, because a restart loop loses the MQTT
/// subscription too.
const DB_WAIT: Duration = Duration::from_secs(180);

#[tokio::main]
async fn main() -> Result<()> {
    tracing_subscriber::fmt()
        .with_env_filter(
            EnvFilter::try_from_env("SMARTHOME_TIMESERIES_LOG")
                .unwrap_or_else(|_| EnvFilter::new("info")),
        )
        .init();

    let path = settings_path();
    let settings = Settings::load(path.as_deref())?;
    match &path {
        Some(p) => info!(config = %p.display(), "settings loaded"),
        None => info!("no settings file given; using defaults"),
    }

    let client = Client::new(
        settings.questdb_base(),
        &settings.questdb.user,
        &settings.questdb.password,
    )?;
    wait_for_database(&client, settings.questdb_base()).await?;

    let views = schema::ensure(
        &client,
        &settings.questdb.table,
        &settings.questdb.status_table,
        &settings.retention(),
        settings.questdb.rollups,
    )
    .await
    .context("preparing the QuestDB schema")?;

    let shared = Shared::new();
    shared.set_views(views);

    // What the database already knows about who is online, so the retained
    // last-wills that arrive on connect are recognised as old news.
    match questdb::series::fetch_status(&client, &settings.questdb.status_table).await {
        Ok(rows) => {
            for (node, online) in &rows {
                shared.seed_online(node, *online);
            }
            info!(nodes = rows.len(), "seeded availability from the database");
        }
        Err(e) => warn!(error = %e, "could not read the last known availability"),
    }

    // Bounded: if QuestDB stops answering, back-pressure should reach the MQTT
    // loop rather than growing a queue until the machine swaps. Readings the
    // bridge cannot take are lost, which on a live feed is the right trade --
    // the alternative is losing all of them to an out-of-memory kill.
    let (tx, rx) = mpsc::channel::<Record>(4_096);

    let writer = tokio::spawn(questdb::writer::run(
        client.clone(),
        settings.questdb.table.clone(),
        settings.questdb.status_table.clone(),
        Duration::from_secs(settings.questdb.flush_interval_secs),
        settings.questdb.batch_max,
        shared.stats(),
        rx,
    ));

    let bridge = tokio::spawn(mqtt::run(settings.clone(), shared.clone(), tx));

    let app = web::App {
        settings: Arc::new(settings.clone()),
        client,
        shared,
    };
    let listener = tokio::net::TcpListener::bind(settings.web.bind)
        .await
        .with_context(|| format!("binding {}", settings.web.bind))?;
    info!(address = %settings.web.bind, "dashboard listening");

    axum::serve(listener, web::router(app))
        .with_graceful_shutdown(shutdown_signal())
        .await
        .context("serving the dashboard")?;

    // The bridge has no shutdown of its own -- it is a reconnect loop with no
    // state worth saving. The writer does: dropping the sender closes the
    // channel, which makes it flush what is buffered and return.
    bridge.abort();
    info!("flushing the last batch");
    match tokio::time::timeout(Duration::from_secs(30), writer).await {
        Ok(Ok(())) => info!("writer stopped cleanly"),
        Ok(Err(e)) => error!(error = %e, "writer task failed"),
        Err(_) => warn!("writer did not finish within 30 s; exiting anyway"),
    }
    Ok(())
}

/// The settings file: first argument, or `$SMARTHOME_TIMESERIES_CONFIG`, or
/// nothing at all (every default works against a localhost broker and
/// database).
fn settings_path() -> Option<PathBuf> {
    std::env::args()
        .nth(1)
        .or_else(|| std::env::var("SMARTHOME_TIMESERIES_CONFIG").ok())
        .map(PathBuf::from)
}

async fn wait_for_database(client: &Client, url: &str) -> Result<()> {
    let deadline = std::time::Instant::now() + DB_WAIT;
    let mut last_error = None;
    let mut announced = false;
    while std::time::Instant::now() < deadline {
        match client.ping().await {
            Ok(()) => {
                info!(url, "QuestDB is up");
                return Ok(());
            }
            Err(e) => {
                if !announced {
                    info!(url, "waiting for QuestDB");
                    announced = true;
                }
                last_error = Some(e);
                tokio::time::sleep(Duration::from_secs(2)).await;
            }
        }
    }
    Err(last_error
        .unwrap_or_else(|| anyhow::anyhow!("no error recorded"))
        .context(format!(
            "QuestDB at {url} did not answer within {DB_WAIT:?}"
        )))
}
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

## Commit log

2026-09-05 docs: record what is actually built, per board
    The rest of `docs/` describes how the firmware is meant to work. Nothing
    recorded the state of the hardware, and the code cannot stand in for it:
    a slot being `Slot::on()` says a sensor is expected, not that one is
    soldered on. Two nodes were brought up over the last two days and that
    distinction mattered constantly.
    Per board: the MAC that identifies it, what is verified on hardware and
    how, and what is still outstanding. The MAC table earns its place —
    during commissioning two boards were plugged in at once and the wrong
    one was flashed, and the MAC is the only thing that tells them apart.
    The outstanding items are the point of the page as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
2026-09-06 feat: an enclosure for the wohnzimmer air-quality node
    A 145 x 89 x 32 mm tray and lid. Indoors, so none of it is about rain;
    the shape comes from the two constraints docs/commissioning.md already
    records -- keep the SHT31 away from the board, and do not let the
    SDS011 measure its own enclosure.
    Three compartments in a row, split by full-height baffles that double
    as the lid's mid-span support: an 18 mm sensor chamber vented on three
    sides holding the SHT31 and SCD41, 104 mm from the board; the SDS011
    bay; and a fitted pocket for the 33x55x20 board with the cable out
    through the end wall. On this node a board-warmed SHT31 costs twice
    over, because the particulate humidity correction reads i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
    [wohnzimmer_lid.step, wohnzimmer_lid.stl, wohnzimmer_tray.step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]
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2026-09-06 docs: the terrasse cell, and why a reversed one looks like a broken divider
    The cell is connected and the node runs on it: with USB unplugged it
    keeps publishing, battery_voltage included. That is the only proof that
    counts, because the divider sits on the rail the charger drives -- a
    4.1 V reading with USB attached is indistinguishable from the 4.11 V
    this file already records with no cell fitted at all. It charges:
    3.80 V before a short USB session, 3.93 V after.
    Two findings worth the space.
    The socket's colours are crossed on purpose: black to B+, red to B-.
    The JST-PH housing is keyed so the plug mates one way, but which
    contact carries positive is not standardised, and this pigtail w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
2026-09-07 fix: make room in the terrasse box for the cell
    There was nowhere to put the battery, and the fit check that said
    otherwise was measuring the wrong thing: it tested a 103450 cell
    against the *bounding* interior, 42 x 52 x 45, rather than against the
    free space inside it. An occupancy scan over the real solids puts the
    longest clear run at 38 mm with the interior only 10 % occupied -- not
    a volume problem, a shape one. The cell needs 50 mm in some axis and Y
    (52 mm) is the only one that has it, so nothing fitted in any
    orientation.
    The vent chamber was what blocked that run, spanning the middle of the
    -Y wall full height. It moves into the -X/-Y corner and becomes
    L-shaped around the corner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
    [terrasse_body.step, terrasse_body.stl, terrasse_floor.step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]
2026-09-07 fix: resize the terrasse box to the measured parts
    The measured envelopes, plugs included, are 40x30x35 for the ESP board,
    40x25x30 for the HX711, 65x50x10 for the battery and 20x10x10 for the
    SHT31 -- 128 cm3 with clearance, against a 98 cm3 interior. No
    rearranging was going to fix that. A grid packing search puts the
    smallest interior that takes all four at 76 x 66 x 52, and only with
    everything stood on end, so this is 80 x 70 x 55: outer 88 x 78 x 60,
    up from 50 x 60 x 50.
    The battery measurement also supersedes the 103450 the last commit was
    built around, which is why its on-edge lane is gone.
    Everything now mounts to the floor plate and stands up from it, which
    is a print constraint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
    [terrasse_body.step, terrasse_body.stl, terrasse_floor.step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]
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2026-09-07 feat: run the cable slots full height
    The baffle slots were windows at floor level (at roof level on
    terrasse), which means threading a wire through a 4-6 mm gap once the
    boards are already in. They now run the full interior height in all
    three boxes, so a wire drops in from above.
    Worth stating what that costs, because it is the one deliberate hole in
    the thing the baffles exist for. The opening between the sensor
    chamber's air and the electronics' goes from 24 to 330 mm2 on terrasse,
    48 to 288 on wohnzimmer, 35 to 168 on climate -- 5x to 14x. On
    wohnzimmer that lands twice over, since the SDS011's humidity
    correction reads the SHT31 and a board-warmed one under-corrects the PM
    figures. St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
    [climate_tray.step, climate_tray.stl, terrasse_body.step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]
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2026-09-09 feat: bending-beam clamps that hang the feeder on the box's centre line
    The floor has carried an anchor pad since 69e23cf with nothing to bolt to it:
    the clamps models.py started as were retired in f858d60, and the originals in
    d0df819 would not have done. They put the wire hole 27.5 mm out from their own
    screws -- which is where the bar puts it, not where the box hangs.
    Two parts, because one cannot work. Both ends of the bar share the anchor's
    15 mm screw pitch, so a single pair of screws cannot fasten the box and the bar
    at once:
    terrasse_beam_spacer bolts up into the floor's captive nuts (M4) and takes
    the bar's fixed end (M4) 25 mm along, far enough that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
    [climate_lid.step, climate_tray.step, terrasse_beam_hanger.step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]
2026-09-09 docs: the brownout that looked like three different faults
    An evening on terrasse publishing nothing at all. The cause was that it was
    being debugged on USB with the LiPo disconnected: the cell is what buffers the
    radio's TX bursts, and without it the board browns out and resets at the first
    transmission.
    The signature is worth recognising, because it points away from itself. The
    serial log ends on `Wi-Fi modem sleep: max`, which main.rs prints immediately
    before connect_async().await -- so output stops at the first RF current peak,
    the USB port vanishes, and the board reboots. There is no `Connected to Wi-Fi`
    and, more misleadingly, no `connect to ... failed (attempt N)` either: nothing
    is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
2026-09-09 feat: rework the hanger — bolts one end, wire the other, and printable
    Four things changed on terrasse_beam_hanger, three of them because the first
    version was wrong about what the part is for.
    - **80 mm long**, the bar's own length, up from 50.5.
    - **Bolts at one end, wire at the other**, 61.5 mm apart. An intermediate
    version put the wire between the bolts, which has no lever arm at all and
    is mechanically the better place for it -- but the wire has to leave from
    the far end, so the cantilever is the design, not an oversight. The spine
    is therefore the deep section (14 mm) rather than the pad: stiffness goes
    with depth cubed, which limits the damage. What bends d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
    [terrasse_beam_hanger.step, terrasse_beam_hanger.stl, terrasse_beam_spacer.step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]
2026-09-09 docs: the wire leaving from the far end is a requirement, not a compromise
    The comment block in models.py and the README section both described the
    hanger's 61.5 mm lever arm apologetically -- "damage limitation", "not a
    substitute for having no lever at all" -- as though the geometry had been
    settled for rather than specified. It was specified: the wire leaves from the
    far end because that is where the feeder hangs, and the section is dimensioned
    to satisfy that rather than to work around it.
    Reframed so the next reader does not try to "fix" it back to a wire between the
    bolts. The engineering fact underneath is unchanged and still stated, because
    it is the useful part: a cantilever deflec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
2026-09-09 fix: two reasons Home Assistant never learned about the SDS011
    The living-room node published pm25, pm10 and their raw pair to the
    broker for six days with nothing in Home Assistant subscribed to them.
    Two independent faults, both found by chasing that.
    **Discovery was gated on a boolean.** `FLAG_DISCOVERY` said "already
    announced", and it was set while wohnzimmer's sds011 slot was still
    `Slot::off()`. Switching the slot on and reflashing does not change a
    bit that already says yes, so the entity set stayed frozen at what it
    was before 2026-09-03. `state.rs` documented the escape hatch as pulling
    power -- and that does not work either: several seconds with the USB
    cable out came back with t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
    [main.rs]
2026-09-09 fix: issue the SHT31-D soft reset that was defined and never sent
    `CMD_SOFT_RESET` has sat in sht31.rs since the driver was written, with a
    doc comment describing exactly the failure the outdoor node shows -- "clears a
    sensor left in a weird state by a hot restart" -- and nothing ever sent it.
    Same shape as the HX711's power_down() that base-platform.md records as
    "written, documented and then never called".
    The mechanism fits the log. The sensor is powered continuously from 3V3 while
    the MCU beside it cold-boots every couple of seconds, so a restart can land
    mid-transaction and leave the SHT31 part-way through a command. It then still
    ACKs its address while NAKing what follows, which is wh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
    [platform.rs, sht31.rs]
2026-09-09 fix: bound every I²C transaction so a wedged bus cannot reach the watchdog
    SharedI2c::transaction was awaited with no bound of its own. A device holding
    SDA low parks the caller for ever: no reading, no log line, and eventually the
    system watchdog reboots the node. That is what rst:0x7 (TG0WDT_SYS_RST) in the
    outdoor node's log was -- one in a 15-minute capture, so not frequent, but a
    silent reboot is the worst shape a fault can take.
    100 ms is far beyond anything on this bus. The longest thing any driver asks
    for is a handful of bytes at 100 kHz, and the sensors' conversion waits happen
    between transactions rather than inside them, so a transaction still running
    after 100 ms is not slow,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
    [platform.rs]
2026-09-09 feat: SGP41 driver, and the fleet knows the slot exists
    Two things about this part shape the driver, and both are easy to get
    quietly wrong.
    **It has to be sampled at 1 Hz.** What it returns is a hotplate
    resistance, comparable only while the heater keeps running, and
    Sensirion specifies the index algorithm for a 0.5-10 s interval.
    Sampling it once a minute like the SHT31 would produce a number that
    looks like a VOC index and is not one. So `sample_once` is a single
    1 Hz step the caller drives in a loop and `latest` only reports what
    those steps computed -- which is also why the slot is documented as
    mains-only.
    **The index is not a concentration.** 1..500 against a running ~24 h
    average,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
    [mod.rs, node.rs, sgp41.rs]
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2026-09-09 docs: the terrasse box is 94 mm wide, and the SHT31 has no wall
    The README still described the box the previous commit replaced. Its
    own hardware table and the note about sealing the baffle slots had gone
    in the recent trim, so the insert bore and the reason the envelope grew
    are written into the design bullets instead.
2026-09-09 docs: an address that ACKs while commands NAK means VCC, not the bus
    The outdoor node's SHT31 had a loose VCC wire. The log said so all evening, in
    a form that reads as a contradiction and sent the search in the wrong
    direction:
    WARN - no SHT31-D at 0x44 or 0x45
    INFO - I²C scan: 0x44 answered
    With its supply open the chip still draws a trickle through the ESD diodes on
    SDA and SCL, which sit on the bus pull-ups — enough to run the address
    comparator and ACK, nowhere near enough to execute a command. The scan writes
    zero bytes and passes; the probe writes two command bytes and fails. Everything
    else follows: the spontaneous recovery at 22:36:53 alongside unsteady load-cell
    readin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
2026-09-09 fix: M3 inserts, and the printed floor plate stays the reference
    The inserts are M3, not M4, and one terrasse_floor is already printed.
    That second fact is the constraint: the plate fixes the screw positions
    at (+-36, +-31), the cell's reach at x = 31 and the battery guides at
    y = +-26, so the box goes back to 88 x 78 x 60 and every floor feature
    I had moved goes back where the plate has it.
    `cad-models/terrasse_floor.stl` is byte-identical to the one at
    aa2cd0b, which is the proof that matters here rather than a claim that
    nothing changed.
    What is left of the insert change: a 4 mm bore in a 9 mm post, so
    2.5 mm of wall. Thinner than one would choose. The post cannot be
    centred generously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
    [terrasse_body.step, terrasse_body.stl, terrasse_floor.step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]
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2026-09-10 feat: bound what a stuck or flapping scale may spend on the radio
    The load cell is the only sensor here that can ask for the radio on its
    own schedule, and on 2026-09-09 it asked for all of it. The node's own
    log says why:
    config: offset=8388608 scale=420 threshold=10g idle=2s active=10s
    HX711 raw reading: -179474
    load still on the scale: raw=-179474 delta=21152
    Entering deep sleep for 10s
    21152 ticks against a 4200-tick threshold -- five times over -- from an
    uncalibrated cell whose baseline no longer matches its mechanics. So
    `Staying` every active round, a publish every ten seconds, and ~230
    broker sessions an hour against a design rate of six. The broker log
    holds the shape: 3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
    [main.rs]
2026-09-10 fix: zero the stuck-load counter on a cold boot, and write down how to flash a sleeping node
    Two things from putting the rate limiter on hardware.
    The stuck-load bound fired on the very first boot after the reflash
    that introduced it. Correct behaviour for the state the scale was
    actually in, wrong reason: `PRESENT_ROUNDS` is a `persistent` RTC word
    and the startup code does not initialise those, so a counter just added
    to the firmware starts at whatever was in that slot. An arrival resets
    it, so it self-heals, but a legitimate first visit after a power-up
    would have been misjudged once. Zeroed where a cold boot is already
    being detected. This is the same lesson `state.rs` learned this morn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
    [main.rs]
2026-09-10 fix: a round that does not publish must still reach the heartbeat
    The rate limiter I added an hour ago made the outdoor node mute, and
    only the hardware showed it. The node looked healthy on serial —
    booting, reading the cell, dropping to the idle cadence exactly as the
    new stuck-load bound intends — while the broker log recorded no
    connection from it at all.
    Every arm of the presence match ends in `enter_deep_sleep`, which
    returns `!`, and the periodic heartbeat lives *after* that match. That
    was harmless while `Staying` always published: the node spoke every
    active round whether or not the heartbeat was due. Rate-limiting those
    publishes turned the same control flow into silence, and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
    [main.rs]
2026-09-10 fix: absorb a stuck load into the baseline instead of disbelieving it
    The stuck-load bound worked and then oscillated, which the hardware
    showed within ten minutes of the last fix landing:
    12:47:20 weight -20413.0 visit 60.1
    12:48:46 (+86 s)
    12:51:12 (+146 s)
    12:52:38 (+86 s)
    The rate limit was holding -- every gap over its 60 s -- but the node
    was still managing ~30 publishes an hour against a design rate of six.
    Clearing the presence flag left the load sitting above the threshold, so
    the next round read `Arrived`, which reset the stuck counter and spent
    another 60 s in `watch_visit`. Better than the 230 an hour it started
    at, and still five times too many.
    So the bound now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
    [main.rs]
2026-09-10 fix: publish discovery at QoS1, so the digest records arrival not a write
    Four of the outdoor node's fourteen announcements were simply absent
    from the broker -- `battery_percent`, `scale_factor`, `offset`, `tare`
    -- with nothing anywhere reporting a failure, and the node never
    retrying. Queried individually to be sure: genuinely not there.
    QoS0 is fire-and-forget. `send_message` hands the packet to the socket
    and returns Ok; whether the broker ever saw it is not knowable from the
    node. That is the right trade for a reading the next round replaces,
    and the wrong one for a retained config that nothing will ever send
    again -- because `ok` then stays true, the announcement digest is
    stored on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
    [main.rs]
2026-09-10 feat: a button that forgets the discovery digest
    The digest records what this board *believes* the broker holds, and it
    is stored on the strength of a publish having been sent. When that
    belief is wrong there was no way back: the outdoor node had ten of its
    fourteen announcements on the broker, the digest recording all
    fourteen, and `tare` / `scale_factor` therefore unreachable from Home
    Assistant.
    Nothing available could shake it loose. Power-cycling does not: RTC RAM
    on this board has now twice survived several seconds without power --
    once this morning with the discovery flag, once this afternoon with the
    digest. Changing a tuning knob does not reliably either. And I had
    removed `clear_d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
    [main.rs]
2026-09-10 feat: every node reports its link strength
    A fleet spread across a flat has one failure mode the dashboard could not
    show: a node whose publishes are lost to a weak link. That already happened
    once outdoors -- the 20 s WIFI_BUDGET expiring with no way to report why -- and
    the diagnosis was a guess both times. Now it is a reading.
    Published as `rssi` in dBm with `device_class: signal_strength`, on every node
    and without a `NodeConfig` slot: a node that cannot reach Wi-Fi cannot publish
    at all, so there is nothing to configure. dBm rather than a bar count because
    the number is the measurement, and a node already asleep cannot be asked to
    re-map its scale for whatever draws it.
    Two things abo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
    [main.rs, platform.rs]
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2026-09-11 Bore the climate tray's posts for heat-set inserts
    KL_PILOT goes from 2.5 to 4.0: a self-tapping M3 pilot becomes the hole the
    common brass inserts ask for (4.6 mm outer, going into 4.0).
    KL_POST stays at 8.0, which is the whole constraint. KL_POST_XY is derived from
    it, so widening the post would move all four screws and the already printed lid
    would no longer line up. That leaves 2.0 mm of post wall around the insert --
    thinner than the terrace's 2.5 or the living room's 2.25, and brass expands as
    it goes in, so it is worth checking against the insert in hand before printing
    four.
    The lid is untouched, and provably so: climate_lid.stl is byte-identical
    (9f6bd215…), and a plug probe on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
    [climate_tray.step, climate_tray.stl]
2026-09-12 Move the climate box's screws to the measured centres
    A test fit of the printed pair showed the lid would not sit down. The holes had
    to go 1.0 mm further apart along the length and 1.5 mm across the width, so the
    centres move from (±26.0, ±13.0) to (±26.5, ±13.75) -- 53.0 x 27.5 mm between
    them.
    KL_POST_XY stops being derived from KL_IN_X/KL_POST and becomes measured, the
    same way BOSS_XY is pinned on the terrace box. 1.5 mm on a 26 mm span is 5.7 %,
    which is nowhere near PLA's ~0.3 % shrinkage, so this is not a tolerance to be
    dialled out of the model; it is what the parts in hand actually need.
    Both parts move together, so the screw still enters the insert square. Moving
    only one si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
    [climate_lid.step, climate_lid.stl, climate_tray.step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]
2026-09-12 Narrow the climate tray's insert bore to 3.5 mm
    KL_PILOT goes 4.0 -> 3.5, matching WZ_PILOT. A heat-set insert displaces
    plastic as it melts in, so the hole wants to sit under the insert's outer
    diameter rather than equal to it; 4.0 was the outer diameter itself and would
    have left the brass with nothing to bite.
    It also puts 2.25 mm of post wall back around the insert instead of 2.0, which
    matters more here than on the other boxes: KL_POST cannot grow, because the
    screw centres are pinned by the measured KL_POST_XY.
    The lid does not move -- its clearance holes come from WZ_CLEAR, not from the
    pilot -- and climate_lid.stl is byte-identical across the change. Verified on
    the exported tray: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
    [climate_tray.step, climate_tray.stl]
2026-09-12 fix: the visit counter no longer trusts leftover RTC memory
    The terrace node came up reporting 2,345,324,652 visits. A
    `#[ram(rtc_fast, persistent)]` word is not zeroed by the startup code, so a
    counter that has just been added to the firmware holds whatever was in that
    slot -- and the cold-boot branch I leaned on cannot cover it, because a reflash
    *keeps* RTC RAM. FLASHING.md says so explicitly, and the commit that added the
    counter even cited the same trap biting PRESENT_ROUNDS. I wrote the guard that
    does not apply to the case that actually occurs.
    The count is now stored as a pair: the value, and the value XORed with a magic.
    A read returns zero unless the two agree, so two independent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
    [main.rs]
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2026-09-12 Give the fleet a memory that outlives Home Assistant's
    Home Assistant sees every node the moment it publishes and keeps a recorder
    database, tuned for weeks. The questions this fleet was built for are slower
    than that -- did insulating the roof change the bedroom's overnight CO2, how
    does the terrace swing between summers, is the feeder busier this year than
    last -- and by the time one of them is worth asking, the data it needs is
    already gone.
    `timeseries/` is a second consumer on the same broker whose only job is not to
    lose anything: it follows the topics the nodes already publish, writes each
    reading into QuestDB with a three-year TTL, and serves a small dashboard over
    the result. Nothi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
    [main.rs, mod.rs]
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2026-09-12 Count a visit only once something stayed for a second
    The terrace reported 193 arrivals between 10:00 and 19:31 on 2026-09-12, which
    is more birds than the feeder plausibly saw. The count was not wrong about the
    cell -- the weights published in the busiest hour were 7 to 18 g, which is a
    blue tit through a great tit, and the day stopped dead at 19:31, some twenty
    minutes before sunset. What it was wrong about is what it counted: the rising
    edge. The durations published beside those arrivals included 0.0, 0.1 and 0.3
    seconds, and a bird that is on the cell for a tenth of a second did not visit
    the feeder, it touched it.
    So `count_visit` moves from the edge to after `watch_visit`, gated on th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
    [main.rs, sht31.rs]
2026-09-12 Give the living room the gas sensor its driver was already written for
    `sensors/sgp41.rs` has been in the tree complete -- conditioning, part
    detection, Sensirion's index algorithm, its own tests -- and wired to nothing.
    `Slot::off()` on every node, no field in `Sensors`, no caller. This connects it,
    on the one node that can sample it correctly.
    That qualifier is the whole design. The part returns a hotplate resistance,
    comparable only while the heater keeps running, and the index algorithm is
    specified for a 0.5-10 s interval. Read once a publish round it would produce a
    number that looks like a VOC index and is not one. So `Sensors::step_gas` is a
    single 1 Hz step, and the stay-awake loop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
    [main.rs, node.rs, platform.rs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]
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
